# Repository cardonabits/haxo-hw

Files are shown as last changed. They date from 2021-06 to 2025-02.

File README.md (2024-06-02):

## Table of Contents

<!-- toc -->

- [What is a haxophone](#what-is-a-haxophone)
- [Project Goals](#project-goals)
  * [Goals](#goals)
  * [Non-Goals](#non-goals)
- [How does it work?](#how-does-it-work)
- [Mechanical Design](#mechanical-design)
- [Electrical Design](#electrical-design)
  * [Keyboard](#keyboard)
  * [Audio Amplifier](#audio-amplifier)
  * [Pinout](#pinout)
- [Tools/Stack](#toolsstack)
- [Software](#software)
- [Manufacturing](#manufacturing)
- [Bill of Materials](#bill-of-materials)
- [Assembly Instructions](#assembly-instructions)
- [TODO list](#todo-list)
- [License and Contributions](#license-and-contributions)
- [Acknowledgements](#acknowledgements)

<!-- tocstop -->

## What is a haxophone

A haxophone is an electronic musical instrument that resembles a saxophone.
It is designed to be an inexpensive and fully customizable travel saxophone.
You will never get the same expressiveness or depth of sound of a real
saxophone.  But with a haxophone you should be able to play alone or with
friends wherever you might be.  The mechanical keys and unique ergonomics give
it a different kind of satisfying feel.

https://user-images.githubusercontent.com/676181/133919454-f654cb48-cca9-4b6e-bcb5-27de6ea2deb8.mp4

The design is fully open, software and hardware.  This means that you can make
it your own, from changing the type of key switches to making your own note and
instrument mappings.

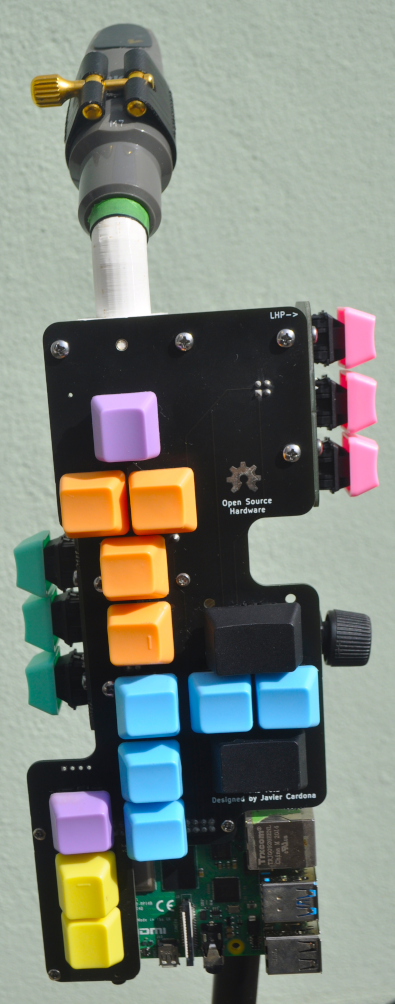
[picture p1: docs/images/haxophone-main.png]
Haxophone Prototype v0.5

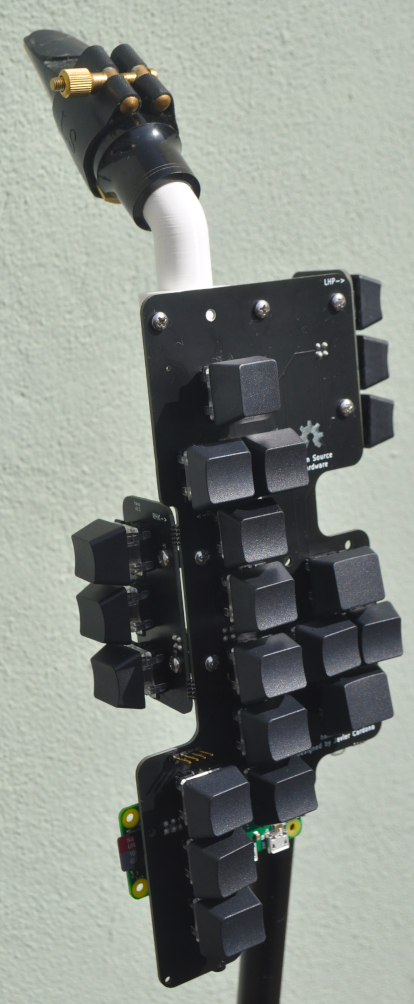
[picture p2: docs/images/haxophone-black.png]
Haxophone Prototype v0.5


## Project Goals

### Goals

1. Build a travel saxophone that is fun and satisfying to play.
2. Build an instrument with the same fingering as a saxophone so that muscle
   memory developed on the haxophone is directly transferrable to your main
horn.
3. Keep the cost low, below $100 USD.
4. Easy to manufacture.
5. Keep the design simple, sturdy and repairable to minimize maintenance cost.
   Using widely available and battle-tested mechanical keys from computer
keyboards is one example of this principle in use.
6. Fully hackable and customizable.

### Non-Goals

1. A haxophone is not designed to be a saxophone replacement.

## How does it work?

The haxophone is designed as a HAT (Hardware Attached on Top) for the Raspberry
Pi family of single-board computers.

The haxophone HAT is a special type of keyboard laid out in the same way as
saxophones are.  It also includes a mouthpiece and a pressure sensor to detect
breath intensity.  The HAT also includes an audio amplifier so it does not rely
on the amplifier that is built into the [Raspberry Pi
3](https://www.raspberrypi.org/products/raspberry-pi-3-model-b-plus/) and
[Raspberry Pi 4](https://www.raspberrypi.org/products/raspberry-pi-4-model-b/).
Because of that, the HAT will also work with the least expensive of the Pi's,
the [Raspberry Pi
Zero](https://www.raspberrypi.org/products/raspberry-pi-zero/).

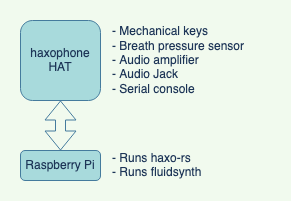
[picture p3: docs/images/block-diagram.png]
Block Diagram


The software that runs on the Raspberry Pi is:

1. [haxo-rs](https://github.com/jcard0na/haxo-rs):  This is the driver that
   detects key presses, breath and converts it into notes.  It's written in
   Rust, and compiled on the Raspberry Pi into a native application.
2. [fluidsynth](https://github.com/FluidSynth/fluidsynth):  This is the
   synthesizer software that will convert notes into sounds.

## Mechanical Design

In order to keep costs down, the HAT PCB (printed circuit board) is an integral
part of the physical structure of the Haxophone.  This means that key switches,
thumb rests, mouthpiece and the Raspberry Pi are all attached directly to the
PCB.  The side keys (left palm and right knuckle keys) are mounted on smaller
PCBs and attached to the main PCB via right angle metal brackets.  This smaller
PCBs are detachable pannels from the design.  This brings down the
manufacturing cost.

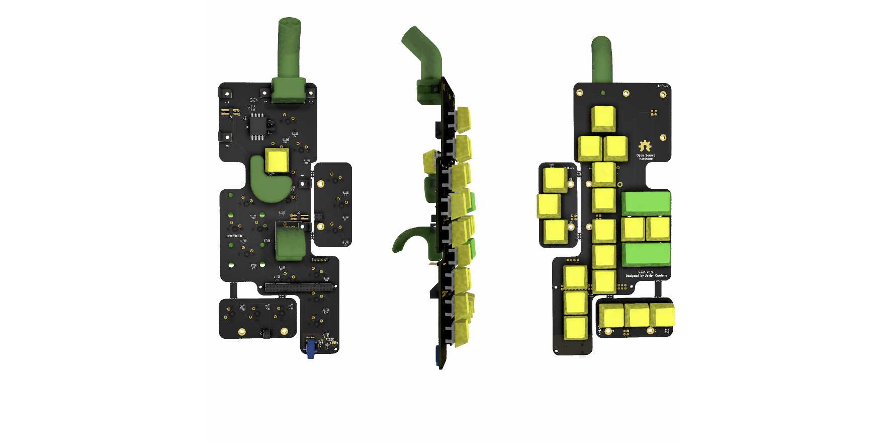
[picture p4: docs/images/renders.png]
renders


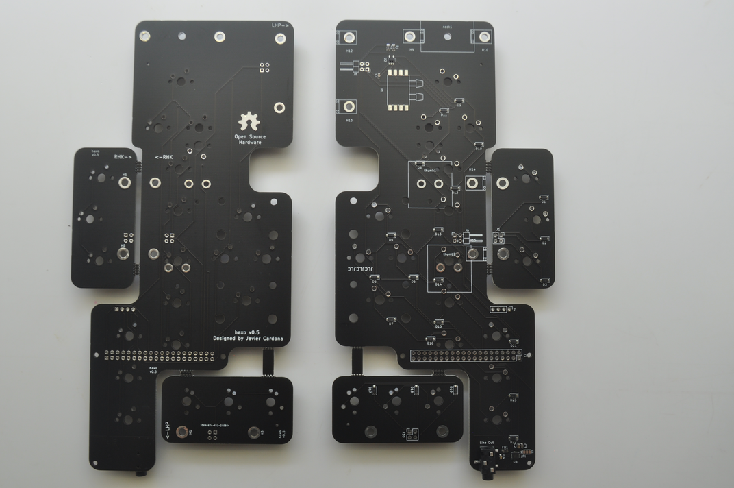
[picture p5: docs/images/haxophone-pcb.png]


For improved ergonomics, a few parts are designed to be 3D printed.  These are
the mouthpiece neck, the left thumb rest, and the right thumb rest, that also
incorporates a strap hook.  The source 3D models for those parts are included
in the repository.

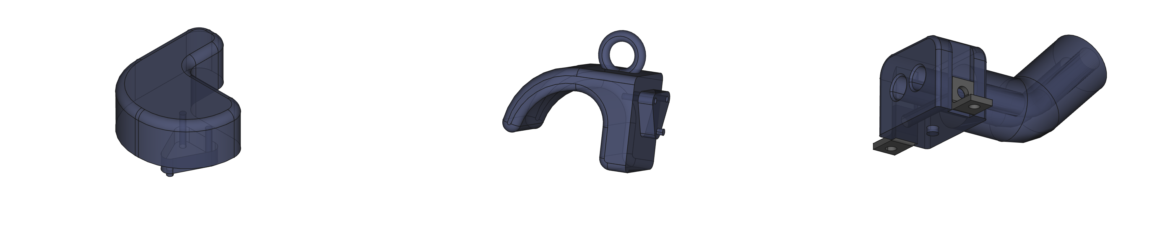
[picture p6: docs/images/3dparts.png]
3dparts


## Electrical Design

The haxophone hat is comprised of three subsystems:  a keyboard, a pressure
sensor and an audio amplifier.

### Keyboard

The keyboard is organized as a 3x8 matrix.  The diagram below shows the mapping
from saxophone keys to keyboard column/row values.

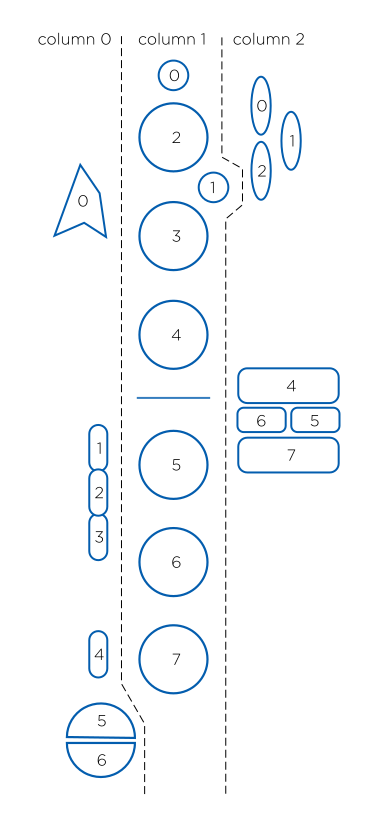
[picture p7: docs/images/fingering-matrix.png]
matrix


Note that due to PCB size constraints, a design decision was made to not
include a high F# key.  This key is not present in all saxophones, as that
note can be played using alternate fingerings with other keys.  The most common
mappings of the high F# are already configured on the haxophone.  If you are
used to a less common configuration, the software is easy to extend.

Also note that at the moment the matrix is not completely used:  keys (col 0,
row 7) and (col 2, row 3) are unused.

### Audio Amplifier

The haxophone HAT includes an audio amplifier and a 3.5mm mini-jack.  This
allows connecting the haxophone to headphones or to an external amplifier.

### Pinout

The diagram below shows how the HAT connects to the Raspberry Pi.  The keyboard
matrix uses discrete GPIOs, the pressure sensor uses I2C and the audio
amplifier, I2S.

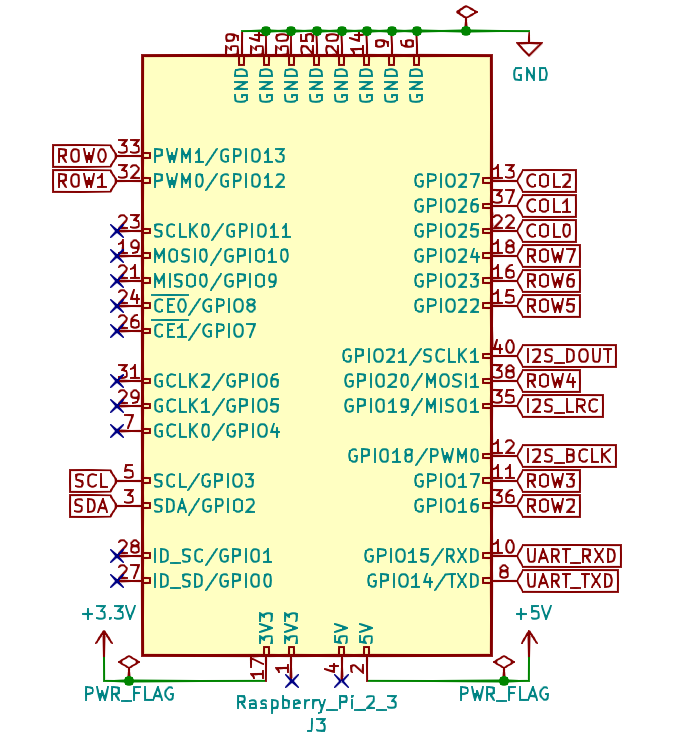
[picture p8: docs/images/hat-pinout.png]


You can refer to the diagram below from Raspberry Pi Spy if you need to locate
those pins on the Raspberry Pi header.


## Tools/Stack

The circuit board is designed with awesome [Kicad](https://www.kicad.org/).

All 3D models are designed with [Freecad](https://www.freecadweb.org/), the
open source 3D parametric modeler.

The code is written in [Rust](https://www.rust-lang.org) just for the pleasure
and reliability of it.

## Software

See [haxo-rs](https://github.com/jcard0na/haxo-rs) for details about the software that runs on all Raspberry Pis.

Alternatively, you can explore [haxo-ino](https://github.com/langeroo/haxo-ino), a port of `haxo-rs` for [RP2040 boards](https://www.waveshare.com/rp2040-pizero.htm).  When using this board the audio port of the Haxophone will be disabled and notes will only be sent out as MIDI.  However, if your intent is to use the Haxophone exclusively as a MIDI Controller, this approach has some advantages:
  * Lower USB latency: while we lack precise data, haxo-ino likely achieves better latency by not running Linux, thereby avoiding the associated USB overhead.
  * Very fast boot: `haxo-ino` boots in less than 2s, which is way faster, than `haxo-rs`, even on the fastest Pi.
  * Better connector:  the rp2040-pizero uses a type-C USB connector, which is just better than Micro USB used on the Pi's.

## Manufacturing

The circuit boards were manufactured by JLPCB, who also assembled the surface mount parts.

## Bill of Materials

The table below shows the main parts required to build a full Haxophone.  Prices are rough estimates based on purchases made for prototypes.  Shipping costs or taxes not included.

| Qty | Part Description | Manufacturer | MPN | Supplier | Estimated cost USD (at quantity 5) |
| :--- | :--- | :---: | :---: |  :---: | ---: |
| 1 | Partially-assembled Haxo HAT PCB (small SMD parts populated) | N/A | N/A | Several  | $15 |
| 1 | Differential pressure SMD sensor | NXP | MPXV7007DP | Arrow |  ~$10~ Post-Covid: $24 |
| 1 | Set of 3D printed parts | N/A | N/A | Several  | $4 |
| 1 | 30cm Food grade Silicon Tube ID:3mm/OD:6mm | JUNZHIDA | N/A | Amazon | $2 |
| 22 | Tactile-feedback 5-pin mechanical switches | Cherry MX | MX-Brown | Banggood | $11 |
| 22 | Keycaps For Mechanical Keyboards | [Many options!](https://esckeyboard.com/) |  | | $10  |
| 2 | 4-pin 0.1in Pin Header Con Right Angle | Samtec | TSW-102-25-T-D-RA | Arrow | $2 |
| 2 | 4-pin 0.1in Pin Socket Con Straight |  TE Connectivity | 215309-2 | Arrow | $2 |
| 1 | 40-pin 0.1in Pin Header Connector | TE Connectivity | 2-535542-0 |  Arrow | $2 |
| 6 | Mounting Bracket L-shape | Keystone | 612 | Mouser | $1.5 |
| 18 | 4-40 1/4 screws and nuts stainless | Keystone | 9900, 4694 | Mouser | $1 |
| 4 | M2/7mm machine screws flat head stainless | Master-Carr | 92010A003 | Master-Carr | $0.5 |
| 3 | 7/16in aluminum spacers | Fascomp | FC1636-440-A | Mouser | $1 |
| 1 | Sax Mouthpiece + Reed | N/A | N/A | N/A | Bring your own (but optional) |
| 1 | Neck Strap | N/A | N/A | N/A | Bring your own (but optional) |
| 1 | Raspberry Pi Zero | Broadcom | Raspberry Pi Zero | Many | $5 |
| 1 | 16 GB SD Card | Many | N/A | Many | $6 |
| ~**Total**~ | | | | | ~**$73**~ (Pre-Covid) |
| **Total** | | | | | **$97** (Post-Covid) |

## Assembly Instructions

See [Assembly Guide](docs/assembly.md)

## TODO list

If you would like to help claim one of [the open issues](https://github.com/jcard0na/haxo-hw/issues) or [create a new one](https://github.com/jcard0na/haxo-hw/issues/new/choose) for yourself.
If you prefer to stay in software land, head out to [the software issues](https://github.com/jcard0na/haxo-rs/issues).

## License and Contributions

See [License](LICENSE).
We'll gladly accept contributions via Pull Requests.  Contributions are
accepted under the same [License](LICENSE) of the project, as captured in
[github's terms of
service](https://docs.github.com/en/github/site-policy/github-terms-of-service#6-contributions-under-repository-license).

If you plan to contribute a major feature or improvement, consider posting your proposed design as an issue before implementing it.

## Acknowledgements

[Ben Gonzales](https://gonzos.net/projects) has been a great source of inspiration and encouragement.  His [midi-Sax](https://gonzos.net/projects/midi-wind-controller-building-my-own/) is a great project worth checking out.

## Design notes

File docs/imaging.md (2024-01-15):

# How to copy a Haxophone image onto an SD Card

If you want the latest and greatest bleeding edge features on your haxophone, you will probably want to build [the software](https://github.com/cardonabits/haxo-rs) yourself.  But some of you just want to get up and running fast.  And for that, we have released Raspberry Pi images with the haxophone application pre-installed.

## Obtain the image

You will find those images at the links below:

* [Raspberry Pi Zero](https://bit.ly/haxo-rpiz)
* [Raspberry Pi Zero 2](https://bit.ly/haxo-rpiz2)
* [Raspberry Pi 3](https://bit.ly/haxo-rpi3)
* [Raspberry Pi 4](https://bit.ly/haxo-rpi4)

## Check the Image (Optional)

Some images (at the moment the Zero and the Zero 2) are zipped and contain a sha256 signature.  This is how you can check the integrity of the image you downloaded.

```
$ unzip haxophone-rpiz2.img.zip 
Archive:  haxophone-rpiz2.img.zip
  inflating: haxophone-rpiz2.img     
  inflating: haxophone-rpiz2.img.sha256  
$ sha256sum -c haxophone-rpiz2.img.sha256 
haxophone-rpiz2.img: OK
```

That OK means the image in your disk matches what was originally released.

## Obtain an SD Card

The images are generated from 16 GB SD cards.  You should be able to flash onto
bigger cards without any modifications.  Smaller cards can also work, but that
will require resizing partitions and other voodoo that's outside the scope of
this guide.

## Flash the image

You can use any image flashing command to copy the image onto your SD card, from [`dd`](https://man7.org/linux/man-pages/man1/dd.1.html), to any disk utility on [Linux](https://gitlab.gnome.org/GNOME/gnome-disk-utility), [Mac](https://support.apple.com/guide/disk-utility/welcome/mac) or [Windows](https://learn.microsoft.com/en-us/windows-server/administration/windows-commands/diskpart)

The folks at Raspberry Pi have released their own SD card imaging tool that can be use for this as well.  The advantage of their tool is that it runs on all three major Operating Systems with the same UI.

To use it, first download and install Raspberry Pi Imager [from here](https://www.raspberrypi.com/software/).

Then, under `Operating System`, select `Custom Image`, then select the `.img` file you downloaded.
Click on `Choose Storage` and pick your SD Card

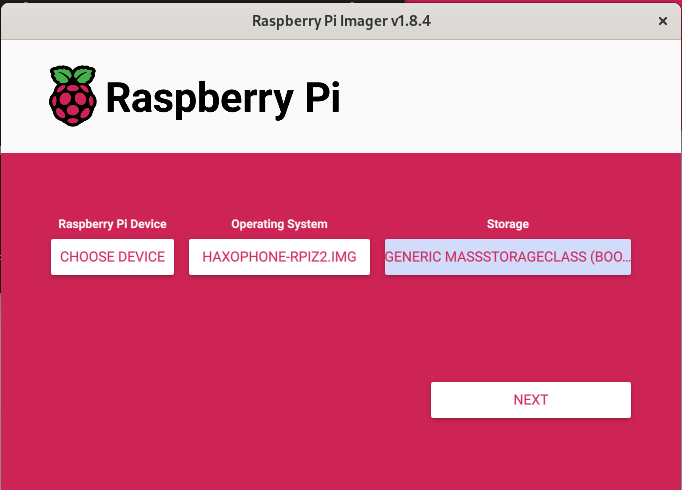
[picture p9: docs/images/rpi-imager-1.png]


Say `No` to any customisations.  **This is important:  your SD Card will not boot correctly if you apply customisations** ([#57](https://github.com/cardonabits/haxo-hw/discussions/59))

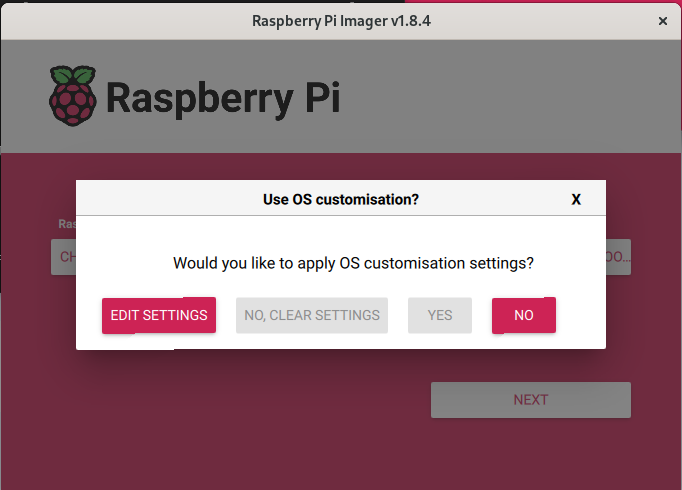
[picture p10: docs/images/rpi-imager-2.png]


Once complete, extract the SD Card.

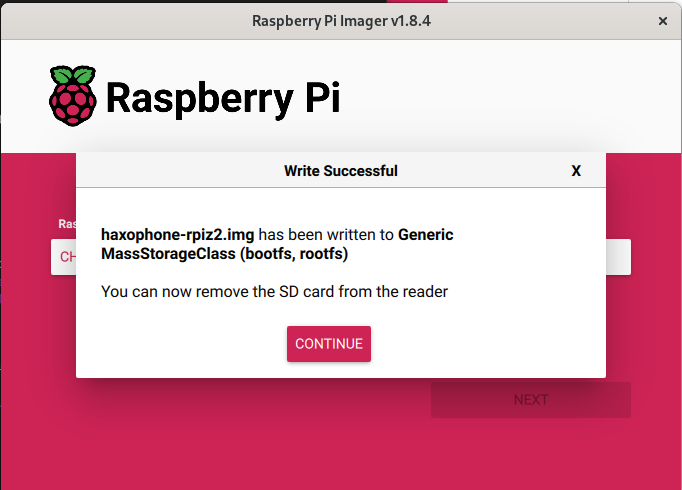
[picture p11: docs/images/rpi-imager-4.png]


If you want to troubleshoot and look at logs, take a look at [how to log into the haxophone](./login.md)

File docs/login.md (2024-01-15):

# Log into your Haxophone

Your haxophone runs on Linux, and sometimes it is necessary (or fun) to just poke inside.
For that you will need to log into your system.  There are three supported ways to do so.

## Monitor and Keyboard

This is probably the method people are most familiar with:  attach a monitor to
the HDMI port of the haxophone, a USB keyboard, and you are in.  On the Zeros,
this normally requires a micro-USB to USB adapter.  This is not the most
portable setup, as not everyone carries a monitor in their pocket.  For more
nimble solutions, keep reading.

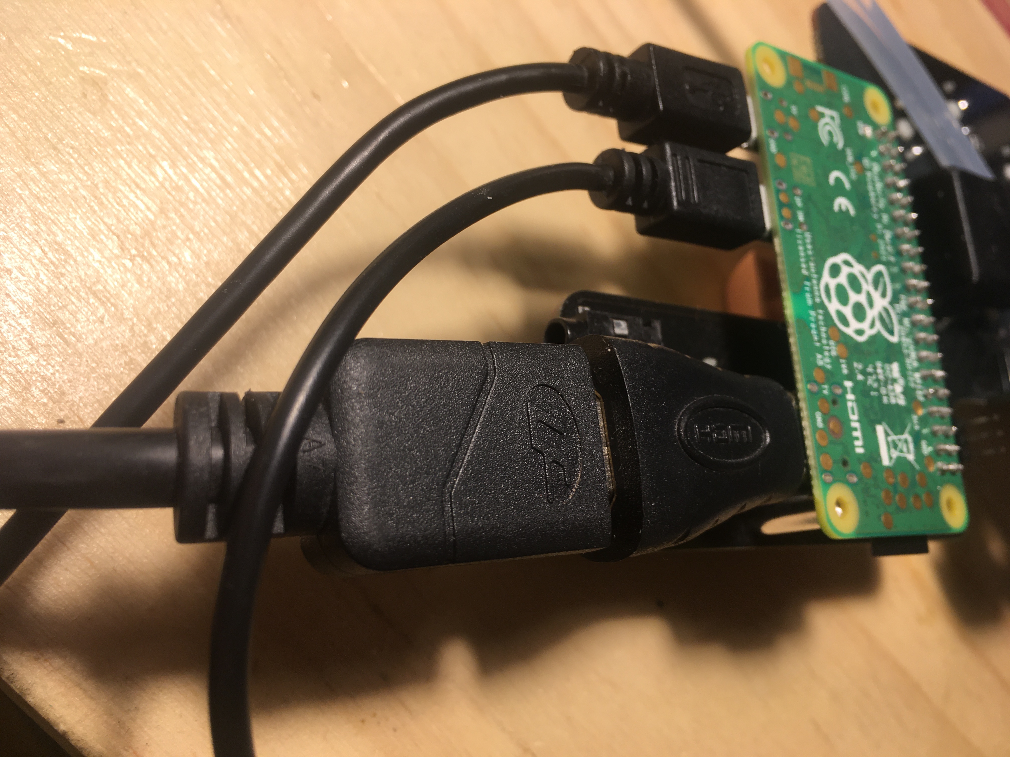
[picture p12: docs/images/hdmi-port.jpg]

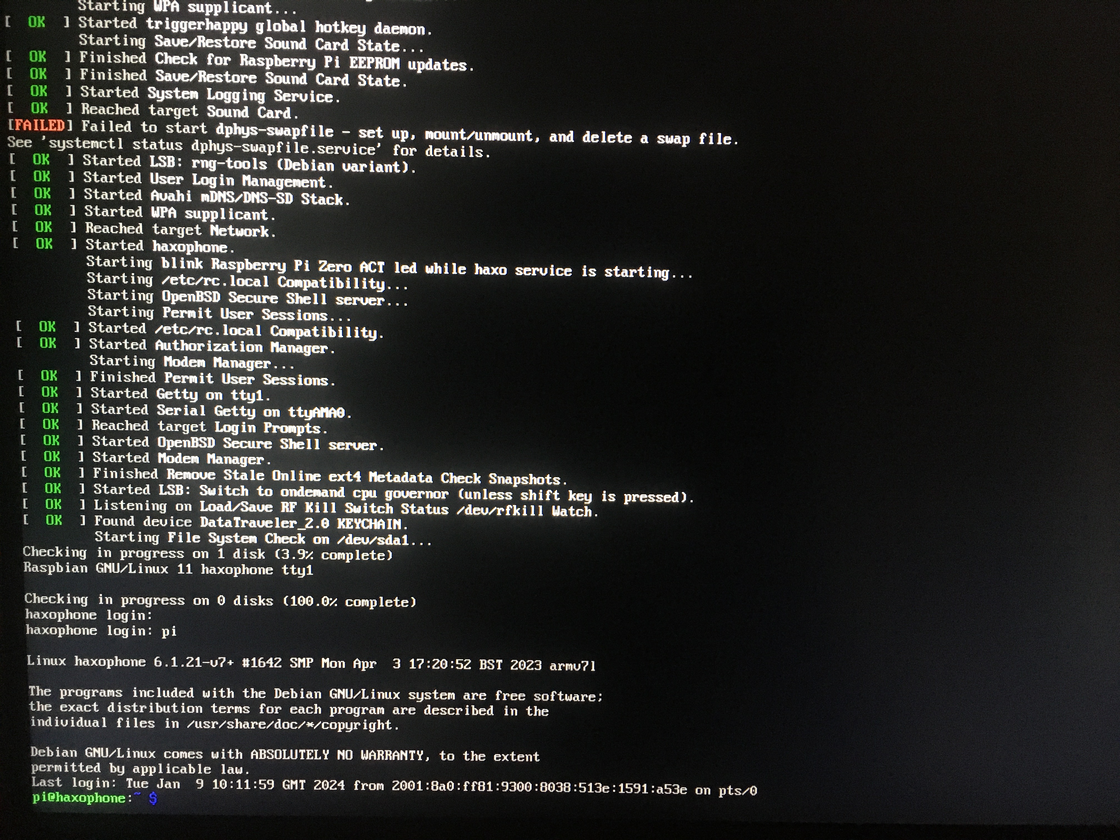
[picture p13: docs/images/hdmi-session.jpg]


## Serial Port

This requires a USB to 3.3V TTL adapter.  The most popular brand is
[FTDI](https://ftdichip.com/products/ttl-232r-3v3/), but there are many other
alternatives you can use.  

The Haxophone has a 3-pin header that exposes the Raspberry Pi serial port.
The pinout matches that of the Raspberry Pi header, so if you prepare a cable
for the Haxophone, you can also use it to connect directly to any Raspberry Pi.

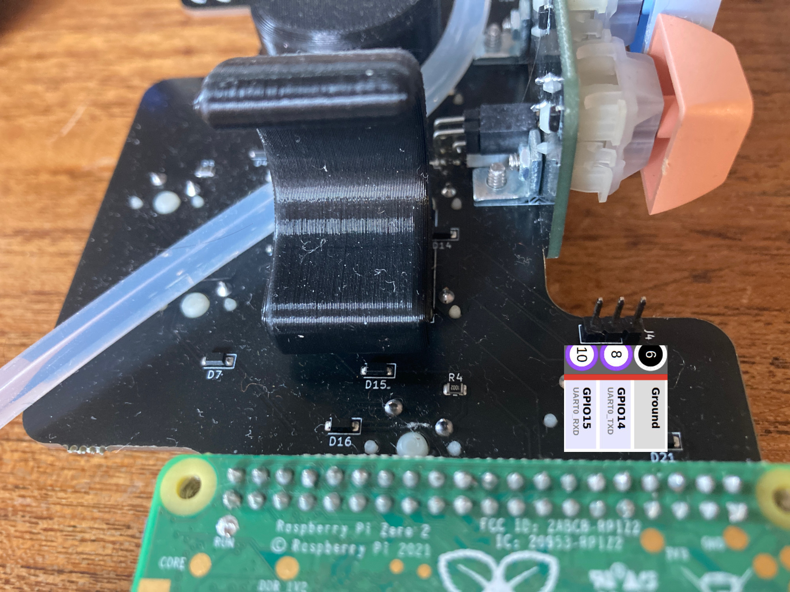
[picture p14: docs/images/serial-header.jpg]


You need to connect your cable's TxD to the Raspberry Pi RxD and your cable's
RxD to the Rasperry Pi TxD.  If you are using an FTDI cable, this is how the
colors line up.

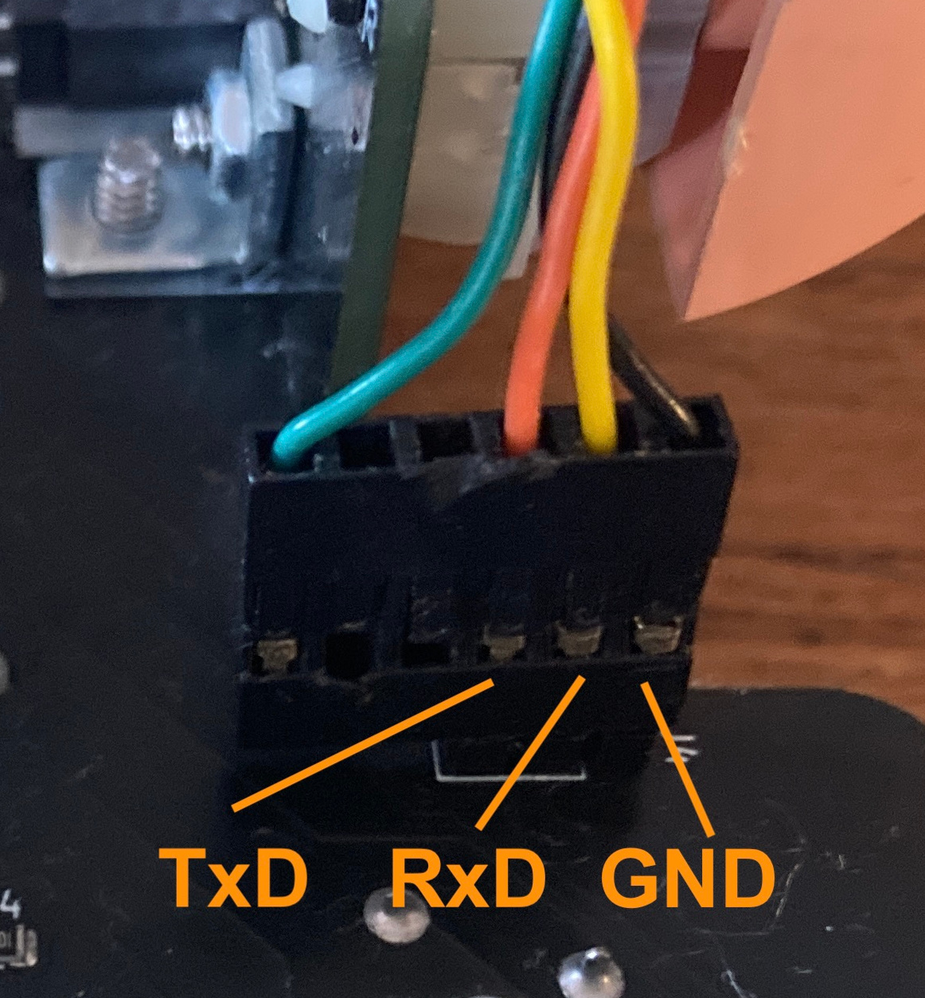
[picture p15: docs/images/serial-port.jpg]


Once you do that, you can use a serial terminal program to connect.  For instance, `minicom`.

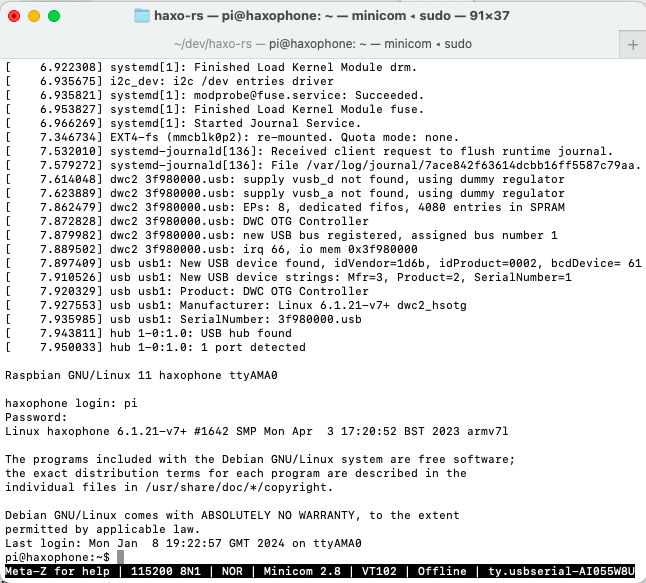
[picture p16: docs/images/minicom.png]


## SSH over Ethernet

The default Haxophone images have WiFi disabled for performance.  WiFi activity
can introduce delays that affect latency while playing.  For that reason, to
connect over SSH, you would need to use Ethernet.  On the Rapsberry Pi Zero,
this means that you will need a serial to Ethernet adapter.

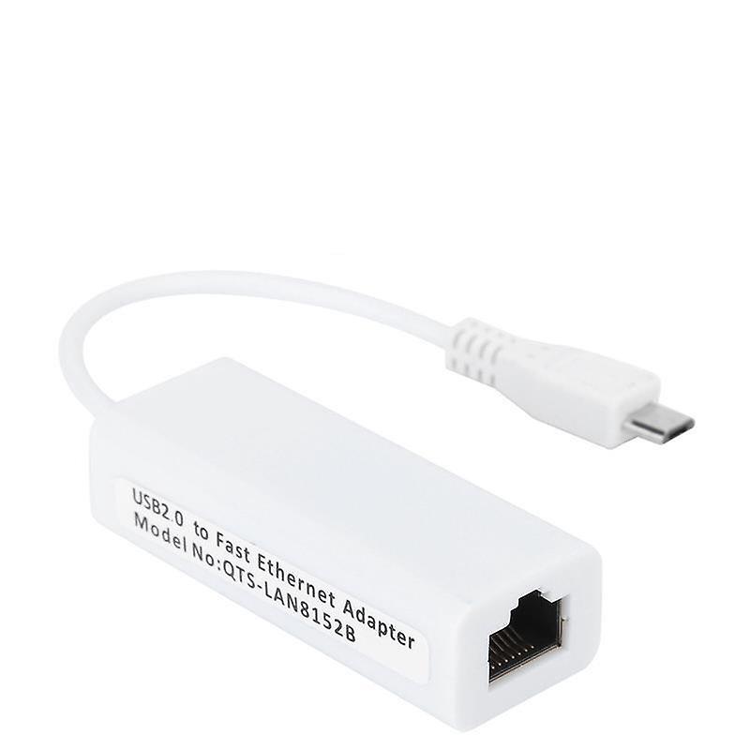
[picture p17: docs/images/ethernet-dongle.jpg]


The haxophone images are configured with username `pi`, password `haxophone` and they will appear on your local network as `haxophone.local`.

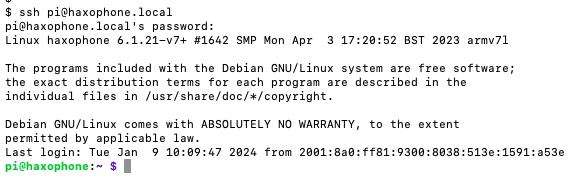
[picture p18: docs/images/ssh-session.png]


## Checking the logs

Probably the most important log that you want to check is the one for the haxophone service.
You can do that with the command `journalctl -u haxo`.  See below for the expected output:

```
pi@haxophone:~ $ journalctl -u haxo
-- Boot 9ecd1d956b6448adb9348f40065fbd4f --
Jan 05 22:38:47 haxophone systemd[1]: Started haxophone.
Jan 05 22:38:52 haxophone create_midi_gadget.sh[468]: created usb midi gadget
Jan 05 22:38:52 haxophone haxo001[570]: fluidsynth: warning: SDL2 not initialized, SDL2 audio driver won't be usable
Jan 05 22:38:52 haxophone haxo001[570]: [2024-01-05T22:38:52Z INFO  haxo001::alsa] Found alsa card MAX98357A
Jan 05 22:39:01 haxophone haxo001[570]: Synth created
Jan 05 22:39:02 haxophone haxo001[570]: [2024-01-05T22:39:02Z INFO  haxo001::midi]
Jan 05 22:39:02 haxophone haxo001[570]:     Available output ports:
Jan 05 22:39:02 haxophone haxo001[570]: [2024-01-05T22:39:02Z INFO  haxo001::midi] 0: Midi Through:Midi Through Port->
Jan 05 22:39:02 haxophone haxo001[570]: [2024-01-05T22:39:02Z INFO  haxo001::midi] 1: f_midi:f_midi 24:0
Jan 05 22:39:02 haxophone haxo001[570]: [2024-01-05T22:39:02Z INFO  haxo001::midi] Picked the last one
Jan 05 22:39:02 haxophone haxo001[570]: Starting haxophone (version 2493652)...
```

## Conclusion

How many other instruments give you so many ways to peek inside see their internals? You should dive in! 🤿

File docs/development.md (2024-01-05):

# Development Environment

## Contents

<!-- toc -->

- [Introduction](#introduction)
- [Setup](#setup)
- [Hardware](#hardware)
- [Initial Configuration](#initial-configuration)
- [Compilation Method 1: Native Compilation on the Raspi](#compilation-method-1-native-compilation-on-the-raspi)
- [Compilation Method 2: Cross-compilation on your computer](#compilation-method-2-cross-compilation-on-your-computer)
  * [Normal cross-compilation](#normal-cross-compilation)
  * [Cross-compilation with `cross` [BROKEN]](#cross-compilation-with-cross-broken)
- [Installation and launch](#installation-and-launch)
- [Logs](#logs)

<!-- tocstop -->

## Introduction

If you want to modify the software that runs on a Haxophone, you will need to
setup a development environment.  There are many different options on how to do
that, here I document a few different approaches I tried with different levels
of success.

## Setup

The first step is that you will need a way to connect your Raspberry Pi to your computer.

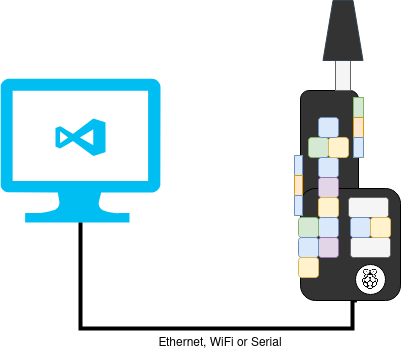
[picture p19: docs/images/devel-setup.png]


On the Raspberry Pi 3/4, this can be Wi-Fi or Ethernet.  On the Pi Zero W,
Wi-Fi.  On the Pi Zero, you will need an USB network adapter.  

If you don't have a network around, you can also use a serial console.  The
Haxophone HAT exposes the serial console signals on connector J4.  The pins
match the same pinout as pins 6,8,10 on the Raspberry Pi Header.  So, if you
had a tty serial cable that worked on the PI, it will also work on the J4
connector when the HAT is attached.  Note that the [serial console will not
work if Bluetooth is enabled on the
Raspi](https://di-marco.net/blog/it/2020-06-06-raspberry_pi_3_4_and_0_w_serial_port_usage/),
so you *probably do not want to use the serial console afterall*.

For the next sections, we will assume that you are able to get a Linux prompt
on the Raspberry Pi.  For additional help, you can refer to [Raspberry Pi
documentation](https://www.raspberrypi.com/documentation/computers/remote-access.html)

## Hardware

Highly recommended:  use a USB drive for your development and keep your SD Card
read-only most of the time.

## Initial Configuration

1. Flash [image onto Raspberry Pi](https://www.raspberrypi.com/news/raspberry-pi-imager-imaging-utility/).  For faster boot, use the Lite version of the OS (no graphical environment)
2. Pick SSH password.
3. Pick a network-unique hostname (`/etc/hostname`).
4. On raspi-config, enable: `ssh`, `I2C` and (optional) `serial console`
5. [RP Zero Only] Enable device-mode USB driver  (edit `/boot/config.txt` to add)
   ```
   [all]
   dtoverlay=dwc2
   ```
   and add `dwc2` to `/etc/modules`
6. Enable audio card (edit `/boot/config.txt` to add)
    ```
    # dtparam=audio=on
    dtoverlay=max98357a,sdmode-pin=4
    ```
7. Optionally, disable Wifi and Bluetooth.  This seems to improve performance on the RPI Zero.
   ```
   dtoverlay=disable-wifi
   dtoverlay=disable-bt
   ```
9. Speed up I2C (edit `/boot/config.txt` to add)
    ```
    dtparam=i2c_arm_baudrate=400000
    ```
10. Install project dependencies
    ```
    apt install libfluidsynth-dev git libasound2-dev i2c-tools fluid-soundfont-gm
    ```
11. Install latest stable Rust
    ```
    curl --proto '=https' --tlsv1.2 -sSf https://sh.rustup.rs | sh
    ```

    Note 1: On Raspberry Pi 4 rustup might detect an incorrect architecture.  The RPi 3/4 can run in 32-bit or 64-bit.
    Check `uname -m` to see whether you are running `aarch64` or `armv7l`.  If the later, when installing rust:
    ```
    Current installation options:

    default host triple: aarch64-unknown-linux-gnu
    This is incorrect --------^^^^^^^
    ```

    To fix, pick '2. Customize installation' and set host to:
    ```
    arm-unknown-linux-gnueabihf
    ```
    See [this issue](https://github.com/rust-lang/rustup/issues/3342).

    Note 2: On Pi Zeros you might need to increase the size of the swap file or else the installation will be killed by insufficient ram.  You do this by:
    ```
    sudo dphys-swapfile swapoff
    sudo vi /etc/dphys-swapfile
    # Change CONF_SWAPSIZE=100 to CONF_SWAPSIZE=512
    sudo dphys-swapfile setup
    sudo dphys-swapfile swapon
    reboot
    ```
13. Automount USB drive, if attached
    ```
    sudo mkdir /media/usb
    # for FAT32 formatted drive
    echo '/dev/sda1       /media/usb        vfat    defaults,nofail,uid=1000,gid=1000        0 2' >> /etc/fstab
    # for Linux formatted drive
    echo '/dev/sda1       /media/usb        ext4    defaults,nofail        0 2' >> /etc/fstab         
    ```

    Gotcha: If you created the USB partition with e2fsck 1.47, you might encounter [this problem](https://github.com/NixOS/nixpkgs/issues/229450#issuecomment-1616324269).  Avoid it by creating your partition from Raspberry Pi (e.g. `sudo mkfs -t ext4 /dev/sda1`)

14. [If using VSCode] Connect via VSCode over ssh to target.  This will create folder `/home/pi/.vscode-server`. Move that folder to `/media/usb/`

15. [If using VSCode] Symlink `.vscode-server` directory to USB drive.
    ```
    ln -sf /media/usb/.vscode-server /home/pi
    ```
    (This is a workaround for VSCode [issue that requires a writable directory under the user's home directory](https://github.com/microsoft/vscode-remote-release/issues/472)).

16. [Highly recommended] Make SD Card read-only

    The SD Card may get corrupted if the Raspberry PI is unplugged while a
    write operation is in progress.  In normal operation, one cannot know if a
    write is happening before powering off, so a radical solution is to forbid
    all writes.  You can do this easily from `raspi-config`:

    ```
    sudo raspi-config
    Performance Options -> Overlay Filesystem -> Enable Overlay? Yes -> Make Boot Filesystem Writeable? Yes
    ```
    The overlay filesystem will make your root filesystem writable but only in
    a non-persistent way.  In other words, you may write files to, say, `/home/pi`,
    but they will disappear after a reboot.

    Reverse this steps if you need to make the filesystem writable again, for
    instance if you need to copy new versions of `haxo001` to the root fs or
    install new packages.

## Compilation Method 1: Native Compilation on the Raspi 

This works very well on a Raspberry Pi 3 and 4, but it is very slow on the Pi Zero.
If you configured the Raspberry Pi image as described in the previous section,
compilation is easy:

1. Insert a USB drive and reboot.  It should auto-mount under `/media/usb`
2. Install keys (under `/media/usb`, not the SD card) and load them
   ```
   ssh-agent bash
   ssh-add id_ed25519
   ```
3. Clone `haxo-rs` on the USB drive
    ```
    cd /media/usb
    git clone git@github.com:cardonabits/haxo-rs.git
    ```
4. If you plan to make changes to the code and submit pull requests, configure `git`
    ```
    cd haxo-rs
    git config --local user.email my@email.com
    git config --local user.name "My Name"
    git config --local core.editor vim
    ```
5. Compile
    ```
    cargo build --release
    ```
6. Only one `haxo` daemon can be running at a time.  Before running your build,
   you might need to stop the pre-installed daemon if it was launched at boot.
    ```
   systemctl stop haxo
   ```
7. Run the tests
   ```
   cargo test -- --test-threads=1
   ```

8. [Optional] Run the interactive tests
   ```
   cargo test all_keys -- --nocapture --ignored
   ```

## Compilation Method 2: Cross-compilation on your computer

With this method, we will cross-compile binaries.  This means, you will compile
on your laptop binary executables for a different architecture.  This method is
recommended if you are building images for the Pi Zero, as native compilation
is too slow.

### Normal cross-compilation

The process outlined
[here](https://chacin.dev/blog/cross-compiling-rust-for-the-raspberry-pi/), but
I mostly develop on the Pi 4, so native compilation for me is preferred.

### Cross-compilation with `cross` [BROKEN]

By using a Docker container we can run this method without having to install
special packages on your system.  It will also work independently of your
Operating System.

Using [cross](https://github.com/rust-embedded/cross), build haxo-rs for target `arm-unknown-linux-gnueabihf`
You first need to create a container with `libfluidsynth` installed and add lib
path to `build.rs`.  But compilation fails due to uresolved symbols provided by
fluidsynth dependent shared libs

Also a problem: `cross` has [an issue with targetting the Pi zero](https://github.com/rust-embedded/cross/issues/426)

## Installation and launch

The `haxo` daemon is launched by systemd.  If you need to install a new version, you need to copy the binary to where systemd expects it.

1. Disable overlay (if previously enabled)
2. Copy `target/release/haxo001` to `/usr/local/bin/haxo001`
3. Install systemctl service files
    ```
    cd scripts/systemd
    sudo ./install.sh
    ```
4. Re-enable overlay

If you need to modify how systemd launches the `haxo` daemon, you will need to
edit `/etc/systemd/system/haxo.service`:

```
[Unit]
Description=haxophone
After=network.target
StartLimitIntervalSec=0

[Service]
Type=idle
Restart=always
RestartSec=1
User=root
Group=audio
WorkingDir=/usr/share/haxo
Environment=RUST_LOG=info
ExecStart=/usr/local/bin/haxo001 \
          --notemap-file /usr/share/haxo/notemap.json \
          --bank-number 66 \
          --sf2-file /usr/share/sounds/sf2/TimGM6mb.sf2

[Install]
WantedBy=multi-user.target
```

## Logs
You can inspect logs with
```
journalctl -u haxo
Oct 11 17:11:17 raspberrypi-one haxo001[641]: Synth created
Oct 11 17:11:17 raspberrypi-one haxo001[641]: Starting haxophone...
```

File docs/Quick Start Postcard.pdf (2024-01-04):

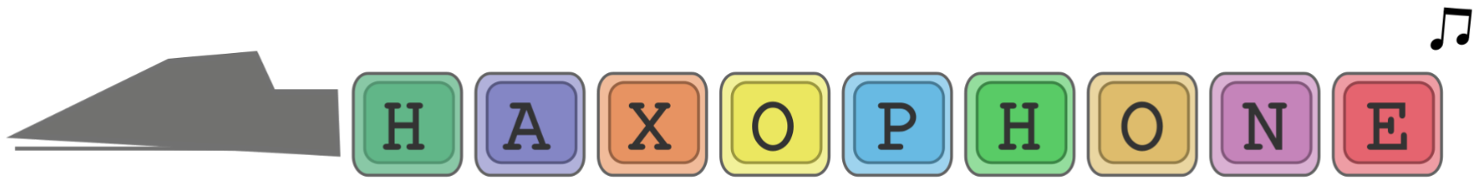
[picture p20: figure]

# Quick Start Guide

1. Download Software Image
Raspberry Pi Zero/Zero W: https://bit.ly/haxo-rpiz Raspberry Pi 4: https://bit.ly/haxo-rpi4
Raspberry Pi 3: https://bit.ly/haxo-rpi3
2. Download Raspberry Pi Imager from here: https://www.raspberrypi.com/software/
3. Use Raspberry Pi Imager software to copy the software image onto a 16 GB SD Card
4. Insert SD Card into Raspberry Pi
5. Attach Raspberry Pi to Haxophone
6. Optionally attach a mouthpiece. You may use the attached washi tape roll to adjust the neck diameter to your mouthpiece.
6. Power Up and wait for the LED to stop blinking (about 1 minute)
7. Play!

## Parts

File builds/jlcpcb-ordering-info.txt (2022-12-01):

PCB Product Detail
==================

Gerber file: haxophone001-1.0_Y64
Build Time: 3 days
Base Material: FR-4
Layers: 2
Dimension: 102.36 mm* 207.26 mm
PCB Qty: 5
Product Type: Industrial/Consumer electronics
Different Design: 3
Delivery Format: Panel by Customer
PCB Thickness: 1.6
Impedance Control: no
PCB Color: Black
Silkscreen: White
Via Covering: Tented
Surface Finish: LeadFree HASL
Deburring/Edge rounding: No
Outer Copper Weight: 1
Gold Fingers: No
Flying Probe Test:Fully Test
Castellated Holes:no
Remove Order Number:No
4-Wire Kelvin Test:No
Material Type:FR4-Standard TG 135-140
Paper between PCBs:No
Appearance Quality:IPC Class 2 Standard
Confirm Production file:Yes
Silkscreen Technology:Ink-jet/Screen Printing Silkscreen
X-out board:Accept
Package Box:With JLCPCB logo
Date: Dec 1 2022
PCB price (qty 5): 20.71 EUR (excl. shipping + tax)

Assembly Detail
===============

Bottom Side
PCBA QTY: 5
Tooling holes: Added by JLCPCB
Confirm Parts Placement：Yes
File provided as: Complete File, just proceed with my own files
Panel Format: 1*1
Assembyl + Parts price (qty 5): 189.79 EUR (excl. shipping + tax)

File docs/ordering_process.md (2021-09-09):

## Preparing fabrication files for JLCPCB

To prepare files for JLCPBC

1. Generate BOM from kicad
  1. (One time) Add BOM plugin from `scripts/bom2grouped\_jlcpcb.xsl` to kicad BOM tool.
  2. Use that plugin to generate BOM.  This will have JLCPCB part numbers.
2. Generate gerbers from kicad
3. Generate position files from kicad, *in CSV format*
  1. Post-process `haxophone001-bottom-pos.csv` with  `scripts/jlcpcb-pos-csp-process.sh` to make it JLCPCB compatible.  Only the bottom position file is needed as only the bottom side of the PCB is populated.
4. Zip the `gerbers` directory.

The files required to place the order are:

1. zipped gerbers
2. BOM file: `haxophone001.csv`
3. CPL file: `haxophone001-bottom-pos.csv`

Also, in the order form, set 'Different Designs' to 3.
Also, pick LeadFree or ENIG Surface Finishes.

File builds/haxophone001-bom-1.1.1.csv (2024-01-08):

Comment | Designator | Footprint | LCSC
470pF | C1 | Capacitor_SMD:C_0603_1608Metric | C1620
0.1uF | C2 | Capacitor_SMD:C_0603_1608Metric | C28323
10uF | C3 | Capacitor_SMD:C_0603_1608Metric | C96446
220pF | C4 | Capacitor_SMD:C_0603_1608Metric | C1603
D_Small | D1,D2,D3,D4,D5,D6,D7,D8,D9,D10,D11,D12,D13,D14,D15,D16,D17,D18,D19,D21,D22,D23 | Diode_SMD:D_SOD-123 | C8598
600 | FB1 | Inductor_SMD:L_0805_2012Metric | C1017
Raspberry_Pi_2_3 | J3 | Connector_PinSocket_2.54mm:PinSocket_2x20_P2.54mm_Vertical | C132132
Conn_01x03_Male | J4 | Connector_PinHeader_2.54mm:PinHeader_1x03_P2.54mm_Vertical
Line Out | J5 | haxo001:C18594 | C18594
4.7K | R1,R2 | Resistor_SMD:R_0805_2012Metric_Pad1.20x1.40mm_HandSolder | C17673
10K | R3,R4,R5 | Resistor_SMD:R_0805_2012Metric | C17414
MCP3221 | U2 | Package_TO_SOT_SMD:SOT-23-5_HandSoldering | C36310
MAX98357 | U4 | Package_DFN_QFN:TQFN-16-1EP_3x3mm_P0.5mm_EP1.23x1.23mm_ThermalVias | C910544

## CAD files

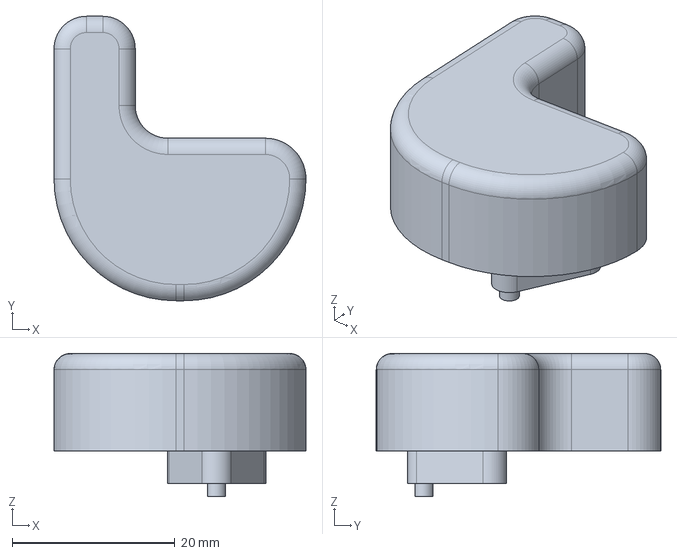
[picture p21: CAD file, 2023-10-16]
models/octave_rest.FCStd
31.0 x 35.0 x 17.6 mm

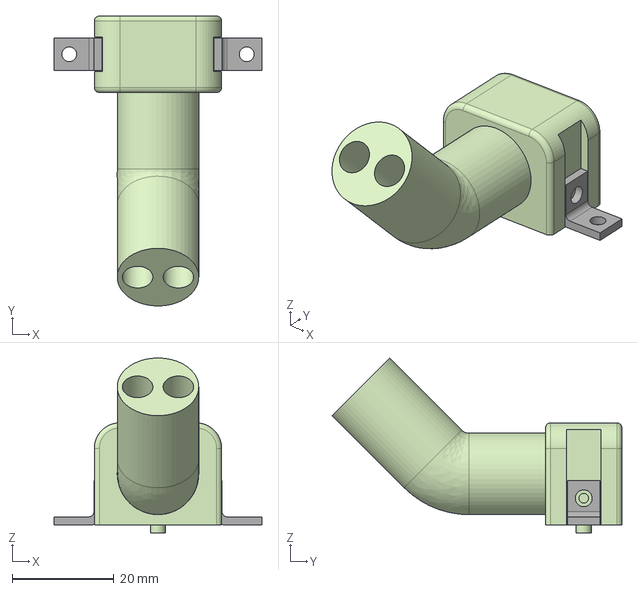
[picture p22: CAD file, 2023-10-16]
models/neck.FCStd
40.8 x 56.9 x 34.3 mm
lbracket x 2
neck001

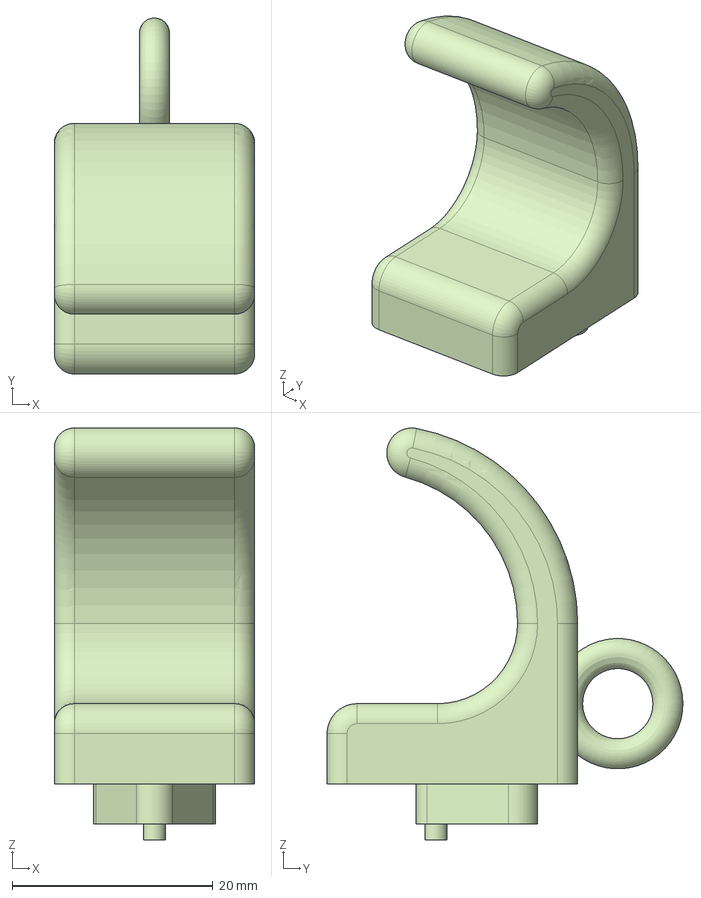
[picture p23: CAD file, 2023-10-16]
models/hook_rest.FCStd
20.0 x 35.5 x 41.1 mm

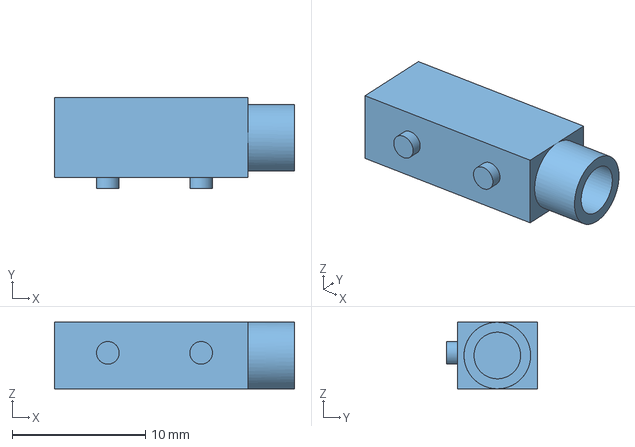
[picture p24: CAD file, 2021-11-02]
models/PJ-3280-B-SMT-Part.step
18.0 x 6.80 x 5.00 mm

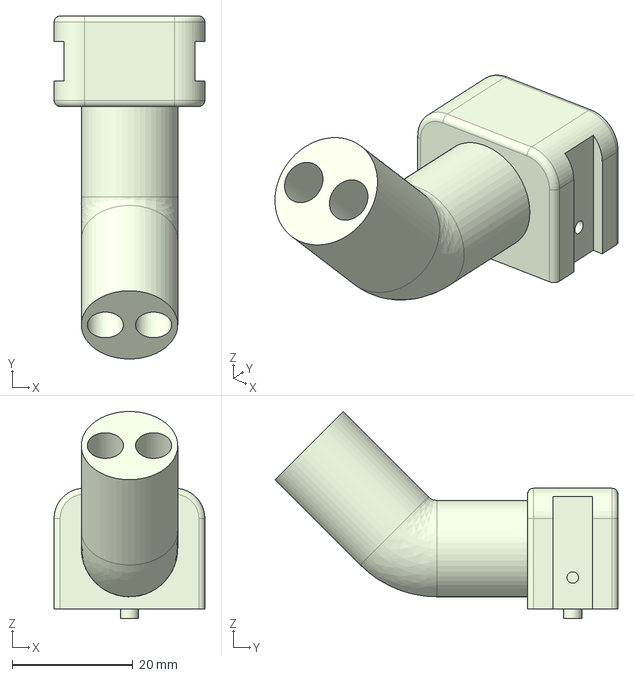
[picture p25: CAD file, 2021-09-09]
models/neck-neck.step
25.0 x 56.9 x 34.3 mm

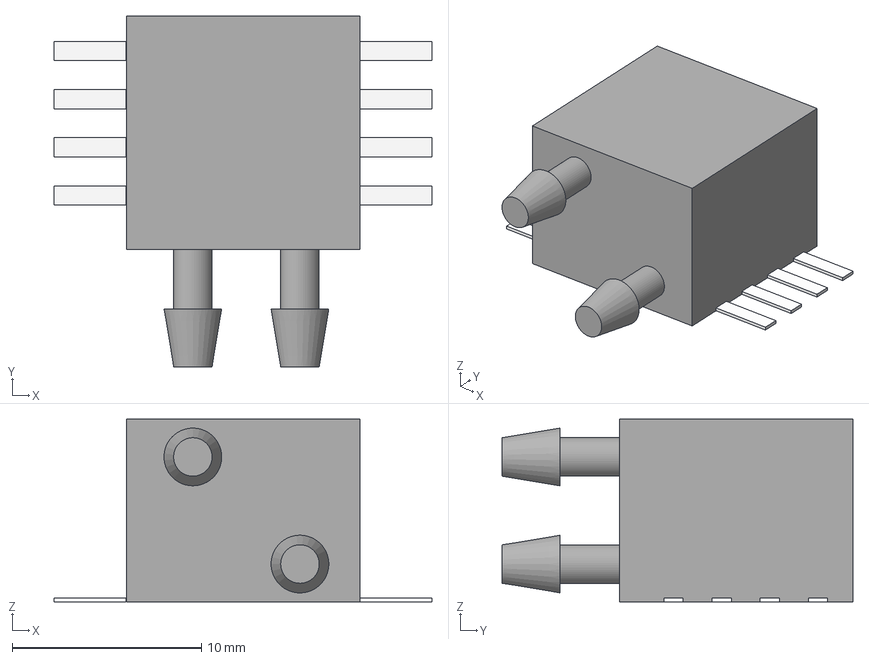
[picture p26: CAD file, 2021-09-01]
models/mpxv7007-Part.step
19.9 x 18.5 x 9.65 mm
Pads

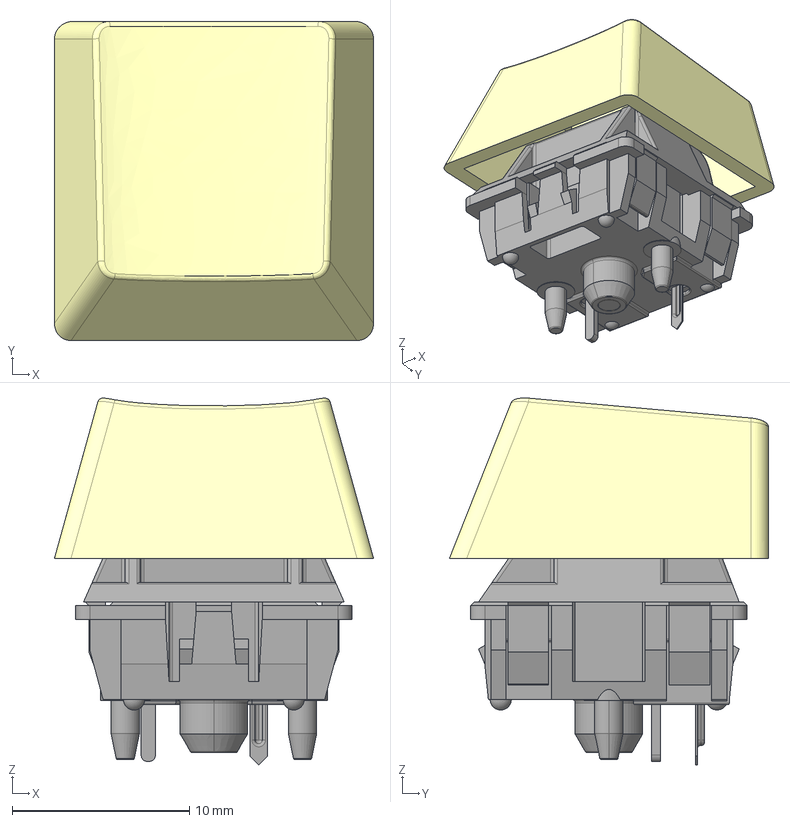
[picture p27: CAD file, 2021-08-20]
models/cherry-mx-with-keycap.FCStd
18.0 x 18.0 x 20.7 mm
SW_Cherry_MX_PCB_cp
1x1 R2 v8

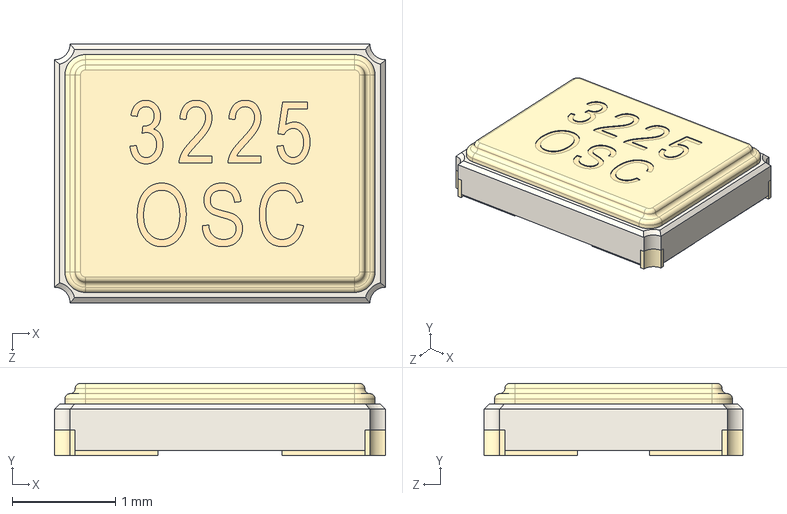
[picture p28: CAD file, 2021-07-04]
models/3225 SMD Crystal Oscillator.STEP
3.20 x 0.7 x 2.50 mm

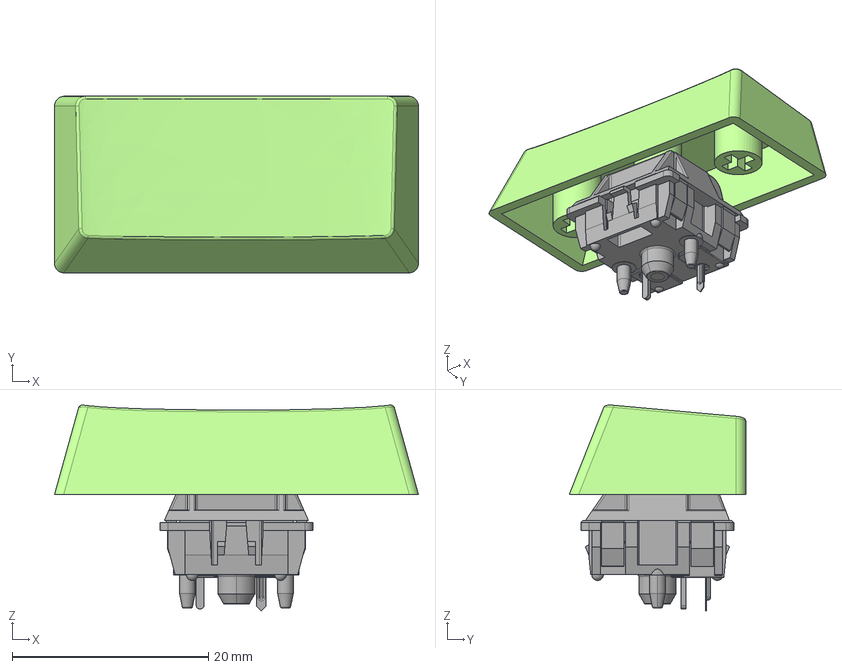
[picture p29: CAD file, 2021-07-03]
models/cherry-mx-with-2U-keycap.FCStd
37.1 x 18.0 x 21.0 mm
SW_Cherry_MX_PCB_cp
1x2 R2 v6

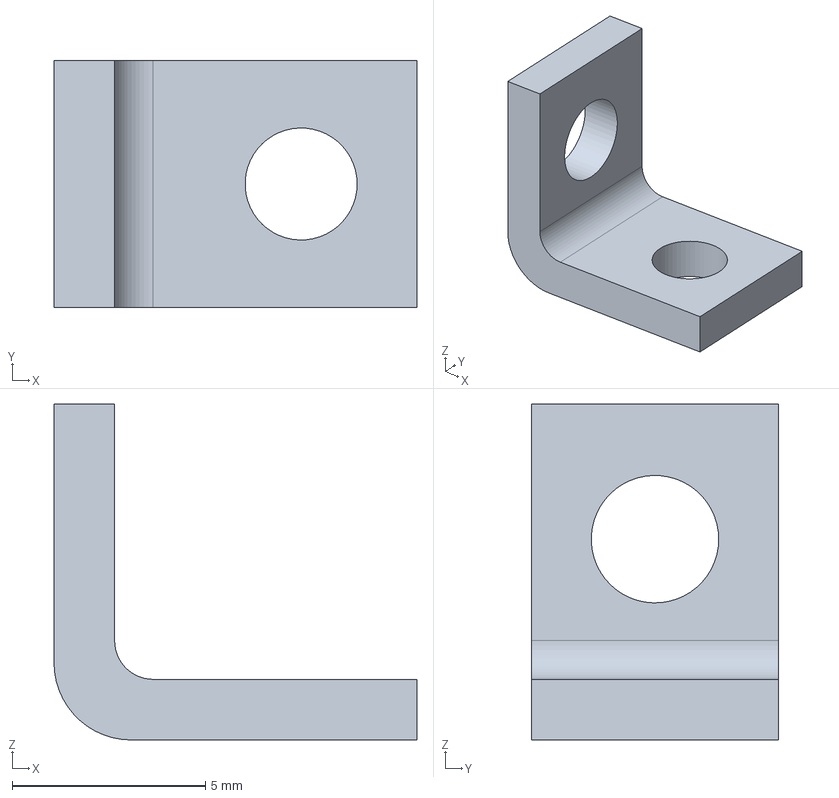
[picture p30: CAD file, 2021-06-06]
models/lbracket-PartBody.step
9.40 x 6.40 x 8.70 mm

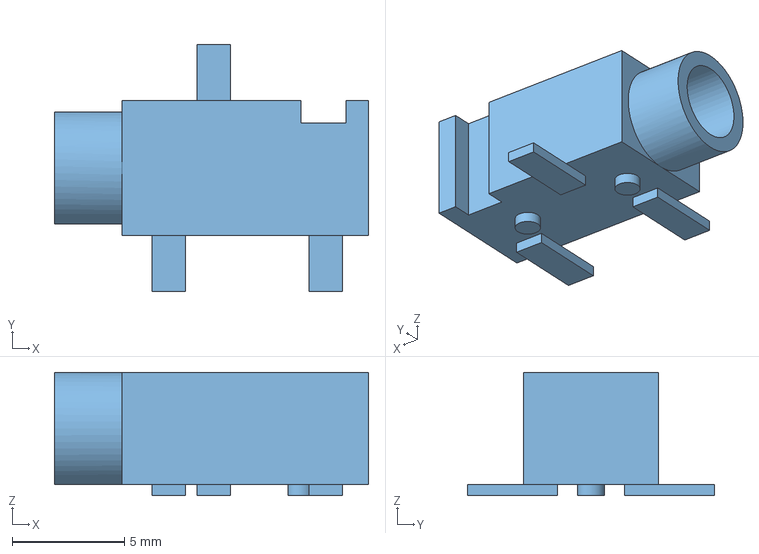
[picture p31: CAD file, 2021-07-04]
models/C18166.FCStd
14.0 x 11.0 x 5.50 mm

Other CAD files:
models/PJ-3280-B-SMT.FCStd
models/hook_rest-Part.step
models/octave_rest-Part.step
models/mpxv7007.FCStd
models/lbracket.FCStd
models/C18166-Part.step
models/hook_rest-Part.stl
models/neck-neck.stl
models/octave_rest-Part.stl

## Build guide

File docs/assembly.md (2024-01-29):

# Assembly Instructions

## Requirements

To assemble a haxophone you will need the following parts:

* 1x partially assembled PCB, with the surface mount parts populated
* 1x Surface mount pressure sensor
* 1x 40-positions female connector
* 2x Right-angle 4-positions male connector
* 2x Straight 4-positions female connector
* 18x 4-40 1/4 inch stainless steel screws
* 4x 4-40 nuts
* 4x M2 flat head phillips 7mm stainless steel machine screws
* 6x L-shape brackets
* 3x 7/16in aluminum spacers
* 30cm silicon tube ID:2mm, OD:6mm
* 1x 3D printed neck
* 2x 3D printed thumb rests
* [Acrylic Conformal Coating](https://www.mgchemicals.com/downloads/tds/tds-419d-l.pdf)

You will use the following tools:

* Soldering iron and solder
* Phillips screwdriver
* Side-cutting pliers

It is also convenient to have:
* Needle nose pliers
* Alcohol and Q-tips

## Conventions

The PCB side with the Open Source Hardware logo is the front.
The opposite side, with the SMD components is the back.
The 40-pos connector area is the bottom, and the area of the neck is the top.

The PCB is comprised of 3 panels.  The larger one is the main panel, the other
two are side panels.  The side panel labelled RHK, is the Right Hand Knuckle or
Right panel.  The side panel labelled LHP is the Left Hand Palm or Left panel.

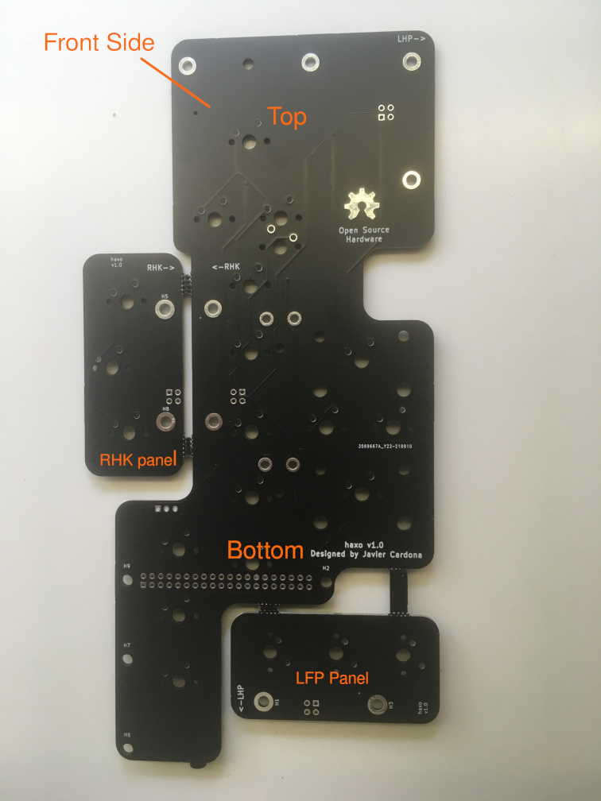
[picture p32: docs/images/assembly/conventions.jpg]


## General advice

* When soldering ensure all flux is thoroughly cleaned, as it may create leakage paths between circuit nodes.  The weak pull-up resistors of the Raspberry Pi make the keyboard matrix very sensitive to leakage paths.

## Assembly steps

### 1. Solder 40-pin connector

Solder 40-pin connector on back side

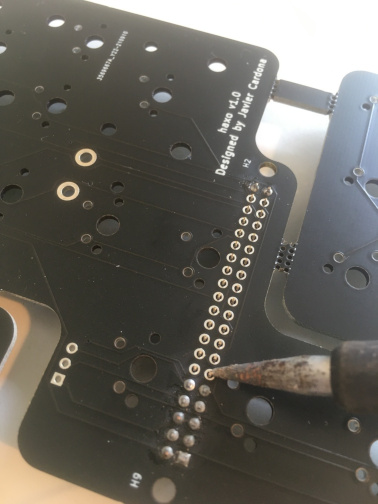
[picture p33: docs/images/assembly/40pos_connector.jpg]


### 2. Solder octave keyswitch

Solder octave keyswitch, the only one on the back side, first.

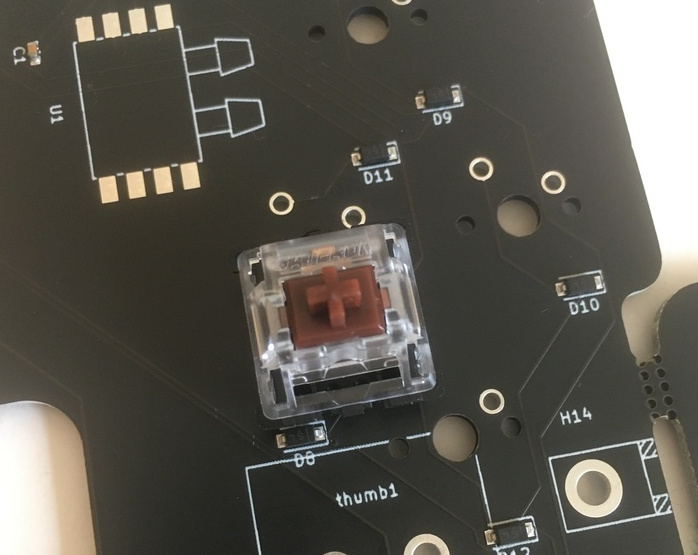
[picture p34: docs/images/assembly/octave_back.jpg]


After soldering, cut the two pins protruding on the front side.  This is only
required on this switch so it does not interfere with the switch on the
opposide side.

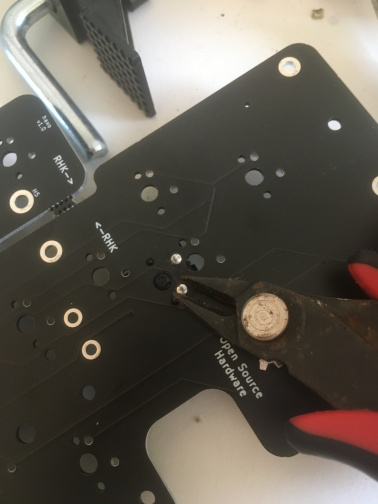
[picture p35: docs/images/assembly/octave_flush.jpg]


### 3. Solder right-angle 4-pos male connectors

Solder the two right-angle 4-pos male connectors on the front side of main panel. The connectors are placed on the opposite (back) side.

This must be done on the top side of the main panel for the connector corresponding to the LHP side panel, and on the middle of the main panel for the connector corresponding to the RHK side panel.

It helps to solder one pin of the connector from the back side to fix it in
position while it is stable in place.

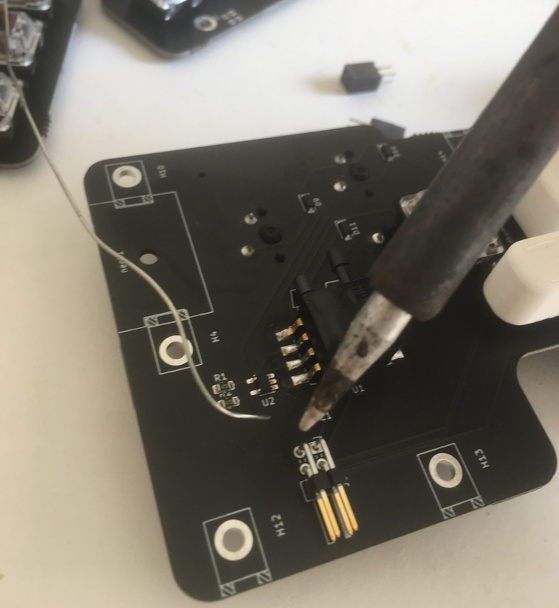
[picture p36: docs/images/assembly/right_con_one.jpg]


Then turn around the board and solder all four pins from the front side. Do this twice, the same way for both connectors.

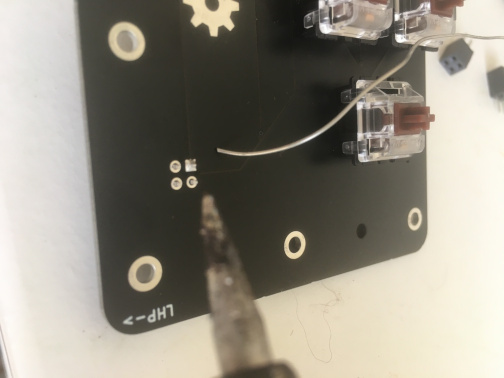
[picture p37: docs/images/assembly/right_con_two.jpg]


### 4. Solder straight 4-pos female connectors

Solder the two straight 4-pos female connectors on the bottom side of the two LHP and RHK side panels.

Test that side panels can be connected to main panel. To do this, you have to detach the side panels from the main one, as described in step 10, unless you have some extra female connectors.

This verification can be usefull since if you solder the right-angle male connectors to tightly on the main panel, the room left for the female straight connectors can be too small.  It could still be placed with some force, but better to check first.

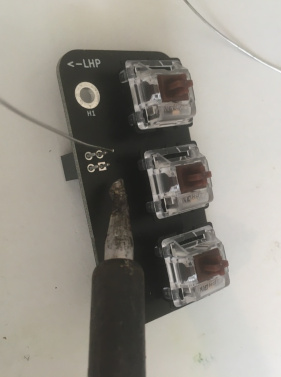
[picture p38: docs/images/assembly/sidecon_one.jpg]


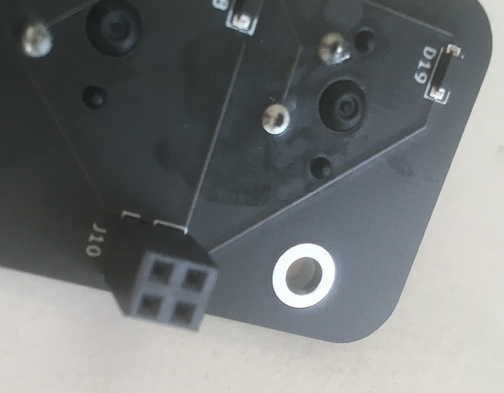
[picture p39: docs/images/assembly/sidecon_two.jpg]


### 5. Apply Conformant Coating to front side

Now that all the thru-hole components on the back side have been soldered, apply conformant coating to the front side. This can be done using a spray (eg.: ELECTROLUBE  AFA200) or a bottle (eg.: MG CHEMICALS  419D-55ML) and brush.

In case you use a spray, this front side does not require special protection contrary to the the back side as described in step 8.

This will protect the board against rust.  The coat needs to be applied before populating the front-side components, which we will do in the next steps.

### 6. Solder pressure sensor

Solder surface mount pressure sensor.

Add solder to one pad and then solder one pin first to secure the sensor in the right position.

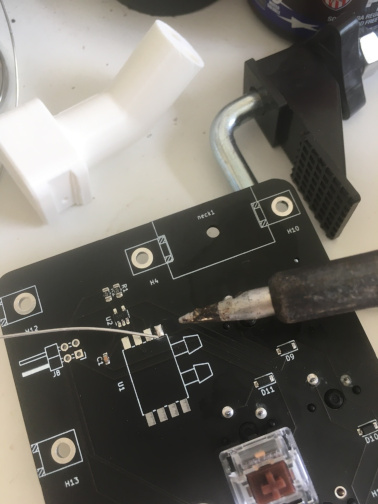
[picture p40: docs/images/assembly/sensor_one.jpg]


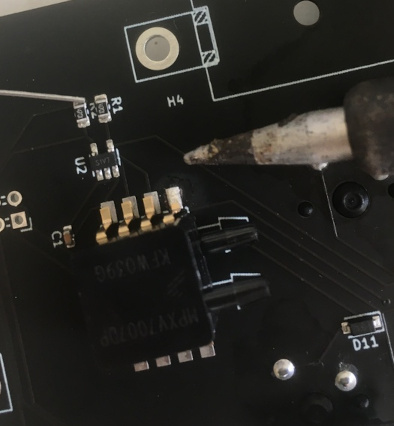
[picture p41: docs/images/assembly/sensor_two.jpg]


Then solder the remaining 7 pins.

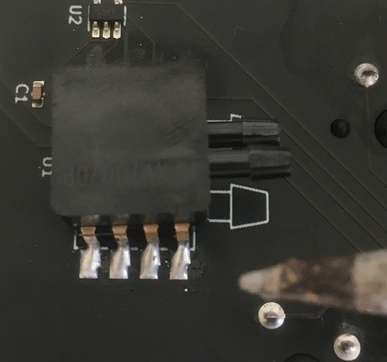
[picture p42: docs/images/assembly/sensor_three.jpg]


### 7. Solder remaining keyswitches

Solder the front-side switches.

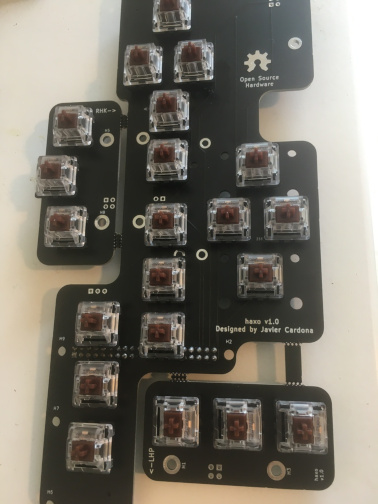
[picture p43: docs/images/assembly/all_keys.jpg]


### 8. Apply Conformant Coating to back side

Now that all the thru-hole components on the front side have been soldered, apply conformant coating to the back side.
This will protect the board against rust.  The coat needs to be applied before attaching the mechanical parts (neck, thumb rests), which we do in the next steps.

If you use the conformant coating in spray, this is probably safer to protect some components before spraying with some tape (the octave keyswitch, 40 pin female connector, the 2 right-angle male and the 2 straight female connectors, the 2 holes of the pressure sensor and the female jack connector).

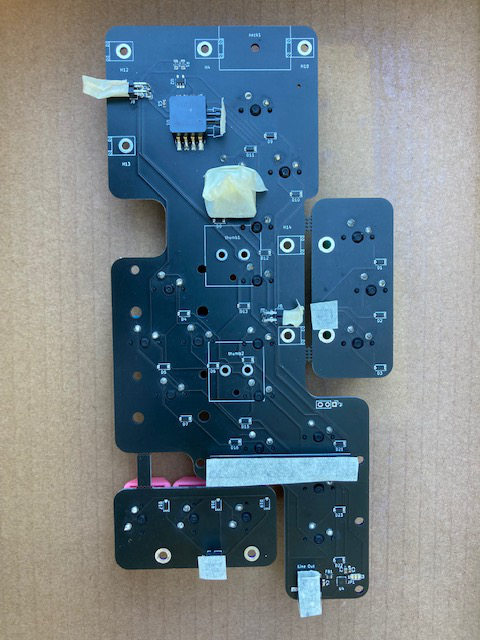
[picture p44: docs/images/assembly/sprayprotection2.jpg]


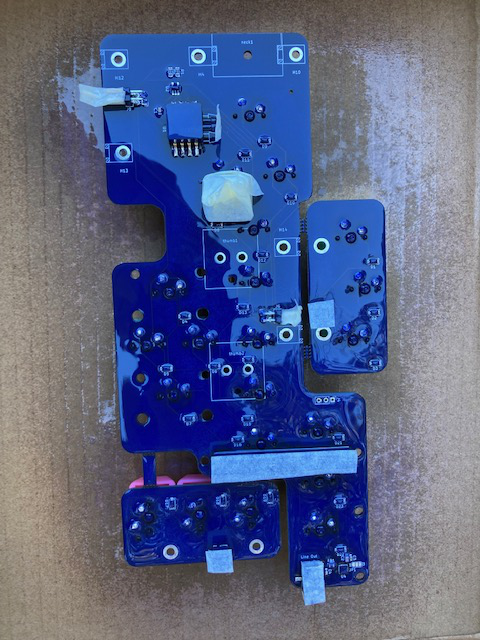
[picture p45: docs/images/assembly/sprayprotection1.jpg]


### 9. Attach thumb rests

Using M2 flat head screws, attach octave thumb rest on top, lower thumb rest
with hook on bottom.  Depending on the quality of the 3D printing of these parts you will probably have to clean the small triangle contact surface to make it flat, and the small male pin with the good diameter so that it can enter into the corresponding hole on the PCB.

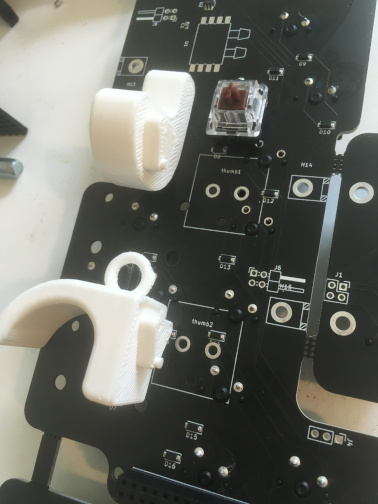
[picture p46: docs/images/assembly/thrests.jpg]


It might be easier to screw in the screws one first time without the PCB to
properly thread the plastic holes.

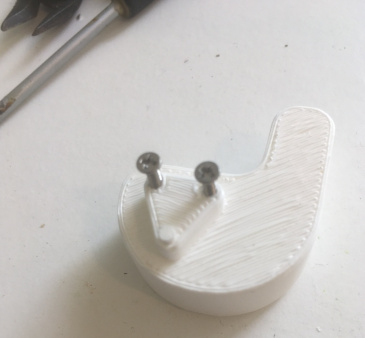
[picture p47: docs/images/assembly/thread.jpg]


Then remove the screws, and repeat once attached to the PCB.

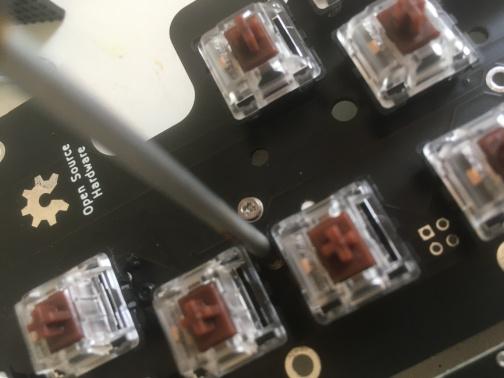
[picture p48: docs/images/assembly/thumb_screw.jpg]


### 10. Detach PCB panels

Detach the side PCB panels by cutting along the mouse bite patterns with a cutter.

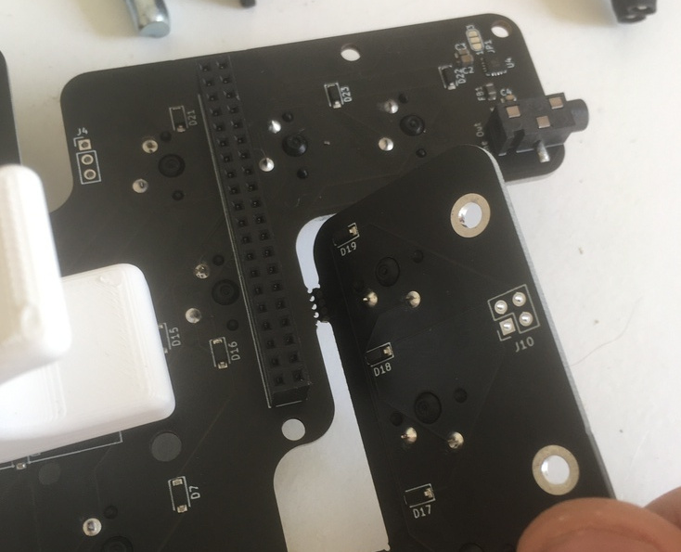
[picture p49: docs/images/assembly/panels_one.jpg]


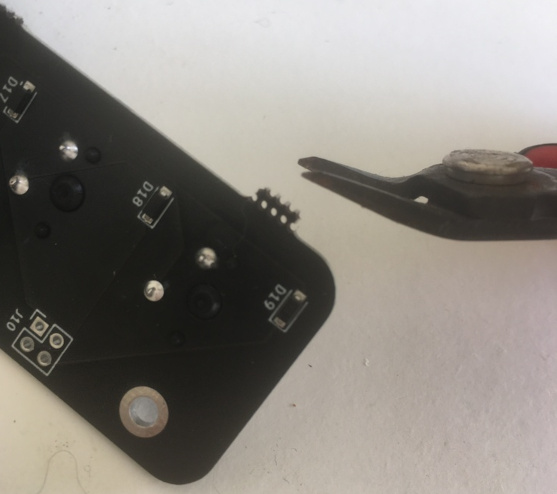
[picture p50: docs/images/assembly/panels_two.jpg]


### 11. Attach side panels to main board

Attach L-brackets to side panels using screws and nuts.

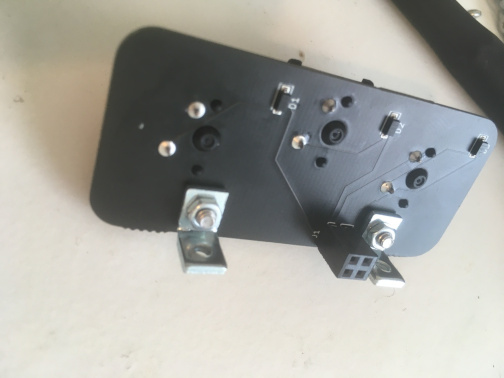
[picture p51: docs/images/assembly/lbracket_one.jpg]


Connect side panels to main panel, and screw main panel screws.  The threaded side of all L-brackets sits on the main panel.

In case it is difficult to connect the side panels to the main one, this is maybe due to the fact that the right-angle connectors were soldered tightly on the board, and the room for the female one is slightly too small.  By forcing a little, with care, you can probably manage to do it. 

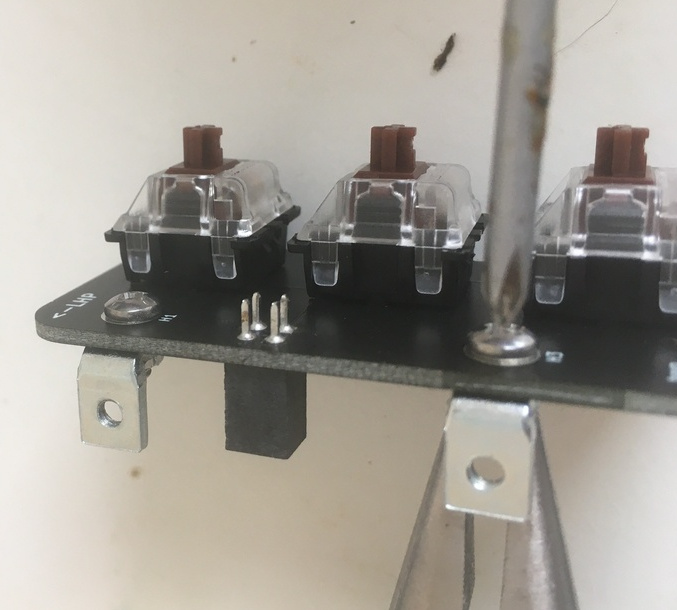
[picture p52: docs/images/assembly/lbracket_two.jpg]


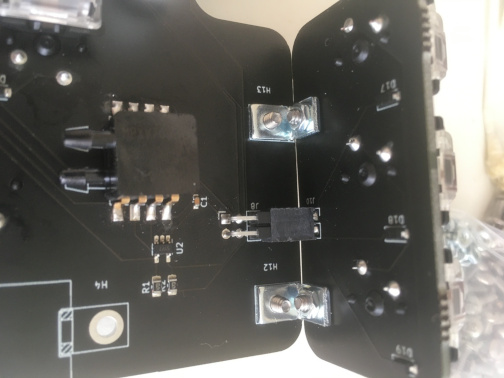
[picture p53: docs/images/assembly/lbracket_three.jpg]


### 12. Attach neck

Attach L-brackets to both sides of neck.  The neck does not need nuts.

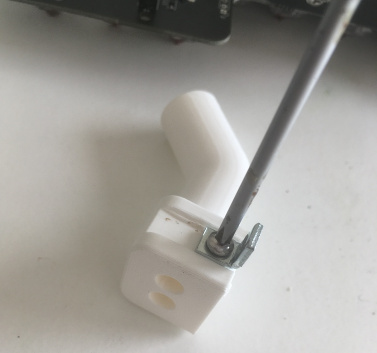
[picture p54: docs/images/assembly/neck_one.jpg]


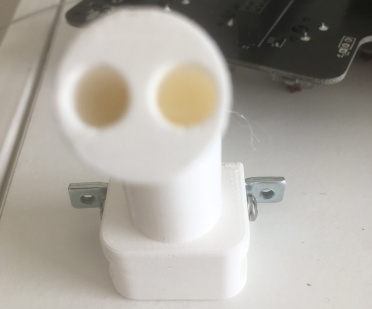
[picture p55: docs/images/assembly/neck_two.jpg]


Then attach neck to main panel.

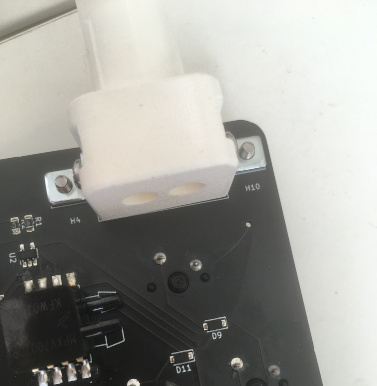
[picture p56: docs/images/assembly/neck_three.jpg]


### 13. Connect pipes to neck

Use one short section (~2cm) of the pipe to connect the neck to the pressure
sensor.  Depending on your tube, you might need a bit of wire or a small cable-tie to tighten it.

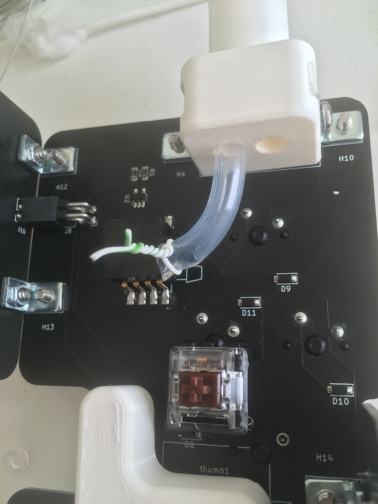
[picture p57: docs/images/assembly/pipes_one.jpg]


Use a longer section (~20cm) of the pipe to connect the second hole.  This
second pipe is used for venting, and has to point away from the PCB to prevent
corrosion.

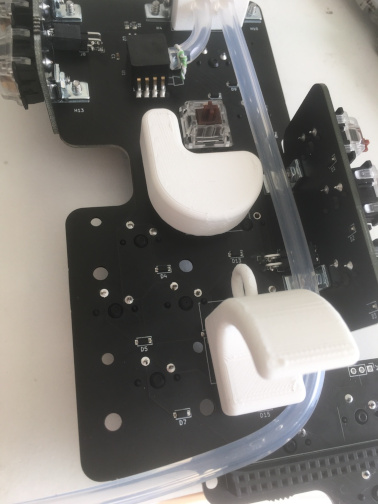
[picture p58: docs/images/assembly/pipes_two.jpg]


### 14. Attach Raspberry Pi

At this point the Haxophone HAT is fully assembled.  You can now attach it to a Raspberry Pi.  The Haxophone PCB has mounting holes for both Raspberry Pi sizes, the Zero and the 3/4.

Screw three spacers to the Pi:

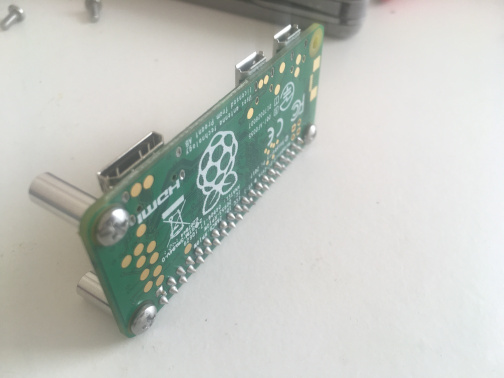
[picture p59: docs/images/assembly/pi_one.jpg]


Now connect the Pi to the 40-position connector and secure it with screws.

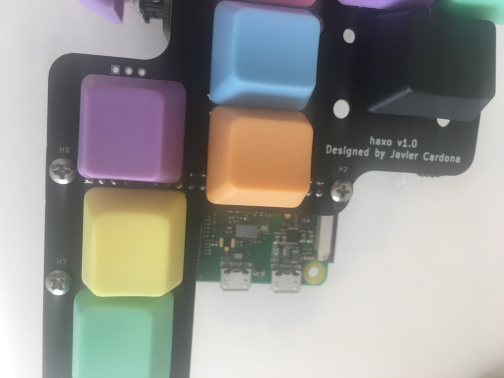
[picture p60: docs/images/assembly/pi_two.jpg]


### 15. Optionally attach a mouthpiece with reed

The mouthpiece is used for embochure comfort and familiarity, but it is not really necessary.  If you use a mouthpice, you will need to also have a reed.  The reed does not produce sound, but it seals the mothpiece for a proper transfer of pressure to the sensor.

To attach a mouthpiece, you might need to use some masking, washi or cork tape to adjust the neck diameter to your mouthpiece.

### 16. Testing

In [haxo-rs](https://github.com/jcard0na/haxo-rs#testing) you will find tests that will help you verify that all keys and the pressure sensor work.

Otherwise, you can skip this step, apply power, attach headphones and start playing.

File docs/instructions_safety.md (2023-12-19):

### Instructions

1. **Connecting the Haxophone to Raspberry Pi:**
   Attach the haxophone to the Raspberry Pi 40-pin connector, ensuring that the USB power supply port on the Raspberry Pi faces the bottom of the haxophone, aligning with the mini-jack connector direction. Refer to the picture below for visual guidance:
   
   Attaching Raspberry Pi

2. **Optional Saxophone Mouthpiece Attachment:**
   If desired, you can attach a saxophone mouthpiece to the haxophone's neck. Use masking or electrical tape to adjust the neck's thickness to match your mouthpiece. Refer to the image below:
   
   Attaching a mouthpiece

3. **Installing Software**
   Download pre-compiled software image from the link below:

   Raspberry Pi Zero and Zero W: [https://bit.ly/haxo-rpiz](https://bit.ly/haxo-rpiz)

   Raspberry Pi 4: [https://bit.ly/haxo-rpi4](https://bit.ly/haxo-rpi4)

   Raspberry Pi 3: [https://bit.ly/haxo-rpi3](https://bit.ly/haxo-rpi3)
   
   Then flash it onto a 16GB SD Card.  Insert card into SD card slot of Raspberry Pi.
   
5. **Powering Up the Haxophone:**
   Insert the USB connector into the USB power port on the Raspberry Pi to power it up.

6. **Waiting for Boot:**
   Allow the haxophone a minute to complete the boot process.

7. **Start Playing:**
   Blow air through the mouthpiece to begin playing.

### Changing Instrument Sounds

1. **Draw air from the mouthpiece while holding a low Bb fingering**
   After less than a second, a beep will sound indicating the haxophone is in command mode.

Draw air with Bb-fingering to enter command mode

2. **Press keys R1 (or R3) to move up (or down) different instrument sounds**
   After each key press, you will hear a note with the newly selected sound.

   Next instrument

    Previous instrument

   Jump ahead 10 instruments

   Jump back 10 instruments

3. **Confirm selection by pressing all left hand palm keys**
   A beep will sound indicating the haxophone is now ready to be played.

Press all three left palm keys to exit command mode

### Maintenance

1. **Vent Tubes Cleaning:**
   Regularly clear the vent tubes on the haxophone by blowing dry air through them or using appropriately sized pipe cleaners.

2. **Surface Moisture Removal:**
   Use a dry cloth to wipe off any moisture that accumulates on the surface of the haxophone.

### Safety Information

1. **Proper Power Supply Connection:**
   ALWAYS power up the haxophone by connecting a USB-compliant power supply to the Raspberry Pi USB power port. DO NOT apply voltage in any other way.

2. **Mouth Insertion Warning:**
   DO NOT insert any part of the haxophone into your mouth except the tip of the neck or the mouthpiece, if you are using one.

3. **Device Condition Alert:**
   If the haxophone shows any signs of damage, emits acrid smells, or exhibits mold growth, STOP USING the device immediately for safety reasons.

| Document Version | Changes |
| --- | --- |
| 1.0 | |

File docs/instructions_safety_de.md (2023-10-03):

### Anleitung

1. **Anschließen des Haxophons an den Raspberry Pi:**
   Befestige das Haxophon am 40-poligen Anschluss des Raspberry Pi und achte darauf, dass der USB-Stromanschluss des Raspberry Pi nach unten zeigt und in Richtung des Mini-Jack-Anschlusses am Haxophon ausgerichtet ist. Siehe Abbildung 1 zur visuellen Orientierung:

   Raspberry Pi anschließen

2. **Optionale Befestigung des Saxophonmundstücks:**
   Wenn gewünscht, kannst du ein Saxophonmundstück am Haxophonhals befestigen. Verwende Klebeband oder Isolierband, um die Dicke des Halses an dein Mundstück anzupassen. Dies wird in Abbildung 2 dargestellt.

   Mundstück befestigen

3. **Installation der Software:**
   Lade die vorkompilierte Software-Image von den folgenden Link herunter:

   Raspberry Pi Zero und Zero W: [https://bit.ly/haxo-rpiz](https://bit.ly/haxo-rpiz)

   Raspberry Pi 4: [https://bit.ly/haxo-rpi4](https://bit.ly/haxo-rpi4)

   Raspberry Pi 3: [https://bit.ly/haxo-rpi3](https://bit.ly/haxo-rpi3)

   Flashe sie dann auf eine 16-MB-SD-Karte und stecke die Karte in den SD-Kartensteckplatz des Raspberry Pi.

4. **Einschalten des Haxophons:**
   Schließe den USB-Stecker an den USB-Stromanschluss des Raspberry Pi an, um ihn einzuschalten.

5. **Warten auf den Start:**
   Lass dem Haxophon eine Minute Zeit, um den Startvorgang abzuschließen.

6. **Starte das Spielen:**
   Blase Luft durch das Mundstück, um mit dem Spielen zu beginnen.

### Ändern der Instrumentenklänge

1. **Luft aus dem Mundstück ziehen und dabei eine tief Bb-Fingertechnik halten**
   Nach weniger als einer Sekunde ertönt ein Piepton, der anzeigt, dass das Haxophon sich im Befehlsmodus befindet.

Luft ziehen mit Bb-Fingertechnik, um in den Befehlsmodus zu gelangen

2. **Die Tasten R1 (oder R3) drücken, um verschiedene Instrumentenklänge auszuwählen**
   Nach jedem Tastendruck hören Sie einen Ton mit dem neu ausgewählten Klang.

Nächstes Instrument

Vorheriges Instrument

10 Instrumente vorspringen

10 Instrumente zurückgehen

3. **Auswahl bestätigen, indem Sie alle linken Handflächen-Tasten drücken**
   Ein Piepton ertönt, der anzeigt, dass das Haxophon jetzt spielbereit ist.

Alle drei linken Handflächen-Tasten drücken, um den Befehlsmodus zu verlassen

### Wartung

1. **Reinigung der Belüftungsrohre:**
   Reinige regelmäßig die Belüftungsrohre des Haxophons, indem du trockene Luft durch sie bläst oder passende Pfeifenreiniger verwendest.

2. **Entfernen von Oberflächenfeuchtigkeit:**
   Verwende ein trockenes Tuch, um Feuchtigkeit von der Oberfläche des Haxophons abzuwischen.

### Sicherheitshinweise

1. **Korrekte Stromversorgungsverbindung:**
   Schalte das Haxophon IMMER ein, indem du eine USB-kompatible Stromversorgung an den USB-Stromanschluss des Raspberry Pi anschließt. Wende KEINE andere Methode zum Anlegen von Spannung an.

2. **Warnung vor dem Einsetzen in den Mund:**
   Setze KEINEN Teil des Haxophons in den Mund ein, außer der Spitze des Halses oder dem Mundstück, falls du eines verwendest.

3. **Gerätezustand beachten:**
   Wenn das Haxophon Anzeichen von Beschädigung zeigt, einen beißenden Geruch ausströmt oder Schimmelbildung aufweist, STOPPE die Verwendung des Geräts sofort aus Sicherheitsgründen.

| Dokumentversion | Änderungen |
| --- | --- |
| 1.0 | |

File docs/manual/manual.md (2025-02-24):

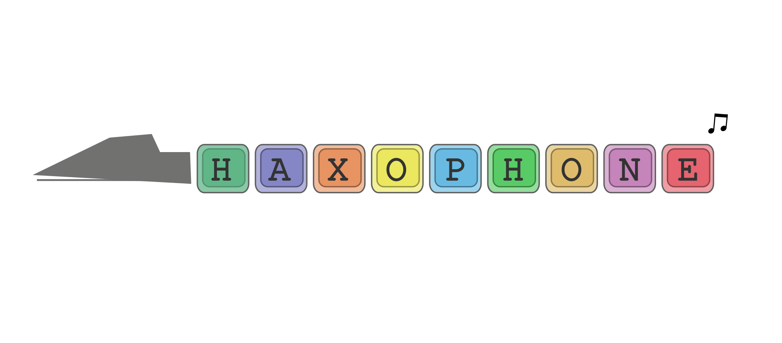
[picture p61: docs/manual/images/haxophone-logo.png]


# Haxophone Manual
## Table of Contents
<!-- toc -->
- [Introduction](#introduction)
	* [What is the Haxophone ](#what-is-the-haxophone)
	* [Where You Can Get It](#where-you-can-get-a-haxophone)
	* [How to Use This Manual](#howto-use-this-manual)
- [Using the Haxophone](#using-the-haxophone)
	* [Unpacking and Setting Up](#unpackung-and-setting-up)
		+ [Connect and Install the Software](#connect-and-install-software)
		+ [Start the Haxophone](#start-haxophone)
		+ [Shutdown the Haxophone](#stop-haxophone)
	* [Before You Play](#before-you-play)
		+ [Choose a Sound](#choose-sound)
		+ [ Choose the Transpose Key](#choose-transpose-key)
	* [Playing](#playing)
	* [Hacking](#hacking)
		+ [Howto Connect to the Haxophone](#howto-connect)
		+ [Howto Login ](#howto-login)
		+ [Howto Login: other Methods ](#howto-login-other)
		+ [Checking the Logs ](#checking-the-logs)
		+ [Howto Make Permanent Modifications](#howto-permanent-modifications)
		+ [The File haxo.service Explained](#haxo.service-explained)
	* [Advanced Hacking](#advanced-hacking)
		+ [Install the Newest Binary](#install-newest-binary)
		+ [Howto Change the Sound Set](#howto-change-sound-set)
		+ [Howto Change the notemap.json](#howto-notemap.json)
		+ [The non-existent Shutdown command](#howto-tigger-shutdown)
- [Appendix](#appendix)
	* [Haxophone Cheat Sheet](#haxophone-cheat-sheet)
	* [Haxophone Sounds](#haxophone-sounds)
	* [Troubleshooting / FAQ](#troubleshooting-faq)
	* [Links and Resources](#links-and-resources)
	* [Caring for the Haxophone](#caring-for-the-haxophone)
	* [Safety Information](#safety-information)

<!-- tocstop -->

## Introduction

### What is the Haxophone 
The Haxophone is for you if you are a musician, a hacker or both!
It is a hackable saxophone (that's where the name comes from). It is lightweight and perfect for travelling. Enjoy the many sounds included without disturbing your neighbors! 

You can modify transposition, record the midi sound and more.

When it comes to hacking you can modify the fingering, change the default settings and add more options. You can modify everything, as it is fully open source (hardware and software).

And what is most important: You can have a lot of fun!

### Where You Can Get It
There are two ways to get a haxophone:

1. The fastest way: switch over to crowdsupply and order it there. You need to buy some more stuff as well: a Raspberry Pi Zero (or a Pi 3 or a Pi 4) and an SD card with 16 GB or larger(see [https://www.crowdsupply.com/cardona-bits/haxophone](https://www.crowdsupply.com/cardona-bits/haxophone))

2. You can build your own! The bits and pieces needed to build the haxophone and how to assemble it can be found here: [Assembly Instructions](https://github.com/cardonabits/haxo-hw/blob/main/docs/assembly.md)

3. You can build your own with an assembly kit that contains most of the bits and pieces:
Those of you who want to wield your soldering irons, tweezers, voltmeters and screwdrivers, but don't necessarily want to order parts all over the universe, here's your chance to order all most of the parts as a kit. Why most? We left out the keyswitches, which is what people seem be most particular about. But everything else is there: PCBA, screws, tubing, keycaps, etc.
Before ordering, check out the [assembly instructions](https://github.com/cardonabits/haxo-hw/blob/main/docs/assembly.md) to make sure you are up to the challenge! 
You can [order the kits here](https://lightnote.cardonabits.com/products/haxophone-as-a-kit).

### How to Use This Manual

If you are using your haxophone for the first time go to [Unpacking and Setting Up](#unpackung-and-setting-up).

If you are a musician and you want to get started playing quickly: Got to section [Playing](#playing).

if you are a hacker-hobby-musician or a musician-hobby-hacker then go to [Hacking](#hacking).
 
If you are an advanced hacker go to [Hacking](#hacking)

## Using the Haxophone

### Unpacking and Setting Up
When you receive your haxophone from crowdsupply it comes with an instruction, some washi tape and screws.

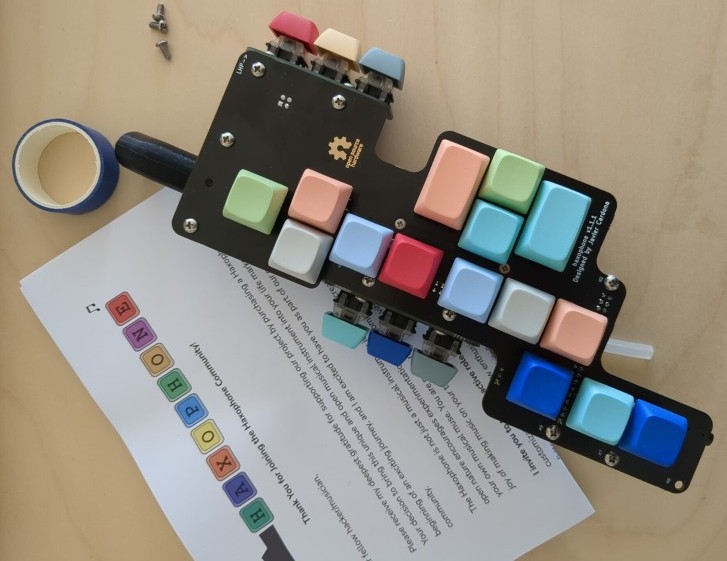
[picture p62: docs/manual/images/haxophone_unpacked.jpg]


To get started, you will need the following additional items:

1. Raspberry Pi Zero or Zero W or Pi 3 or Pi 4.
2. PC or notebook with SD card reader
3. SD card with 16 or 32 GB memory
4. USB power supply with a micro USB-B plug 
5. Headphones, earphones or active speaker
6. Optional: a saxophone mouthpiece
7. Optional: HDMI cable (for Pi Zero: with HDMI mini connector)
8. Optional: USB keyboard
9. Optional: USB cable, USB network adapter or USB hub with network adapter

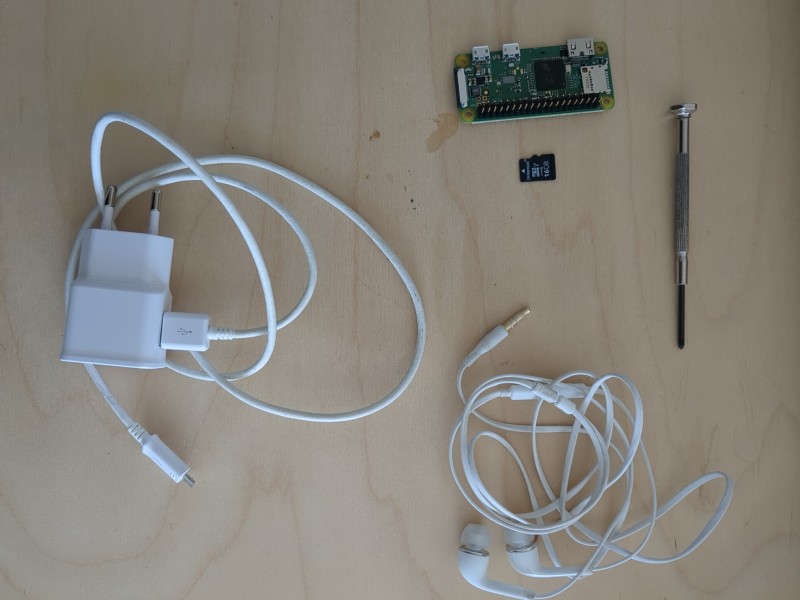
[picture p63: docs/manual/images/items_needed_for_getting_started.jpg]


#### Connect and Install the Software
1. **Connect the Raspberry Pi with the Haxophone:**
   Put the Raspberry Pi 40-pin connector plug on the haxophone 40-pin connector port. Take care that the USB power supply port on the Raspberry Pi faces the bottom of the haxophone, aligning with the mini-jack connector direction. 

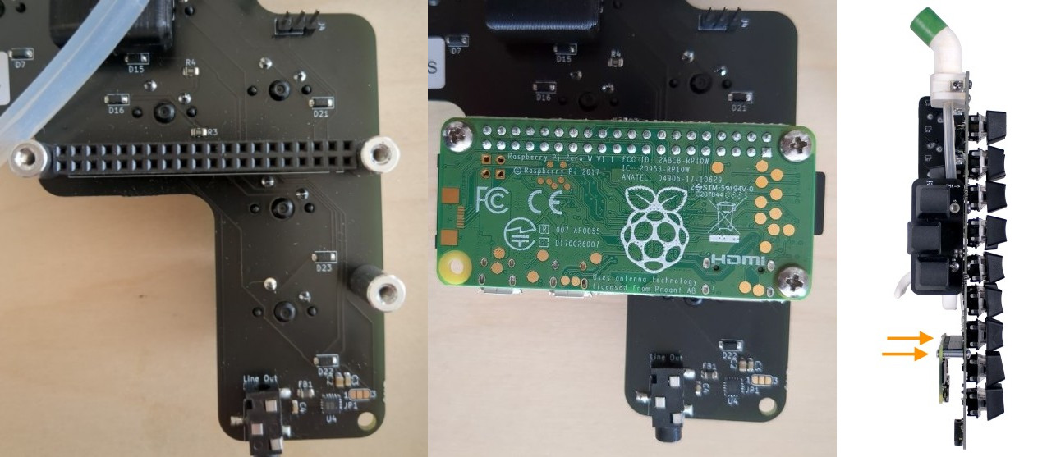
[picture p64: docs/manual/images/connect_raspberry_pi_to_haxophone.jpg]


2. **Connect a Headphone to the Haxophone**
Connect a headphone, earphone or active speaker to your haxophone using the mini-jack on the bottom edge

3. **Optional: Attach a Saxophone Mouthpiece:**
   If you want you can attach a saxophone mouthpiece to the haxophone's neck. Use masking, electrical or washi tape to adjust the neck's thickness to match your mouthpiece.

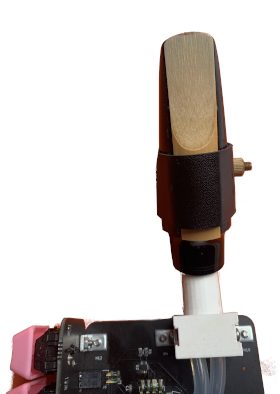
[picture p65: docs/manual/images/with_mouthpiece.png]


4. **Optional: Attach a Neck Strap:**
You can attach a neck strap using the eyelet just on top of the thumb rest.

5. **Install the Software on the SD Card**

5a) Download the pre-compiled software image from one the following links:

* Raspberry Pi Zero and Zero W: [https://bit.ly/haxo-rpiz](https://bit.ly/haxo-rpiz)
* Raspberry Pi Zero 2: [https://bit.ly/haxo-rpiz2](https://bit.ly/haxo-rpiz2)
* Raspberry Pi 4: [https://bit.ly/haxo-rpi4](https://bit.ly/haxo-rpi4)
* Raspberry Pi 3: [https://bit.ly/haxo-rpi3](https://bit.ly/haxo-rpi3)
   
Unzip the file:
```
$ unzip haxophone.img.zip 
Archive:  haxophone.img.zip
  inflating: haxophone-rpiz.img      
  inflating: haxophone-rpiz.img.sha256  
```

You can check the integrity of the file with
```
$ cat haxophone-rpiz.img.sha256 
86c5d0280d49609a18d64c2d12d66b8480fe293a02b37d1f14569640d265e469  haxophone-rpiz.img

$ sha256sum -c haxophone-rpiz.img.sha256
(long wait)
haxophone-rpiz.img: OK
```

5b) Download the Raspberry Pi Imager software from here:
[https://www.raspberrypi.com/software/](https://www.raspberrypi.com/software/) or on Ubuntu install it with
```
sudo apt install rpi-imager
```

5c) Use the Raspberry Pi Imager software to copy the
software image onto a 16 GB or 32 GB SD Card

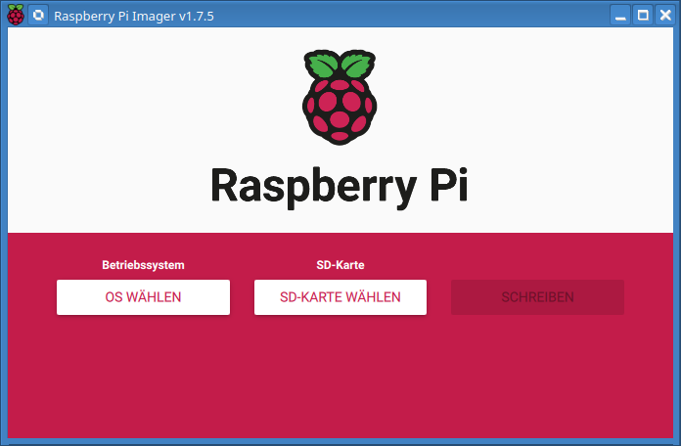
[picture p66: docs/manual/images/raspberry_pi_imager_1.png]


Select "Eigenes Image" or "own image" as an operating system. As file choose the haxophone-rpiz.img file

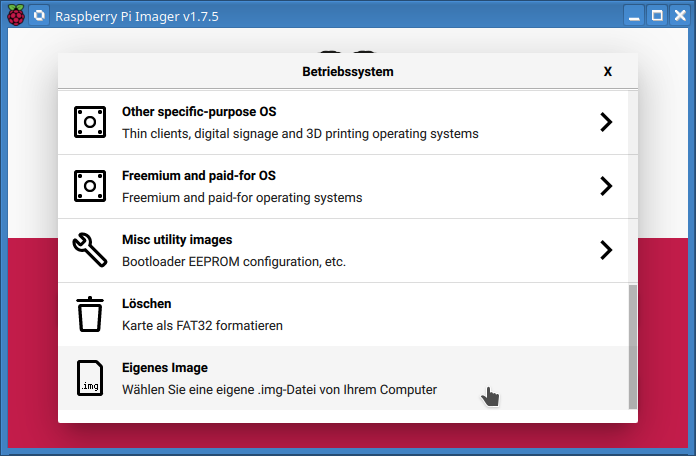
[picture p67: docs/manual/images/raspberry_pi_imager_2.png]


Next select the SD card

***Warning
	If you have more than one storage device connected to your computer, be sure to choose the correct device! You can often identify storage devices by size. If you’re unsure, disconnect other devices until you’ve identified the device you want to image. *** 

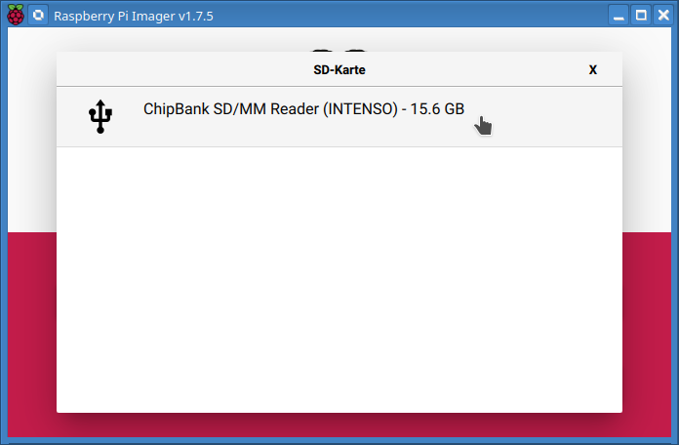
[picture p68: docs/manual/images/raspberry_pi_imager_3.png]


Next click on "schreiben" or "write". You don't need to add any additional information in the settings section (the cog wheel button)

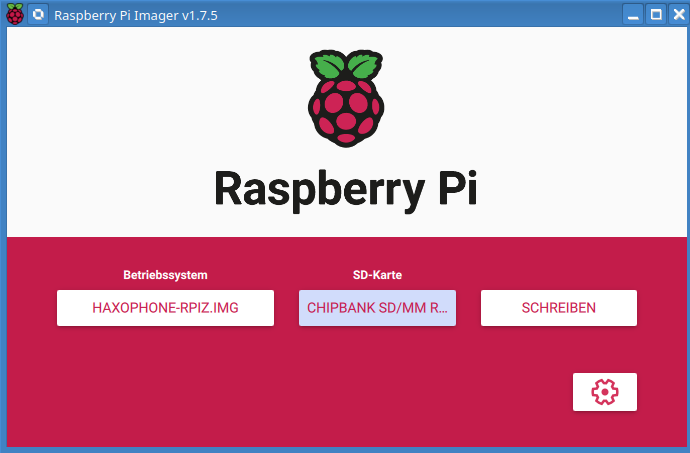
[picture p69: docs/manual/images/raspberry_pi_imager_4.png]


Next confirm that it is really this SD card you want to write on

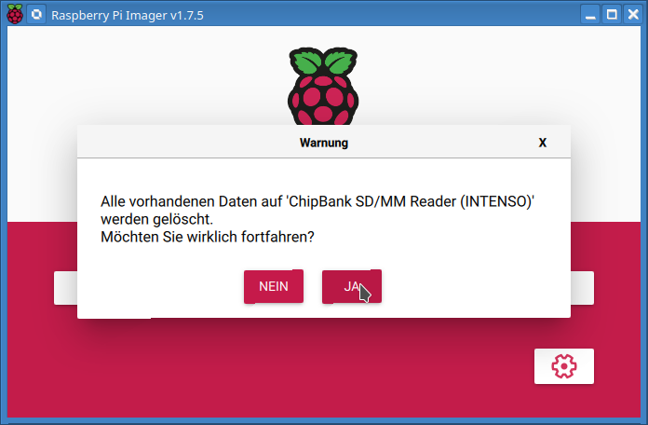
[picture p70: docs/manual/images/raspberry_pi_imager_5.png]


This is the confirmation message, when writing was successful:

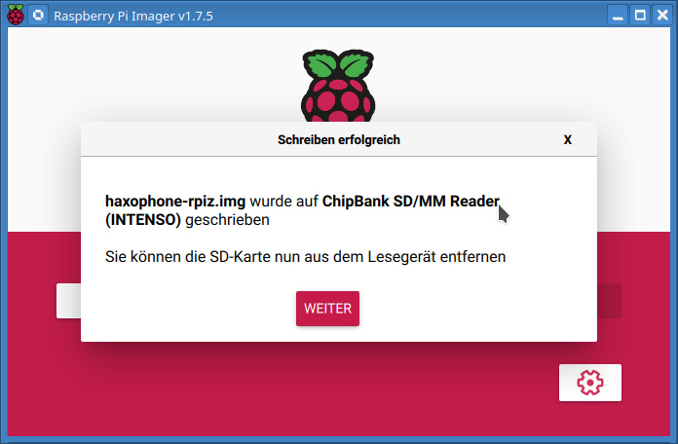
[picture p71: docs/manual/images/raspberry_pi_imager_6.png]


If you get an error message saying your SD card is too small:
Use Pishrink  [https://github.com/Drewsif/PiShrink](https://github.com/Drewsif/PiShrink)
```
wget https://raw.githubusercontent.com/Drewsif/PiShrink/master/pishrink.sh

$ sudo ./pishrink.sh -s haxophone-rpiz.img
pishrink.sh v0.1.4
pishrink.sh: Gathering data ...
Skipping autoexpanding process...
pishrink.sh: Checking filesystem ...
rootfs: recovering journal
rootfs: 102496/278880 files (0.2% non-contiguous), 1037884/1137364 blocks
resize2fs 1.47.0 (5-Feb-2023)
pishrink.sh: Shrinking filesystem ...
resize2fs 1.47.0 (5-Feb-2023)
Resizing the filesystem on /dev/loop30 to 1135693 (4k) blocks.
The filesystem on /dev/loop30 is now 1135693 (4k) blocks long.

pishrink.sh: Shrinking image ...
pishrink.sh: Shrunk haxophone-rpiz.img from 15G to 4.6G ...
```
With the shrunken image repeat the steps with the RaspBerry Pi Imager software as described above.

5d) Insert the SD card into the SD card slot of Raspberry Pi.
   


#### Start the Haxophone
1. **Connect Power:**
To power up your haxophone insert the USB connector into the USB power port on the Raspberry Pi. Please take care to use the correct one marked with **PWR IN** 



Now your haxophone is ready to play!



2. **Waiting for Boot:**
   Allow the haxophone a minute to complete the boot process. You will hear the haxophone startup tune if you have your headphones connected

3. **Start Playing:**
   Blow air through the mouthpiece or tip of the neck to begin playing.

#### Shutdown the Haxophone
To turn off the Haxophone you just need to unplug the power. You don't need to worry about corrupting files on the SD card, as the SD card is read only per default.

### Before You Play
With the haxophone you have the full choice of what kind of instrument you want to play, you do not need to stick to the tenor saxophone sound or the fact that the keys are transposed to Bb.

So before you start playing you can choose a different sound and choose another transpose key:

#### Choose a Sound
The haxophone uses a tenor sax sound as the default sound. If you want to change the sound you can switch into command mode and then scroll through the sounds until you find the sound you like. Then you exit the command mode.

Here is how it works:

* to enter the command mode play a low Bb and draw air until you hear a confirmation sound
  


* when you scroll through the sounds a short sound is played with each sound
* to scroll up or down through the sounds use the up and down keys
  


* to scroll faster, press the L2 key with the up or down keys:  this will advance 10 sounds at a time



* when satisfied with the selected sound, press all three palm keys until you hear a confirmation sound
  


Now you are ready to play with the new sound!

More information is found here:

* The list of existing sounds is described in appendix [Haxophone Sounds](#haxophone-sounds)
* The cheatsheet shows the keys for using the command mode:  [Haxophone Cheat Sheet](#haxophone-cheat-sheet)

#### Choose the Transpose Key
Note: The transpose mode feature is actually not included in the default software image. You have to install the newest version of the haxophone software. More about this in another chapter, but the work there is still in progress.

The haxophone transposes the keys to Bb by default. 
If you want to change this then you can switch into transpose mode and then play the key you want to transpose to. Then you exit the transpose mode.

Here is how it works:

* to enter the transpose mode play a low B and draw air until you hear a confirmation sound 
* next play the key you want to transpose to, so the key that will be the new C. And at the same time blow air. The new key will be played as confirmation. For example:
	+ play Eb for an alto sax
	+ play high C for a flute
	+ play Bb for a tenor sax
* when satisfied with the transpose key, press all three palm keys until you hear a confirmation sound

Now you are ready to play with the new transposed keys!

More information is found here:

* The cheatsheet shows the keys for using the transpose mode:  [Haxophone Cheat Sheet](#haxophone-cheat-sheet)

See section ##Howto Make Permanent Modifications below if you want this changes to be permanent, for instance, to configure your haxophone to boot into an alto sax transposition and sound.

### Playing
Here are some useful links to the haxophone fingering chart and some other fingering charts:

* [https://www.sebulli.com/haxo/notemap/](https://www.sebulli.com/haxo/notemap/)
* [https://www.windtabmusic.com/free-area-tenor-sax ](https://www.windtabmusic.com/free-area-tenor-sax)

### Hacking
Your haxophone runs on Linux, and sometimes it is necessary (or fun) to just poke inside. For that you will need to log into your system. There are three supported ways to do so.

#### Howto Connect to the Haxophone
There are three ways to connect to the haxophone. The easiest way is to use SSH over ethernet.

##### SSH over Ethernet
The easiest way to connect is to use SSH over ethernet (connecting via WiFi is possible, but the default Haxophone images have WiFi disabled for performance. WiFi activity can introduce delays that affect latency while playing). 
To connect the Rapsberry Pi Zero you need an USB to ethernet adapter as shown in the following picture: the white cable connects to the power supply, the black connects to a micro USB-B to USB A adapter and then to a USB ethernet adapter.



#### Howto login 
Whith the haxophone connected to ethernet you should be able to login to the haxophone.
First check if the haxophone appears on your local network:
Open a command line tool or shell:

```
ping haxophone.local
```

You should get a response.

The haxophone images are configured with username pi and password haxophone. So to login to your haxophone use

```
ssh pi@haxophone.local
```
When asked for the password enter `haxophone`



To login to the haxophone without need to always enter the password, you can transfer your SSH kay to the haxophone.
If you don't have any SSH key on your computer you can generate it like this:

```
ssh-keygen -t rsa -b 4096
```

For more details on how to work with ssh keys see [https://www.ssh.com/academy/ssh/keygen](https://www.ssh.com/academy/ssh/keygen)

Then you copy your public key to the haxophone like this:

```
ssh-copy-id pi@haxophone.local
/usr/bin/ssh-copy-id: INFO: attempting to log in with the new key(s), to filter out any that are already installed
/usr/bin/ssh-copy-id: INFO: 1 key(s) remain to be installed -- if you are prompted now it is to install the new keys
pi@haxophone.local's password: 
```

You will be asked to enter the password one more time.
The next time you login to the haxophone from your computer, no password is required.

(Attention: if you want this changes to be permanent, then see section ##Howto Make Permanent Modifications below).

#### Howto login: other Methods

##### Login via Monitor and Keyboard
This is probably the method people are most familiar with: attach a monitor to the HDMI port of the haxophone, a USB keyboard, and you are in. On the Zeros, this normally requires a micro-USB to USB adapter. This is not the most portable setup, as not everyone carries a monitor in their pocket.




##### Login via Serial Port

This requires a USB to 3.3V TTL adapter.  The most popular brand is
[FTDI](https://ftdichip.com/products/ttl-232r-3v3/), but there are many other
alternatives you can use.  

The Haxophone has a 3-pin header that exposes the Raspberry Pi serial port. The pinout matches that of the Raspberry Pi header, so if you prepare a cable for the Haxophone, you can also use it to connect directly to any Raspberry Pi.



You need to connect your cable's TxD to the Raspberry Pi RxD and your cable's RxD to the Rasperry Pi TxD.  If you are using an FTDI cable, this is how the colors line up.



Once you do that, you can use a serial terminal program to connect.  For instance, `minicom`.



#### Checking the Logs

Probably the most important log that you want to check is the one for the haxophone service.
You can do that with the command 

```
journalctl -u haxo
```

See below for the expected output:

```
pi@haxophone:~ $ journalctl -u haxo
-- Boot 9ecd1d956b6448adb9348f40065fbd4f --
Jan 05 22:38:47 haxophone systemd[1]: Started haxophone.
Jan 05 22:38:52 haxophone create_midi_gadget.sh[468]: created usb midi gadget
Jan 05 22:38:52 haxophone haxo001[570]: fluidsynth: warning: SDL2 not initialized, SDL2 audio driver won't be usable
Jan 05 22:38:52 haxophone haxo001[570]: [2024-01-05T22:38:52Z INFO  haxo001::alsa] Found alsa card MAX98357A
Jan 05 22:39:01 haxophone haxo001[570]: Synth created
Jan 05 22:39:02 haxophone haxo001[570]: [2024-01-05T22:39:02Z INFO  haxo001::midi]
Jan 05 22:39:02 haxophone haxo001[570]:     Available output ports:
Jan 05 22:39:02 haxophone haxo001[570]: [2024-01-05T22:39:02Z INFO  haxo001::midi] 0: Midi Through:Midi Through Port->
Jan 05 22:39:02 haxophone haxo001[570]: [2024-01-05T22:39:02Z INFO  haxo001::midi] 1: f_midi:f_midi 24:0
Jan 05 22:39:02 haxophone haxo001[570]: [2024-01-05T22:39:02Z INFO  haxo001::midi] Picked the last one
Jan 05 22:39:02 haxophone haxo001[570]: Starting haxophone (version 2493652)...
```

#### Howto Make Permanent Modifications
Now that you logged in successfully to your haxophone you are prepared to make your first changes.

1. Login to the haxophone as described above

2. Disable overlay file system
On the haxophone issue the following command:
```
sudo raspi-config
```
The Raspberry Pi Software Configuration Tool is started:



There you select the menu Performance Options (using the up and down keys and press enter to select):



Next you choose the menu Overlay File System:



In the next dialog you choose Enable Overlay? NO:



Then you press enter and the following confirmation message is shown:



Then again press enter and another confirmation message is shown:



Again press enter. The main menu is shown. Here you move to the finish button using the tab key:



After pressing enter the confirmation for reboot is shown:



You select the option Yes and the haxophone will reboot. The shell shows that the connection to the haxophone was closed:

```
update-initramfs: Deleting /boot/initrd.img-6.1.21+-overlay
Connection to haxophone.local closed by remote host.
Connection to haxophone.local closed.
```

2. After reboot: do the changes: (for other examples see [advanced hacking](#advanced-hacking))

As a first example we change the default instrument used by the haxophone

First step: make a copy of the original settings:
```
sudo cp /etc/systemd/system/haxo.service  /home/pi/haxo.service.backup
```

Next edit the haxo.service file:
```
sudo nano /etc/systemd/system/haxo.service
```

This shows the file using the editor nano:



Here change the part that says --prog-number 66 to  --prog-number 73 to get the flute sound after reboot instead of the default tenor sax sound:

```
ExecStart=/usr/local/bin/haxo001 \
          --notemap-file /usr/share/haxo/notemap.json \
          --prog-number 73 \
          --sf2-file /usr/share/sounds/sf2/TimGM6mb.sf2
```

Exit the nano dialog with CTRL-X and save the changes.
Now reboot the haxophone:
```
sudo reboot
```

Now the haxophone startup using the flute sound!

3. When finished: enable the overlay file system again
Start the Raspberry Pi Software Configuration Tool:

```
sudo raspi-config
```

Go again to Performance Options, then select Overlay filesystem and press enter. The following confirmation dialog is shown:



Select yes and press enter.
The generating takes some time, this is shown while generating the overlay file system:

```
update-initramfs: Generating /boot/initrd.img-6.1.21+
```

When done with generating the overlay file system, the following confirmation message is shown:



Press the enter key and proceed to the next confirmation dialog. Here we keep the default setting and root write protection with no:



Another confirmation message tells you that the boot partition is kept writable:



After that exit the configuration tool using finish. 
The haxophone will reboot.

#### The File haxo.service explained
As a first example what we can change on the haxophone we have a look at the haxo.service file. You can find it on your haxophone in the path  /etc/systemd/system/haxo.service

Have a look at the file:

```
pi@haxophone:~ $ cat /etc/systemd/system/haxo.service 
[Unit]
Description=haxophone
After=network.target
StartLimitIntervalSec=0

[Service]
Type=idle
Restart=always
RestartSec=1
User=root
Group=audio
WorkingDir=/usr/share/haxo
Environment=RUST_LOG=info
ExecStartPre=/usr/local/bin/create_midi_gadget.sh
ExecStart=/usr/local/bin/haxo001 \
          --notemap-file /usr/share/haxo/notemap.json \
          --prog-number 66 \
          --sf2-file /usr/share/sounds/sf2/TimGM6mb.sf2 
[Install]
WantedBy=multi-user.target
```

The part that is interesting for first hacks is the following:

```
ExecStart=/usr/local/bin/haxo001 \
          --notemap-file /usr/share/haxo/notemap.json \
          --prog-number 66 \
          --sf2-file /usr/share/sounds/sf2/TimGM6mb.sf2 
```

The haxophone softeware consists of the binary haxo001 program that can be started with different options:

* **--notemap-file** here you set the path to the notemap.json file that the haxophone uses (see [Change the notemap.json](#howto-notemap.json))

* **--prog-number** with this option you select the default instrument that is played when the haxophone is started. 66 is the default tenor sax. You can change it for example to 73 you get the flute sound. (see [list of haxophone sounds](#haxophone-sounds) and use the value of preset)

* add \ after TimGM6mb.sf2 and  **--transpose 0** in a new line to change the default transposition offset for a flute (Remark: for transpose to work you need to install the newest binary)

### Advanced Hacking

#### Install the Newest Binary
To get the newest haxo001-rpiz.zip file do the following steps:

1. Login to github (otherwise you can not download the artifact)
2. Open [https://github.com/cardonabits/haxo-rs/actions](https://github.com/cardonabits/haxo-rs/actions)

    

    And select the newest Raspberry Pi Zero Compilation run.

3. Download the artifact: Click on haxo001-rpiz and get the haxo001-rpiz.zip file

    

4. Connect via ssh and disable overlay, reboot ([see disable overlay filesystem](#disable-overlay-filesystem))

5. Stop the haxo service

    ```
    sudo systemctl stop haxo
    ```
6. Unzip the file on your local pc or laptop and use scp to copy it to the haxophone:

    ```
    cp haxo001 pi@haxophone.local:/home/pi/haxo001_new
    ```
6. Log in to the haxophone ([see howto login](#howto-login)) and save the original version of haxo001:

    ```
    sudo cp  /usr/local/bin/haxo001 haxo001.orig
    ```
7. Then replace it with the new version:

    ```
    sudo cp haxo001_new /usr/local/bin/haxo001
    ```
8. Reboot

    ```
    sudo reboot
    ```

9. Re-enable overlay ([see enable overlay filesystem](#enable-overlay-filesystem))

#### Howto Change the Sound Set
If you want to change the sound set entirely, you’ll need to:

* Install a new sound font file on the haxophone filesystem, under /usr/share/sounds/sf2/
* Modify /etc/systemd/system/haxo.service to load your new sound font instead of the one loaded by default.

#### Howto Change the notemap.json
If you want to change the notemap.json, e.g. add some more or alternative fingerings to the existing fingerings, use the following steps:

1. First, find your acutal notemap.json file. This is the original file:
[https://raw.githubusercontent.com/cardonabits/haxo-rs/main/notemap.json](https://raw.githubusercontent.com/cardonabits/haxo-rs/main/notemap.json)

2. Go to [https://haxo-notemap.nn.r.appspot.com/](https://haxo-notemap.nn.r.appspot.com/) and load your notemap.json file:

   

3. Use the up and down buttons to navigate to the note of which you want to change the fingering:

   

4. Select one existing fingering you want to modifiy:

   

5. Click on the blue keys to add or remove a fingering position:

   

6. When finished editing the fingering for this note click on "Save Fingering":

   

7. You will notice that the number of alternate fingerings has increased:

   

8. When finished editing, click on "Donwload notemap.json" and save the file on your computer

9. Connect via ssh to your haxophone and disable overlay, reboot ([see disable overlay filesystem](#disable-overlay-filesystem))

10. Login to your haxophone and stop the haxo service

    ```
    sudo systemctl stop haxo
    ```

11. On another shell on your computer: Copy the new notemap.json to your haxophone:

    ```
    scp notemap.json pi@haxophone.local:/home/pi
    ```
   and then on the haxophone copy it to the correct location via sudo cp:

    ```
pi@haxophone:~ $ sudo cp notemap.json /usr/share/haxo/
    ```
   
    or modify /etc/systemd/system/haxo.service to point to your new notemap

    ```
     --notemap-file /usr/share/haxo/notemap.json \
    ```

12. Re-enable overlay and reboot ([see enable overlay filesystem](#enable-overlay-filesystem))

#### The non-existent Shutdown command

Some time ago there existed a [shutdown command](https://github.com/cardonabits/haxo-rs/commit/9a9a84b224fc8a8fe0d9163508b1aee2d814d735) but it was removed as it was easy to trigger accidentally while playing.
Now that we have more robust method to enter Command Mode that is much harder to trigger accidentally, maybe we should bring back the shutdown command.  If you want it, feel free to open an issue, or even better, a Pull Request.

## Appendix

### Haxophone Cheat Sheet
Here is a cheat sheet for the haxophone ([or cheatsheet as pdf](./cheatsheet.pdf)):



This cheat sheet for the haxophone already explains the transpose mode, this feature is actually not included in the software image. You have to install the newest version of the haxophone software. More about this in another chapter, but the work there is still in progress.

### Haxophone Sounds

The default Haxophone image is configured to load the ubiquitous TimGM6mb.sf2 sound set developed by Tim Brechbill. The default sound set has 136 instrument sounds (presets) to choose from. As expected, the Haxophone boots into a tenor sax sound (66) by default. 

For an explanation how to switch between the sounds see [Choose a Sound](#choose-sound)

    Piano 1 (Preset: 0, Bank: 0, Preset bag: 187)
    Standard (Preset: 0, Bank: 128, Preset bag: 18)
    Piano 2 (Preset: 1, Bank: 0, Preset bag: 186)
    Piano 3 (Preset: 2, Bank: 0, Preset bag: 184)
    Honky Tonk (Preset: 3, Bank: 0, Preset bag: 182)
    E.Piano 1 (Preset: 4, Bank: 0, Preset bag: 180)
    E.Piano 2 (Preset: 5, Bank: 0, Preset bag: 179)
    Harpsichord (Preset: 6, Bank: 0, Preset bag: 178)
    Clavinet (Preset: 7, Bank: 0, Preset bag: 177)
    Celesta (Preset: 8, Bank: 0, Preset bag: 176)
    Room (Preset: 8, Bank: 128, Preset bag: 16)
    Glockenspiel (Preset: 9, Bank: 0, Preset bag: 175)
    MusicBox (Preset: 10, Bank: 0, Preset bag: 174)
    Vibraphone (Preset: 11, Bank: 0, Preset bag: 173)
    Marimba (Preset: 12, Bank: 0, Preset bag: 172)
    Xylophone (Preset: 13, Bank: 0, Preset bag: 168)
    Tubular Bells (Preset: 14, Bank: 0, Preset bag: 167)
    Dulcimer (Preset: 15, Bank: 0, Preset bag: 165)
    Organ 1 (Preset: 16, Bank: 0, Preset bag: 164)
    Power (Preset: 16, Bank: 128, Preset bag: 13)
    Organ 2 (Preset: 17, Bank: 0, Preset bag: 163)
    Organ 3 (Preset: 18, Bank: 0, Preset bag: 161)
    Church Organ (Preset: 19, Bank: 0, Preset bag: 159)
    Reed Organ (Preset: 20, Bank: 0, Preset bag: 157)
    Accordion (Preset: 21, Bank: 0, Preset bag: 155)
    Harmonica (Preset: 22, Bank: 0, Preset bag: 154)
    Bandoneon (Preset: 23, Bank: 0, Preset bag: 152)
    Electronic (Preset: 24, Bank: 128, Preset bag: 11)
    Nylon Guitar (Preset: 24, Bank: 0, Preset bag: 151)
    Steel Guitar (Preset: 25, Bank: 0, Preset bag: 150)
    TR 808 (Preset: 25, Bank: 128, Preset bag: 8)
    Jazz Guitar (Preset: 26, Bank: 0, Preset bag: 149)
    Clean Guitar (Preset: 27, Bank: 0, Preset bag: 148)
    Guitar Mutes (Preset: 28, Bank: 0, Preset bag: 147)
    Overdrive Guitar (Preset: 29, Bank: 0, Preset bag: 145)
    DistortionGuitar (Preset: 30, Bank: 0, Preset bag: 143)
    Guitar Harmonics (Preset: 31, Bank: 0, Preset bag: 142)
    Acoustic Bass (Preset: 32, Bank: 0, Preset bag: 141)
    Jazz (Preset: 32, Bank: 128, Preset bag: 6)
    Fingered Bass (Preset: 33, Bank: 0, Preset bag: 140)
    Picked Bass (Preset: 34, Bank: 0, Preset bag: 139)
    Fretless Bass (Preset: 35, Bank: 0, Preset bag: 138)
    Slap Bass 1 (Preset: 36, Bank: 0, Preset bag: 137)
    Slap Bass 2 (Preset: 37, Bank: 0, Preset bag: 136)
    Synth Bass 1 (Preset: 38, Bank: 0, Preset bag: 135)
    Synth Bass 2 (Preset: 39, Bank: 0, Preset bag: 133)
    Brush (Preset: 40, Bank: 128, Preset bag: 4)
    Violin (Preset: 40, Bank: 0, Preset bag: 132)
    Viola (Preset: 41, Bank: 0, Preset bag: 131)
    Cello (Preset: 42, Bank: 0, Preset bag: 130)
    Contrabass (Preset: 43, Bank: 0, Preset bag: 129)
    Strings (Tremelo) (Preset: 44, Bank: 0, Preset bag: 208)
    Pizzicato (Preset: 45, Bank: 0, Preset bag: 128)
    Harp LP (Preset: 46, Bank: 0, Preset bag: 127)
    Timpani (Preset: 47, Bank: 0, Preset bag: 126)
    Orchestra (Preset: 48, Bank: 128, Preset bag: 1)
    Strings CLP (Preset: 48, Bank: 0, Preset bag: 202)
    Slow Strings LP (Preset: 49, Bank: 0, Preset bag: 197)
    Synth Strings 1 (Preset: 50, Bank: 0, Preset bag: 195)
    Synth Strings 2 (Preset: 51, Bank: 0, Preset bag: 124)
    Choir Aahs (Preset: 52, Bank: 0, Preset bag: 192)
    Voice Oohs (Preset: 53, Bank: 0, Preset bag: 122)
    Synth Vox (Preset: 54, Bank: 0, Preset bag: 121)
    Orchestra Hit (Preset: 55, Bank: 0, Preset bag: 119)
    SoloTrumpet (Preset: 56, Bank: 0, Preset bag: 118)
    Trombone (Preset: 57, Bank: 0, Preset bag: 117)
    Tuba (Preset: 58, Bank: 0, Preset bag: 116)
    Mute Trumpet (Preset: 59, Bank: 0, Preset bag: 115)
    French Horns (Preset: 60, Bank: 0, Preset bag: 107)
    Brass (Preset: 61, Bank: 0, Preset bag: 114)
    Synth Brass 1 (Preset: 62, Bank: 0, Preset bag: 112)
    Synth Brass 2 (Preset: 63, Bank: 0, Preset bag: 111)
    SopSax (TB) v2.3 (Preset: 64, Bank: 0, Preset bag: 191)
    AltoSax (TB) v2.3 (Preset: 65, Bank: 0, Preset bag: 190)
    Tenor Sax (TB) v2.3 (Preset: 66, Bank: 0, Preset bag: 189)
    BariSax (TB) v2.3 (Preset: 67, Bank: 0, Preset bag: 188)
    Oboe (Orch) (Preset: 68, Bank: 0, Preset bag: 106)
    English Horn (Preset: 69, Bank: 0, Preset bag: 105)
    Bassoon (Preset: 70, Bank: 0, Preset bag: 104)
    Clarinet (Preset: 71, Bank: 0, Preset bag: 103)
    Piccolo (Preset: 72, Bank: 0, Preset bag: 102)
    Flute TB (Preset: 73, Bank: 0, Preset bag: 0)
    Recorder (Preset: 74, Bank: 0, Preset bag: 101)
    Pan Flute (Preset: 75, Bank: 0, Preset bag: 100)
    Bottle Chiff (Preset: 76, Bank: 0, Preset bag: 98)
    Shakuhachi (Preset: 77, Bank: 0, Preset bag: 97)
    Whistle (Preset: 78, Bank: 0, Preset bag: 96)
    Ocarina (Preset: 79, Bank: 0, Preset bag: 95)
    Square Wave (Preset: 80, Bank: 0, Preset bag: 93)
    Saw Wave (Preset: 81, Bank: 0, Preset bag: 91)
    Synth Calliope (Preset: 82, Bank: 0, Preset bag: 89)
    Chiffer Lead (Preset: 83, Bank: 0, Preset bag: 87)
    Charang (Preset: 84, Bank: 0, Preset bag: 85)
    Solo Vox (Preset: 85, Bank: 0, Preset bag: 83)
    5th Saw Wave (Preset: 86, Bank: 0, Preset bag: 81)
    Bass & Lead (Preset: 87, Bank: 0, Preset bag: 79)
    Fantasia (Preset: 88, Bank: 0, Preset bag: 76)
    Warm Pad (Preset: 89, Bank: 0, Preset bag: 75)
    Poly Synth (Preset: 90, Bank: 0, Preset bag: 73)
    Space Voice (Preset: 91, Bank: 0, Preset bag: 71)
    Bowed Glass (Preset: 92, Bank: 0, Preset bag: 69)
    Metal Pad (Preset: 93, Bank: 0, Preset bag: 67)
    Halo Pad (Preset: 94, Bank: 0, Preset bag: 65)
    Sweep Pad (Preset: 95, Bank: 0, Preset bag: 63)
    IceRain (Preset: 96, Bank: 0, Preset bag: 62)
    Soundtrack (Preset: 97, Bank: 0, Preset bag: 60)
    Crystal (Preset: 98, Bank: 0, Preset bag: 58)
    Atmosphere (Preset: 99, Bank: 0, Preset bag: 56)
    Brightness (Preset: 100, Bank: 0, Preset bag: 54)
    Goblin (Preset: 101, Bank: 0, Preset bag: 52)
    Echo Drops (Preset: 102, Bank: 0, Preset bag: 50)
    Star Theme (Preset: 103, Bank: 0, Preset bag: 48)
    Sitar (Preset: 104, Bank: 0, Preset bag: 47)
    Banjo (Preset: 105, Bank: 0, Preset bag: 46)
    Shamisen (Preset: 106, Bank: 0, Preset bag: 45)
    Koto (Preset: 107, Bank: 0, Preset bag: 44)
    Kalimba (Preset: 108, Bank: 0, Preset bag: 43)
    Bagpipe (Preset: 109, Bank: 0, Preset bag: 41)
    Fiddle (Preset: 110, Bank: 0, Preset bag: 40)
    Shenai (Preset: 111, Bank: 0, Preset bag: 39)
    Tinker Bell (Preset: 112, Bank: 0, Preset bag: 38)
    Agogo (Preset: 113, Bank: 0, Preset bag: 37)
    Steel Drum (Preset: 114, Bank: 0, Preset bag: 36)
    Wood Block (Preset: 115, Bank: 0, Preset bag: 35)
    Taiko Drum (Preset: 116, Bank: 0, Preset bag: 34)
    Melodic Tom (Preset: 117, Bank: 0, Preset bag: 33)
    Synth Drum (Preset: 118, Bank: 0, Preset bag: 32)
    Reverse Cymbal (Preset: 119, Bank: 0, Preset bag: 31)
    Fret Noise (Preset: 120, Bank: 0, Preset bag: 30)
    Breath Noise (Preset: 121, Bank: 0, Preset bag: 28)
    Seashore (Preset: 122, Bank: 0, Preset bag: 27)
    Bird (Preset: 123, Bank: 0, Preset bag: 26)
    Telephone (Preset: 124, Bank: 0, Preset bag: 25)
    Helicopter (Preset: 125, Bank: 0, Preset bag: 24)
    Applause (Preset: 126, Bank: 0, Preset bag: 22)
    Gun Shot (Preset: 127, Bank: 0, Preset bag: 20)

### Troubleshooting / FAQ
1. Which Raspberry Pi should I use? Pi Zero is quite fine, but the Zero W or Pi 3 or Pi 4 work, too.
2. Which mouthpiece should I use? The neck is 16mm in diameter, which works with some alto mouthpieces and all tenor mouthpieces, if you add a bit of washi tape for a snug fit. Do not buy an expensive mouthpiece! In contrast to a real saxophone, the mouthpiece you choose will have no effect on sound quality on the haxophone. If you have a specific mouthpiece you want to use that does not fit, you can always modify and print [another neck](https://github.com/cardonabits/haxo-hw/blob/main/models/neck-neck.stl)!

3. How to turn off the haxophone? Just remove power, as the SD card is read only. Some time ago there existed a [key combination to trigger the shutdown](https://github.com/cardonabits/haxo-rs/commit/9a9a84b224fc8a8fe0d9163508b1aee2d814d735). It was removed, because it was no longer needed (SD card read only) and you could accidentially trigger the shutdown during playing.

### Links and Resources
* [https://www.crowdsupply.com/cardona-bits/haxophone](https://www.crowdsupply.com/cardona-bits/haxophone)
* [https://lightnote.cardonabits.com/products/haxophone-as-a-kit](https://lightnote.cardonabits.com/products/haxophone-as-a-kit)
* [https://github.com/cardonabits/haxo-hw](https://github.com/cardonabits/haxo-hw)
* [https://github.com/cardonabits/haxo-rs](https://github.com/cardonabits/haxo-rs)
* [https://haxo-notemap.nn.r.appspot.com/](https://haxo-notemap.nn.r.appspot.com/)
* [https://www.sebulli.com/haxo/notemap/](https://www.sebulli.com/haxo/notemap/)
* [https://www.ssh.com/academy/ssh/keygen](https://www.ssh.com/academy/ssh/keygen)
* [https://www.windtabmusic.com/free-area-tenor-sax ](https://www.windtabmusic.com/free-area-tenor-sax)

### Caring for the Haxophone
1. **Vent Tubes Cleaning:**
   Regularly clear the vent tubes on the haxophone by blowing dry air through them or using appropriately sized pipe cleaners.

2. **Surface Moisture Removal:**
   Use a dry cloth to wipe off any moisture that accumulates on the surface of the haxophone.

### Safety Information

1. **Proper Power Supply Connection:**
   ALWAYS power up the haxophone by connecting a USB-compliant power supply to the Raspberry Pi USB power port. DO NOT apply voltage in any other way.

2. **Mouth Insertion Warning:**
   DO NOT insert any part of the haxophone into your mouth except the tip of the neck or the mouthpiece, if you are using one.

3. **Device Condition Alert:**
   If the haxophone shows any signs of damage, emits acrid smells, or exhibits mold growth, STOP USING the device immediately for safety reasons.

| Document Version | Changes |
| 0.1 | First version |
| 0.2 | Added more information |
| 0.3 | Added howto shutdown  |
| 0.4 | Some small additions and corrections  |

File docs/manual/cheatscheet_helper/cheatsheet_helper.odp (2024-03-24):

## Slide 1

Command Mode

enter command mode:
press low Bb and draw air

leave command mode:

Press all three palm keys

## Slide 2

When in command mode: scroll through the sounds

+1

-1

+10

-10

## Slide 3

Transpose Mode

enter transpose mode:
Press low B and draw air

leave transpose mode:

Press all three palm keys

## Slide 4

When in transpose mode: select transpose key

play E flat and blow air

play B flat and blow air

play high C and

blow air

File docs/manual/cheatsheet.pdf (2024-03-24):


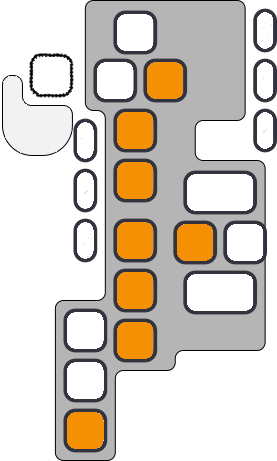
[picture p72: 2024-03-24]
docs/manual/cheatscheet_helper/keys/keys_transposemode_enter.png

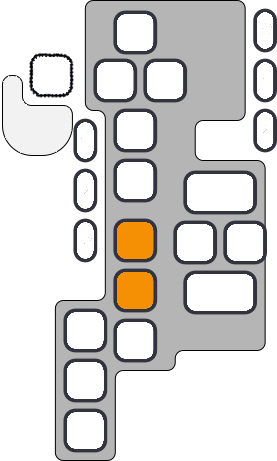
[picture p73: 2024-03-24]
docs/manual/cheatscheet_helper/keys/keys_scroll_sounds_up_10.png

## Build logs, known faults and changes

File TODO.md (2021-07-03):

Footprint for audio jack
Audio codec placement and routing

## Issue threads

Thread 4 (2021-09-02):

Test powering up the haxophone out of a USB   powerbank and document results

jcard0na, 2021-09-02:
Test powering up the haxophone out of a [USB powerbank](https://www.nytimes.com/wirecutter/reviews/best-usb-battery-packs/) and document results.

jcard0na, 2021-09-30:
Powered up successfully for several hours with 10000MAh generic USB power bank (5V / 2.4A).

jcard0na, 2023-04-17:
Another user has reported success powering their haxophone with a [UPS-Lite](https://www.aliexpress.com/item/32961105269.html?spm=a2g0o.order_list.order_list_main.101.19701802HB2g5t).

Closed 2021-09-30.

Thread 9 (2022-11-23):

Share BOM, CPL, gerber files for easier JLCPCB ordering

cedricium, 2022-11-23:
Hiya! Came across this project after seeing it on Hacker News and immediately wanted to order everything to make one myself. Unfortunately I don't have access to KiCad and therefore am unable to follow what seems like the most crucial step of getting started: ordering all the parts and PCB.

Would love if the output of the `ordering_process.md` guide (zipped gerbers, CPL, and BOM files) could be shared as part of this repository so ordering was easier. (Or better yet, maybe start a Tindie store to order the PCBs.)

For inspiration, The Open Book shares these files: https://github.com/joeycastillo/The-Open-Book/tree/main/eBook%20Feather%20Wing

jcard0na, 2022-11-30:
Good suggestion and thanks for the link.
I'll share the fabrication files this week.  As for Tinder, I need to read up on that.  I'm not looking to manage inventory, returns, etc. so I'd only take that route if they handle that.

cedricium, 2022-11-30:
The fab files would be more than enough, thank you kindly. Can't wait to get build one of my own!

jcard0na, 2022-12-01:
I have checked in the fabrication files [here](https://github.com/jcard0na/haxo-hw/tree/main/builds)
The good news is that when I dry-run an order with JLPCB, all the components seem to be in stock.  You can order 5 boards for ~200 USD, or $40 per board.  Of that price, a full $22 go to the pressure sensor, a part that was $8 when I started the project!.

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

This version of the board is different from the one I built, as I had to swap the parts that were difficult to source.  Also, I moved to the latest version of Kicad, which also required a few tweaks to the design.  In other words, **THESE ARE NOT THE EXACT SAME FABRICATION FILES I USED AND THERE IS A NON NEGLIGIBLE CHANCE THAT THE BOARD DOES NOT WORK FOR YOU**.  Please only order if you enjoy challenging projects that you can make your own.

I'll close this issue now.  If you end up ordering, feel free to open a new issue so I can support you with board bring up.  You could also open an issue to try and pool 5 or more people together to place an order with JLCPCB as 5 is the minimum quantity.

Cheers!

Closed 2022-12-01.

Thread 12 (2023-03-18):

Promotion

schef, 2023-03-18:
Hi, I'm from the band Scifidelity Orchestra. I would like to integrate the instrument into the show. Would you sacrifice one for the promotion? :)

jcard0na, 2023-03-18:
Hi schef,

I don't really have any spare haxophones...  Your current options to get one are:
1. Wait for the crowd supply campaign and order one there: https://www.crowdsupply.com/cardona-bits/haxophone
2. Join [this discussion](https://github.com/jcard0na/haxo-hw/discussions/10) with the people who want to pool together to order their own batch of PCBs and build their own.

Best,
Javier

schef, 2023-03-18:
Thanks for the fast anwser!

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

Closed 2023-03-18.

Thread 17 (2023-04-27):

Getting haxo001 to start

ddodge40, 2023-04-27:
### Discussed in https://github.com/jcard0na/haxo-hw/discussions/7

<div type='discussions-op-text'>

<sup>Originally posted by **jcard0na** November  9, 2021</sup>
<!--
    ✏️ Optional: Customize the content below to let your community know what you intend to use Discussions for.
-->
## 👋 Welcome!
  We’re using Discussions as a place to connect with other members of our community. We hope that you:
  * Ask questions you’re wondering about.
  * Share ideas.
  * Engage with other community members.
  * Welcome others and are open-minded. Remember that this is a community we
  build together 💪.

  To get started, comment below with an introduction of yourself and tell us about what you do with this community.

<!--
  For the maintainers, here are some tips 💡 for getting started with Discussions. We'll leave these in Markdown comments for now, but feel free to take out the comments for all maintainers to see.

  📢 **Announce to your community** that Discussions is available! Go ahead and send that tweet, post, or link it from the website to drive traffic here.

  🔗 If you use issue templates, **link any relevant issue templates** such as questions and community conversations to Discussions. Declutter your issues by driving community content to where they belong in Discussions. If you need help, here's a [link to the documentation](https://docs.github.com/en/github/building-a-strong-community/configuring-issue-templates-for-your-repository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).

  ➡️ You can **convert issues to discussions** either individually or bulk by labels. Looking at you, issues labeled “question” or “discussion”.
-->
</div>

ddodge40, 2023-04-27:
In getting my Saxophone to start, i had issues with no sound.
After reviewing the startup, i found that haxo-service was not loading and when i forced a start there were issues.

on the line --notemap-file, it pointed to a non existent directory haxo  by adding the -rs, it now points to the haxo-rs directory.

on the line --sf2.-file., the file TenorSax2.sf2 does not exist,  by changing to the TimGM6mb.sf2, I can now get sounds.
Some of the keys do not work.

Where can I get the TenorSax2.sf2 file?

jcard0na, 2023-04-28:
Hi @ddodge40,

1. Regarding keys.  You can run the `all_keys` test described in https://github.com/jcard0na/haxo-rs#testing to see if you have problems with the keys.  If so, make sure you clean the board well:  solder [flux can wreak havoc](https://github.com/jcard0na/haxo-hw/blob/main/docs/assembly.md#general-advice).

Also, it could be that the fingering is not what you expect.  You can check the haxophone default fingering [here](https://haxo-notemap.nn.r.appspot.com/).  You can also use that site to generate customized fingerings.

2. Regarding TenorSax2.sf2 file, see https://github.com/jcard0na/haxo-rs/issues/10  On the thread linked there, there's this link: https://www.dropbox.com/s/uytrgjt19i8y9qd/SAXOPHONES.7z?dl=0  I got the file from that link, although I did not check it in because I don't know the license situation regarding redistribution.

ddodge40, 2023-04-29:
I ran all of the tests and they all pass including the air pressure test.
Do I need to have a different notemap file for each sf2 file?

Don Dodge
Cell 714-271-7888
W6SNX

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

jcard0na, 2023-04-29:
Hi @ddodge40,

I pointed out the `all_keys` test because you mentioned problems with some keys not working.  That test is disabled by default because it cannot be run automatically;  you need to give it the `--ignored` flag.  Can you provide more detail of " Some of the keys do not work"?  Could it be that you expect each key to emit a sound?  Can you get a low Bb? and a mid C#? If so, that is not how a sax works.  (Sorry if that is obvious to you, I don't know how familiar you are with saxophone fingerings.)

Regarding the notemap file, no, no need to have a different one per sf2 file.  The notemap file just maps fingerings to notes, and the sf2, provides the sounds for each note.

Cheers,

ddodge40, 2023-04-30:
I separated the pi from the board and checked all the switches with my Fluke meter and they checked out with no problem.  Now suspecting the old pi.  I had used it for other projects and may have damaged it.  I have a new one and will try it.

Thanks for the help.

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

Donald Dodge
***@***.***
W6SNX
Cell 714-271-7888

jcard0na, 2023-05-01:
Hi @ddodge40

Some more thoughts...

> I ran all of the tests and they all pass

Just to confirm, does that include the `all_keys` test which needs to be enabled via the `--ignored` flag?
That test checks **all the keys** of the haxophone, so if it passes, I doubt you have a hardware problem.

>  Some of the keys do not work.

Can you describe the problem in more detail?  For instance, can you explain what key combinations do not work using the key names from [this keyboard diagram](https://github.com/jcard0na/haxo-hw#keyboard)?  e.g. "col0:row2 +  col0:row3  does not make any sound" (that combination should sound like A on a Bb tenor, or concert G)

> Now suspecting the old pi

I've had one rpi fail where a few GPIOs would be stuck high.  But again, the `all_keys` test was failing on that device.

Seems like you are very close... 😃

ddodge40, 2023-05-01:
Yes i did run the individual key test and noticed that some keys created more than  1 X on the patern.

When i checked the pi without the board.  One GPIO was stuck at ground, and would not release.

Trying another pi this week.

Thanks

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

Donald Dodge
***@***.***
W6SNX
Cell 714-271-7888

ddodge40, 2023-05-10:
Attempted to do a recompile using my new pi and rust version 1.69.0 and get the following error close to the end of the compiling.  Is it a typo somewhere?  it is looking for lfluidsynth?

Thanks

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

Donald Dodge
***@***.***
W6SNX
Cell 714-271-7888

  = note: /usr/bin/ld: cannot find -lfluidsynth
          collect2: error: ld returned 1 exit status

error: could not compile `haxo001` due to previous error

jcard0na, 2023-05-10:
Yes, make sure you install the binary and the development libraries:

https://github.com/jcard0na/haxo-rs#package-dependencies

jcard0na, 2023-05-31:
@ddodge40 Is this issue still unresolved?

jcard0na, 2023-06-20:
Hi @ddodge40

I was just debugging a similar problem on a friend's haxophone and noticed that the latest `fluidsynth` is having problems loading the soundfont file I've been using (`TenorSax2.sf2`).

This is the haxo output (`journalctl -u haxo`):
```
fluidsynth: warning: SDL2 not initialized, SDL2 audio driver won't be usable
fluidsynth: warning: Failed to set thread to high priority
fluidsynth: warning: No preset found on channel 0 [bank=0 prog=0]
fluidsynth: warning: No preset found on channel 1 [bank=0 prog=0]
fluidsynth: warning: No preset found on channel 2 [bank=0 prog=0]
fluidsynth: warning: No preset found on channel 3 [bank=0 prog=0]
fluidsynth: warning: No preset found on channel 4 [bank=0 prog=0]
fluidsynth: warning: No preset found on channel 5 [bank=0 prog=0]
fluidsynth: warning: No preset found on channel 6 [bank=0 prog=0]
fluidsynth: warning: No preset found on channel 7 [bank=0 prog=0]
fluidsynth: warning: No preset found on channel 8 [bank=0 prog=0]
fluidsynth: warning: No preset found on channel 9 [bank=128 prog=0]
fluidsynth: warning: No preset found on channel 10 [bank=0 prog=0]
fluidsynth: warning: No preset found on channel 11 [bank=0 prog=0]
fluidsynth: warning: No preset found on channel 12 [bank=0 prog=0]
fluidsynth: warning: No preset found on channel 13 [bank=0 prog=0]
fluidsynth: warning: No preset found on channel 14 [bank=0 prog=0]
fluidsynth: warning: No preset found on channel 15 [bank=0 prog=0]
fluidsynth: warning: No preset found on channel 0 [bank=0 prog=0]
Synth created
Starting haxophone...
```
And no sound.

When I use the same font file directly with `fluidsynth` and a [sample midi file](https://bitmidi.com/uploads/111850.mid), I also get no sound.

```
fluidsynth -a alsa /usr/share/sounds/sf2/TenorSax.sf2 111850.mid
FluidSynth runtime version 2.1.7
Copyright (C) 2000-2021 Peter Hanappe and others.
Distributed under the LGPL license.
SoundFont(R) is a registered trademark of E-mu Systems, Inc.

fluidsynth: warning: No preset found on channel 0 [bank=0 prog=0]
fluidsynth: warning: No preset found on channel 1 [bank=0 prog=0]
fluidsynth: warning: No preset found on channel 2 [bank=0 prog=0]
fluidsynth: warning: No preset found on channel 3 [bank=0 prog=0]
fluidsynth: warning: No preset found on channel 4 [bank=0 prog=0]
fluidsynth: warning: No preset found on channel 5 [bank=0 prog=0]
fluidsynth: warning: No preset found on channel 6 [bank=0 prog=0]
fluidsynth: warning: No preset found on channel 7 [bank=0 prog=0]
fluidsynth: warning: No preset found on channel 8 [bank=0 prog=0]
fluidsynth: warning: No preset found on channel 9 [bank=128 prog=0]
fluidsynth: warning: No preset found on channel 10 [bank=0 prog=0]
fluidsynth: warning: No preset found on channel 11 [bank=0 prog=0]
fluidsynth: warning: No preset found on channel 12 [bank=0 prog=0]
fluidsynth: warning: No preset found on channel 13 [bank=0 prog=0]
fluidsynth: warning: No preset found on channel 14 [bank=0 prog=0]
fluidsynth: warning: No preset found on channel 15 [bank=0 prog=0]
fluidsynth: warning: Failed to set thread to high priority
Type 'help' for help topics.

> fluidsynth: warning: Failed to set thread to high priority
```
and also no sound.

I'm reverting back to a better supported sound font that is already distributed as a debian package for the raspberry pi

```
dpkg -S /usr/share/sounds/sf2/TimGM6mb.sf2
timgm6mb-soundfont: /usr/share/sounds/sf2/TimGM6mb.sf2
```

With this font, fluidsynth can play the sample midi without errors:
```
fluidsynth -a alsa /usr/share/sounds/sf2/TimGM6mb.sf2 111850.mid
```
and the haxophone works as well

```
cargo run --release -- --sf2-file /usr/share/sounds/sf2/TimGM6mb.sf2  --bank-number 66
```

Note that you need to select `bank-number` 66, which corresponds to tenor sax preset on that file:

```
sf2text /usr/share/sounds/sf2/TimGM6mb.sf2 | grep Tenor | grep bank
 (128 "Tenor Sax (TB) v2.3" (preset 66) (bank 0) (
```

jcard0na, 2023-06-20:
Not sure if this is the same issue you are facing, but the symptoms seem to match.  Let me know if you finally can get this to work.

jcard0na, 2023-08-06:
Hi @ddodge40,

Were you able to resolve this?

ddodge40, 2023-08-06:
Not yet.  We are in the middle of of moving to Kirkland WA and am just loading software on a new pi zero.Don DodgeCell 714-271-7888W6SNXOn Aug 6, 2023, at 1:24 PM, Javier Cardona ***@***.***> wrote:
Hi @ddodge40,
Were you able to resolve this?

—Reply to this email directly, view it on GitHub, or unsubscribe.You are receiving this because you were mentioned.Message ID: ***@***.***>

jcard0na, 2023-09-25:
Hi @ddodge40,
Where you able to resolve this?

ddodge40, 2023-09-26:
Not yet. We sold our home in HUNTINGTON BEACH and moved to Kirkland WA. No time to try yetThanksDon DodgeCell 714-271-7888W6SNXOn Sep 25, 2023, at 11:11 AM, Javier Cardona ***@***.***> wrote:
Hi @ddodge40,
Where you able to resolve this?

—Reply to this email directly, view it on GitHub, or unsubscribe.You are receiving this because you were mentioned.Message ID: ***@***.***>

jcard0na, 2024-01-08:
Hi, closing this for housekeeping.  Feel free to re-open if you ever face this problem again.

Cheers,

Closed 2024-01-08.

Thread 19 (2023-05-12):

Raspberry Pi alternative solutions

Woovie, 2023-05-12:
Hello!

I really want to build one of these, but it's damn near impossible to find in stock Raspberry Pi's from my searching. Would the RP2040 suffice? If so, I'd love to have a design that supports this instead purely for the sake of actually obtaining one in a timeframe sub 1 year.

I've done some relatively minor PCB designs in my time and could probably hack the idea together, but I'm unfamiliar with the viability here.

Thanks

jcard0na, 2023-05-15:
Hi @Woovie ,

The RP2040 cannot replace a Raspberri Pi in the haxophone, at least in the current design where we synthesize sounds with fluidsynth.
That said, you are not limited to just the Pi Zero:  you can also use the Pi Zero W, the RPi3 or the RPi4.  The last two are a bit of extra weight and more expensive, but give you a good development environment, in case you want to extend/modify the software on the haxophone.
Cheers,

By the way, this is a good site to look for Raspberry Pi inventory: https://rpilocator.com/

Woovie, 2023-05-16:
I appreciate it. Good point on fluidsynth, I didn't look at that close enough. I'll hunt down a Pi then, thank you!

Closed 2023-05-16.

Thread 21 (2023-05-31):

Corrupt 3d files

mikenturner, 2023-05-31:
Hi
I've tried a number of 3d printing services and they are reporting that the .stl files are either corrupt or that processing fails.  I tried the .step files as well,
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
 and if they get processed they report that the volume is too low for printing,.  See a couple of screenshots as examples.
Mike

jcard0na, 2023-05-31:
Hi Mike,

For 3D printing you need to use the `.stl` file, not `.step`.
I just tested Sculpteo and impressao3dportugal.com and the files are loaded correctly.

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

```
md5 *.stl
MD5 (hook_rest-Part.stl) = 22d6e1990d6d020719939e806fbd390a
MD5 (neck-neck.stl) = 9ed0153b7fa52ee1ccf8f4bf9de990f8
MD5 (octave_rest-Part.stl) = 5782e400a41bb528da39ed18cb579046
```

jcard0na, 2023-05-31:
Excellent!   Thanks for confirming that it worked.

Closed 2023-05-31.

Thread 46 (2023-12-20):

Write a proper manual for the Haxophone

jcard0na, 2023-12-20:
There is a lot of information about the Haxophone dispersed across [Discussions](https://github.com/cardonabits/haxo-hw/discussions), [Issues](https://github.com/cardonabits/haxo-hw/issues), the [docs directory](https://github.com/cardonabits/haxo-hw/tree/main/docs), the [Crowd Supply campaign page](https://www.crowdsupply.com/cardona-bits/haxophone) and ultimately [the source code](https://github.com/cardonabits/haxo-rs).

But there is no proper Manual.  We probably need to write one.

Utopiah, 2024-01-04:
I'd happily act as a guinea pig on this. What as a newcomer who just received the device expects :

1. how to play the first note as easily as possible (pretty much https://github.com/cardonabits/haxo-hw/blob/main/docs/Quick%20Start%20Postcard.pdf )
2. how to connect to other stuff, e.g MIDI
3. how to customize in standalone mode, e.g change sounds, key mapping, etc

Utopiah, 2024-01-05:
I'd also add SBCs (broadly, cf https://github.com/cardonabits/haxo-hw/issues/19 ) support grid with RPi Zero highlighted as of right now (early January 2024) best supported one (which features specified, i.e MIDI USB, audio out?, no HW bug with HDMI port contact on line out, etc) with clarification on pins required (as unlike others sold with and without pins) but not RPi 2/3/4/5 or Zero 2W (cf https://github.com/cardonabits/haxo-hw/issues/53 and others, WiP AFAIK). Ideally this sorted grid would remain up to date so that newcomers and know right away if what they have can be used, what should work and if no what they should get.

Utopiah, 2024-01-11:
Why there is no reason to turn off the device (i.e real-only SD) https://github.com/cardonabits/haxo-rs/commit/9a9a84b224fc8a8fe0d9163508b1aee2d814d735 and also customization by fingering example.

stardusthamster, 2024-02-25:
Hi,

I would like to help with the manual.
Which option do you prefer:
1. create a big manual.md file in the doc folder and use the same image folder as the existing doc
2. or create a separate manual folder in the doc folder containing one or more .md files for the manual and an extra image folder

jcard0na, 2024-02-25:
Thanks for offering to help!  Given that you'll be doing this, pick whatever format makes you happier.  Full creative freedom ahead 🧑‍🎨

stardusthamster, 2024-03-24:
Here is my first version of the manual:
https://github.com/cardonabits/haxo-hw/pull/79

Utopiah, 2024-06-18:
Could be interesting to make the manual an explorable explanation, relying on MIDI mode, ideally with no install so via the Web, e.g https://webmidi-abc-chromatone.glitch.me/haxo.html

stardusthamster, 2025-02-23:
This is the last issue and pull request to finish the parts of the manual that I planned to write: https://github.com/stardusthamster/haxo-hw/issues/4

So, whats still missing?
imho the midi part is missing, there has been a discussion here
https://github.com/cardonabits/haxo-rs/discussions/21

I don't know much about midi and I am sorry that I can't help here...

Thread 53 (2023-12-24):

I want to use haxophone with Raspberry Pi Zero 2 W

hisayan, 2023-12-24:
I want to use haxophone with Raspberry Pi Zero 2 W (not Zero).

I tried using disk image for Zero.
https://bit.ly/haxo-rpiz
but It didn't work.

I tried using the disk image for Raspberry Pi 3.
https://bit.ly/haxo-rpi3
It worked well.

Is there any problem with this?

There may be others who have similar problems, so I'm here to let you know.

jcard0na, 2023-12-24:
Hi Tomoyuki,

Thanks for letting us know!  I've had preparing an image for the Pi Zero 2 on my TODO list but have not found the time to do it yet.  I suspected that the RPi3 image would work based on the fact that they are both based on the same Cortex-A53 CPU, but never tested it.

And now you have 😄 Thank you!

> Is there any problem with this?

The only problem that you will have is that the image I released for the Pi3 [https://bit.ly/haxo-rpi3](https://bit.ly/haxo-rpi3) does not run the latest version of haxo-rs.  In particular you are missing USB Midi support and the startup chime that plays after boot.

If you are inclined to hacking, I recommend that you try to [build the latest version](https://github.com/cardonabits/haxo-hw/blob/main/docs/development.md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) yourself.  Regardless of that,   I'll update the released image for the RPi3 (and now also Zero 2) after the holidays (I'm currently traveling with my Haxophone, but without a Pi Zero 2)

Thanks, and happy haxophoning!

cc: @pomalaterre

jcard0na, 2024-01-05:
See #66

Closed 2023-12-24.

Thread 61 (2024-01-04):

Line out missing

Utopiah, 2024-01-04:
Hi, just received my haxophone via CrowdSupply. Looks neat but I'm wondering if the line out is supposed to be like that :

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

Should I solder it back? Can I use it without thanks to e.g RPi jack out anyway?

Edit : seems others had a similar problem, cf https://www.crowdsupply.com/cardona-bits/haxophone/updates/orders-fulfilled-code-info-and-feature-requests

Utopiah, 2024-01-04:
Alternatively I have an Akai Pro MPK Mini mkII, could I use it as described in  "USB MIDI output (only on Raspberry Pi Zero). Connect the Haxophone to a MIDI synth over USB and use it as a regular MIDI instrument." and if so how, "just" plugging in RPi Zero USB?

Utopiah, 2024-01-04:
No worries it happens. I'm not great at soldering if it's those 3 points and not too heat sensitive I might manage. Worth a try and if it fails I fallback to CrowdSupply, what do you think?

PS: thanks for the MIDI pointer, I'll try with LMMS on Linux, worked with the Akay before.

jcard0na, 2024-01-04:
> No worries it happens. I'm not great at soldering if it's those 3 points and not too heat sensitive I might manage. Worth a try and if it fails I fallback to CrowdSupply, what do you think?

Great.  Yes, that part is easy to solder.   And from the picture you posted, there does not seem to be any damage to the pad.  If you have soldering flux, soldering would be even easier, but that is not a hard requirement.  Just remember to wipe it out when finished.  Let me know how it goes! 🤞

Utopiah, 2024-01-04:
> does this MIDI example work with the RPi 3 image too?

seems not, cf "I released for the Pi3 https://bit.ly/haxo-rpi3 does not run the latest version of haxo-rs. In particular you are missing USB Midi support " in https://github.com/cardonabits/haxo-hw/issues/53#issuecomment-1868456613

jcard0na, 2024-01-04:
I forgot to answer that second question, but looks like you found your answer 😎
You might find [this discussion](https://github.com/cardonabits/haxo-hw/discussions/47) interesting.  Some people are interested in getting Midi working on the RPi 3/4 with a USB MIDI adapter.  But that features is just at the early discussion stage.  If you want USB MIDI now you should stick with the Zero.

BTW, as you saw on [the latest update](https://www.crowdsupply.com/cardona-bits/haxophone/updates/orders-fulfilled-code-info-and-feature-requests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), you are not alone with the line-out problem.  And your attitude has been just as good.  Thank you! 🙏

Utopiah, 2024-01-05:
No sound on keypress but I hear static coming out of headphones so... a good step?

Will plug HDMI to get some logs.

Utopiah, 2024-01-05:
Well I'm getting a haxophone login prompt. I imagine I should try to investigate with `journalctl`? Maybe try to play sound with `fluidsynth`?

jcard0na, 2024-01-05:
Hi @Utopiah,

Soldering looks acceptable, probably the upper pad could use a bit more solder.  I suppose static is OK, but if you did not get a startup chime, that's not ok.

The default login is user:`pi` pwd:`haxophone`, yes.

Yes, `journalctl -u haxo` should be the starting point to understand.  If there are no software issues, then it's the hardware that is damaged.

Playing a sound is easy:
```
sudo systemctl stop haxo
aplay /usr/share/sounds/alsa/Front_Right.wav
```
`ssh` or serial console is what I normally use to debug.

Utopiah, 2024-01-05:
I'm connected via `ssh` and getting

```
pi@haxophone:~ $ aplay /usr/share/sounds/alsa/Front_Right.wav
aplay: main:830: audio open error: Device or resource busy
```

and from `journalctl -u haxo`

getting

```
pi@haxophone:~ $ journalctl -u haxo
-- Journal begins at Tue 2023-10-03 13:33:03 BST, ends at Fri 2024-01-05 17:37:29 GMT. --
Oct 03 13:33:08 haxophone systemd[1]: Started haxophone.
Oct 03 13:33:14 haxophone haxo001[456]: fluidsynth: warning: SDL2 not initialized, SDL2 audio driver won't be usable
Oct 03 13:33:14 haxophone haxo001[456]: [2023-10-03T12:33:14Z WARN  haxo001::synth] Setting audio.driver in fluidsynth failed
Oct 03 13:33:14 haxophone haxo001[456]: [2023-10-03T12:33:14Z WARN  haxo001::synth] Setting audio.periods in fluidsynth failed
Oct 03 13:33:14 haxophone haxo001[456]: [2023-10-03T12:33:14Z WARN  haxo001::synth] Setting audio.period-size in fluidsynth failed
Oct 03 13:33:14 haxophone haxo001[456]: [2023-10-03T12:33:14Z WARN  haxo001::synth] Setting audio.realtime-prio in fluidsynth failed
Oct 03 13:33:14 haxophone haxo001[456]: Synth created
Oct 03 13:33:14 haxophone haxo001[456]: Starting haxophone...
Oct 03 13:35:17 haxophone systemd[1]: Stopping haxophone...
Oct 03 13:35:17 haxophone systemd[1]: haxo.service: Succeeded.
Oct 03 13:35:17 haxophone systemd[1]: Stopped haxophone.
Oct 03 13:35:17 haxophone systemd[1]: haxo.service: Consumed 43.222s CPU time.
-- Boot 05d669daf1be4739b93ec351fc294a2c --
Oct 03 13:35:23 haxophone systemd[1]: Started haxophone.
Oct 03 13:35:29 haxophone haxo001[455]: fluidsynth: warning: SDL2 not initialized, SDL2 audio driver won't be usable
Oct 03 13:35:29 haxophone haxo001[455]: [2023-10-03T12:35:29Z WARN  haxo001::synth] Setting audio.driver in fluidsynth failed
Oct 03 13:35:29 haxophone haxo001[455]: [2023-10-03T12:35:29Z WARN  haxo001::synth] Setting audio.periods in fluidsynth failed
Oct 03 13:35:29 haxophone haxo001[455]: [2023-10-03T12:35:29Z WARN  haxo001::synth] Setting audio.period-size in fluidsynth failed
Oct 03 13:35:29 haxophone haxo001[455]: [2023-10-03T12:35:29Z WARN  haxo001::synth] Setting audio.realtime-prio in fluidsynth failed
Oct 03 13:35:29 haxophone haxo001[455]: Synth created
Oct 03 13:35:29 haxophone haxo001[455]: Starting haxophone...
Oct 03 13:35:43 haxophone systemd[1]: Stopping haxophone...
Oct 03 13:35:43 haxophone systemd[1]: haxo.service: Succeeded.
Oct 03 13:35:43 haxophone systemd[1]: Stopped haxophone.
Oct 03 13:35:43 haxophone systemd[1]: haxo.service: Consumed 5.391s CPU time.
Oct 03 13:55:13 haxophone systemd[1]: Started haxophone.
Oct 03 13:55:13 haxophone haxo001[779]: fluidsynth: warning: SDL2 not initialized, SDL2 audio driver won't be usable
Oct 03 13:55:13 haxophone haxo001[779]: [2023-10-03T12:55:13Z INFO  haxo001::alsa] Found alsa card MAX98357A
Oct 03 13:55:13 haxophone haxo001[779]: Synth created
Oct 03 13:55:13 haxophone haxo001[779]: [2023-10-03T12:55:13Z INFO  haxo001::midi] Choosing the only available midi output port: Midi Through:Midi Through Port-0 14:0
Oct 03 13:55:13 haxophone haxo001[779]: Starting haxophone...
Oct 03 13:57:16 haxophone systemd[1]: Stopping haxophone...
Oct 03 13:57:17 haxophone systemd[1]: haxo.service: Succeeded.
Oct 03 13:57:17 haxophone systemd[1]: Stopped haxophone.
Oct 03 13:57:17 haxophone systemd[1]: haxo.service: Consumed 45.273s CPU time.
-- Boot 6d6e45b5fd1b4ecd981a839eb84d3553 --
Oct 03 13:57:22 haxophone systemd[1]: Started haxophone.
Oct 03 13:57:28 haxophone haxo001[461]: fluidsynth: warning: SDL2 not initialized, SDL2 audio driver won't be usable
Oct 03 13:57:28 haxophone haxo001[461]: [2023-10-03T12:57:28Z INFO  haxo001::alsa] Found alsa card MAX98357A
Oct 03 13:57:28 haxophone haxo001[461]: Synth created
Oct 03 13:57:29 haxophone haxo001[461]: [2023-10-03T12:57:29Z INFO  haxo001::midi] Choosing the only available midi output port: Midi Through:Midi Through Port-0 14:0
Oct 03 13:57:29 haxophone haxo001[461]: Starting haxophone...
Oct 03 14:05:25 haxophone systemd[1]: Stopping haxophone...
Oct 03 14:05:25 haxophone systemd[1]: haxo.service: Succeeded.
Oct 03 14:05:25 haxophone systemd[1]: Stopped haxophone.
Oct 03 14:05:25 haxophone systemd[1]: haxo.service: Consumed 3min 5.823s CPU time.
Oct 03 14:05:35 haxophone systemd[1]: Started haxophone.
Oct 03 14:05:35 haxophone haxo001[837]: fluidsynth: warning: SDL2 not initialized, SDL2 audio driver won't be usable
Oct 03 14:05:35 haxophone haxo001[837]: [2023-10-03T13:05:35Z INFO  haxo001::alsa] Found alsa card MAX98357A
Oct 03 14:05:35 haxophone haxo001[837]: Synth created
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
Utopiah, 2024-01-06:
Unfortunately I don't have any stripped minijack but the piece itself, the jack-to-connector, looks pretty clean from what I can see.

Anyway I appreciate a lot your help but this seems to be beyond my hardware ability so I contacted CrowdSupply for RMA. Hopefully you can investigate and learn from the source of the problem.

In the meantime though, because I assume it will take a while and I'm quite excited by the project, I would really like to tinker more. I don't mind if there is some input lag, or even mono, so what do you believe would be the most practical path to get some sound of it it as-is?

Could it be

- via BT, cf https://github.com/cardonabits/haxo-hw/issues/64 ?
- via the RPi3 or 4 jack output?

Sadly all the RPi Zero I have (2x v1 and 1x v2) are without pins so I can't use them. I'll look for connector because I might have a set somewhere, if so then I could at least tinker with the hardware I have now before the RMA as a MIDI device for LMMS, or even XR as I did some prototypes about that in the past for pedagogical exploration.

jcard0na, 2024-01-06:
Hi @Utopiah

Yes, it seems like an RMA is the sensible approach now.

Just so I understand where we stand...

The logs you sent seem to indicate the haxo application starts successfully.
And you confirmed that you have audio out of one channel with `aplay`.

Were you ever able to play the haxophone and hear audio?  At a minimum, blowing through the neck should play a concert `B` note.

Oh, wait...

> Sadly all the RPi Zero I have (2x v1 and 1x v2) are without pins so I can't use them.

...but earlier on you asked about the RPi Zero and then the RPi3.  Which RPi are you using?

(If the RPi3, you should be aware of #37 and the proposed workaround)

Utopiah, 2024-01-06:
RPi3 and sadly I did cover with some tape before even trying. I might use more tape or even a thin piece of plastic, maybe it was still conductive somehow.

Now... don't laugh (or cry) but... I pressed button because I was thinking piano, I didn't blow in at the same time! :D

I just put back the setup and... it works! Namely when I blow in AND press keys, I can hear sound, even in both headphone sides (no idea how come). When I do press keys though it doesn't change the note except sometimes while pressing column 2 key 1 (the light pink one on my setup).

It looks like RMA might not be needed after all, what do you think? How could I run a proper diagnosis from here?

jcard0na, 2024-01-06:
:exploding_head: :

> Now... don't laugh (or cry) but... I pressed button because I was thinking piano, I didn't blow in at the same time! :D

:rofl:  Actually this is a documentation error... Instead of just `7. Play`, the last step in the [Quick Start guide](https://github.com/cardonabits/haxo-hw/blob/main/docs/Quick%20Start%20Postcard.pdf) should explain that blowing air is required :wind_face:  I'll make that change!

The next step would be to go over [all the fingerings](https://www.sebulli.com/haxo/notemap/), and noting which ones do not work (if any).  One player had [an issue with a key](https://github.com/cardonabits/haxo-hw/discussions/56) that was stuck open, and it was fixed just by trying all the fingerings.  Maybe you are experiencing something similar?

jcard0na, 2024-01-06:
Oh, and yes, hold on the RMA for now until we've tried all the fingerings.

Utopiah, 2024-01-06:
Luckily for us both it's the weekend so RMA is paused for now. I was even able to make a tiny chambre concert to amazed guests. A single note was tricky but the crowd was enthusiastic so ... concert approved!

Jokes aside I'll go through the fingerings and comment back, eager to see where this all goes but admittedly now the limiting factor is my skill! (and yes to be blunt also documentation but we can solve that easily through discussions and issues)

jcard0na, 2024-01-06:
Thanks for your patience and perseverance in working through all the kinks!

jcard0na, 2024-01-08:
Closing this, as it seems like you have resolved the issue.  Thanks!

Closed 2024-01-08.

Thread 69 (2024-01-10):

How to turn off the device?

Utopiah, 2024-01-10:
For now I unplug the power but... I don't feel "clean" about doing it, even though I don't write anything (AFAIK) back on the microSD. So I'm wondering if there is already a "proper" way to turn the device off, e.g a hidden physical button or an impossible fingering?

jcard0na, 2024-01-10:
I implemented this a while back in commit 9a9a84b224fc8a8fe0d9163508b1aee2d814d735 but then removed it after we made the SD card read-only (and also after an embarrassing shut down incident while playing in public... 😊 ).  If that can make you feel "cleaner" 🧼 we could bring it back.  Feel free to [open a poll](https://github.com/cardonabits/haxo-hw/discussions/new?category=polls) and see what people say.

Utopiah, 2024-01-11:
Ah! Well easier question, is it written somewhere in the documentation? If no then adding it would be enough and this issue would be closed.

I would also add a paragraph in the documentation using this as the typical customization example, namely defining a function doing something, e.g shutdown here, binded to a specific fingering.

jcard0na, 2024-01-11:
> is it written somewhere in the documentation?
Nope 😅

jcard0na, 2024-01-11:
BTW, thanks for adding this to [the-issue-that-is-slowly-becoming-the-missing-manual](https://github.com/cardonabits/haxo-hw/issues/46) 😄

stardusthamster, 2024-07-01:
I am adding it to the manual.

Closed 2024-06-18.

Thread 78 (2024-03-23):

No tunes below D

Domi1l, 2024-03-23:
Hello there,

First, I'd like to say that this project is very nice!

I'm new to the saxophone game and have never played an instrument before. I've been learning the saxophone for almost 4 months now, and my neighbors hate me :-P. So, I was searching for a solution to practice the saxophone after midnight, and I found it in the Haxophone. Thank you very much for this!

I'm very satisfied with the Haxophone, but I'm not able to play the notes from Bb3 to D. Am I doing something wrong? Actually, I'm not able to connect a keyboard to my Raspberry Pi to see if all the keys work. Maybe there is another solution until I get my USB adapter?

I also tried to change the instrument sounds; that also doesn't work for me.

Maybe you have an idea how to fix this at the moment.

Thank you very much for this great Projekt

Cheers

jcard0na, 2024-03-23:
Hi @Domi1l,

Thanks for the kind words, and I'm really sorry you can't get those notes to play.  Let's see if can solve this...
To narrow it down, are these the notes that do not sound?  Are you trying these same fingerings?

https://haxo-notemap.nn.r.appspot.com/?midinote=62  (D)
https://haxo-notemap.nn.r.appspot.com/?midinote=61  (C#)
https://haxo-notemap.nn.r.appspot.com/?midinote=60  (C)
https://haxo-notemap.nn.r.appspot.com/?midinote=59  (B)
https://haxo-notemap.nn.r.appspot.com/?midinote=58  (Bb)

How about low Eb?  Does it work?
https://haxo-notemap.nn.r.appspot.com/?midinote=63

If it does not, it could be that the keyswitch for L3 (col 1, row 7, https://github.com/cardonabits/haxo-hw/blob/main/docs/images/fingering-matrix.png) is not closing.
However, if D works but Eb does not, I don't think this could be a faulty keyswitch.

BTW, what Raspberry variant are you using?

Cheers,

Domi1l, 2024-03-23:
Hey Javier, thanks for your fast respose :-)

so the Notes:

[https://haxo-notemap.nn.r.appspot.com/?midinote=62](url) (D) is playing
[https://haxo-notemap.nn.r.appspot.com/?midinote=63](url) (Eb) is playing

https://haxo-notemap.nn.r.appspot.com/?midinote=61 (C#) not playing
https://haxo-notemap.nn.r.appspot.com/?midinote=60 (C) not playing (only the tune D is playing)
https://haxo-notemap.nn.r.appspot.com/?midinote=59 (B) not playing
https://haxo-notemap.nn.r.appspot.com/?midinote=58 (Bb) not playing

Im using an Raspberry Pi Zero W V1.1.
I also measured the single keys with an Multimeter to be sure that the circute is closing when im pressing the Button. That works well. Actually i dont know much songs with that kind of Low Notes, so im not in a Hurry :-D. Every other Note works just fine.

Thank you

jcard0na, 2024-03-23:
Hi @Domi1l

This really helps:

> https://haxo-notemap.nn.r.appspot.com/?midinote=62 (D) is playing
> (...)
> https://haxo-notemap.nn.r.appspot.com/?midinote=60 (C) not playing (only the tune D is playing)

The symptoms seems to point to key C (col 0, row 6 https://github.com/cardonabits/haxo-hw/blob/main/docs/images/fingering-matrix.png) not working.  Can you inspect this area of the haxophone?  Maybe look for damage, broken traces, missing D23 diode, poor/missing solder on the switch or any other reason for it not making contact.  Any of those failures would explain this behavior.

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

Let me know if you discover something 🤞 .

Best,

Domi1l, 2024-03-24:
WOW!

Thank you very much Javier! The D23 Dioide is missing. Unfortunatly the circute Board i bought wasn't that good soldered. I have to resolder 2 diodes before i get even startet :-D. Im not an expert with electrical devices, can you give me a hint which kind of diod i have to buy to solve this Problem? I tried by myself but im not able to figure out.

Thank you very much for your fast and good help.

jcard0na, 2024-03-24:
Hi @Domi1l

Nice to have it narrowed it down to a single diode.  Any surface mount diode with SOD-123 footprint will work.
There are many, many alternatives:  https://octopart.com/search?q=diode+sod-123

BTW, where did you order the board from?  I'll make sure not to order from them... :yum:

Domi1l, 2024-03-24:
I can't tell you where the PCB is from.  I ordered from Ebay. I think the seller ordered a bunch of PCB's to get a cheaper price and sell it to others who also want to build a Haxophone. Thank you again for your Help. Have a nice Day!

Domi1l, 2024-03-26:
I soldered a new diode to D23. Now it works like a charm. Thank you again. That was so much Fun to build :-)

Closed 2024-03-26.

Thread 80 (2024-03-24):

Make the tube longer

StaffanMelin, 2024-03-24:
I am afraid that spit from the tube will get on my Raspberry Pi 4. One simple solution is to angle the tube to one side.

Or make it longer?
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

jcard0na, 2024-03-24:
I normally angle it to one side, actually the opposite side than you show on the picture so that it can be held in place by the right thumb rest.

StaffanMelin, 2024-04-18:
Yeah, I saw that you mentioned this in the build instructions! :)

Closed 2024-04-18.

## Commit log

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2021-05-06 First iteration of PCB
    [haxophone001-B_Cu.gbr, haxophone001-B_Mask.gbr, haxophone001-Edge_Cuts.gbr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]
2021-05-18 Clean up silkscreen
    [haxophone001.kicad_pcb]
2021-05-19 use breakout tabs instead of testpoint hack
    [haxophone001.sch]
2021-05-21 Move diodes to back and v0.4
    [haxophone001.dsn, haxophone001.kicad_pcb]
2021-05-22 Move mounting holes to align with Raspberry Pi
    [haxophone001.kicad_pcb]
2021-05-22 Clear USB ports
    [haxophone001.kicad_pcb]
2021-05-23 Remove zero lenght edge cut
    [haxophone001.kicad_pcb]
2021-06-05 Fix swapped pins in LHP connector
    Also, rename RHP to RHK.
    Fix swapped connector sides in schematic (noop in schematic)
    [haxophone001.kicad_pcb, haxophone001.sch]
2021-06-06 Added neck
    Replaced 40pos connector with 4
    [haxophone001.dsn, haxophone001.kicad_pcb, haxophone001.sch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]
2021-06-06 Neck Through Hole
    [neck-neck.step, neck.FCStd]
2021-06-06 Mounting hole adjustments and dimensions
    [haxophone001.kicad_pcb]
2021-06-13 Eliminate octave key island and move button to backside
    [haxophone001.dsn, haxophone001.kicad_pcb, haxophone001.sch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]
2021-06-13 Regenerate gerbers
    [haxophone001.kicad_pcb]
2021-06-17 Add keycaps to switch model
    [cherry-mx-with-keycap.FCStd, haxophone001.kicad_pcb]
2021-06-24 Zones under L-brackets
    Also, fix order of LHP buttons
    [haxophone001.kicad_pcb, haxophone001.sch]
2021-06-24 Use padded mounting holes on RHK and LHP
    [haxophone001.kicad_pcb, haxophone001.sch]
2021-06-24 Rerouted
    Moved L-Bracket zones to the back side
    Added no-fills to RHK and LHP sides as well.
    [haxophone001.dsn, haxophone001.kicad_pcb]
2021-06-24 Manual track tweaks around edges
    [haxophone001.kicad_pcb]
2021-06-25 Add mounting holes for thumb hook
    [haxophone001.kicad_pcb, haxophone001.sch]
2021-06-25 Add third HAT mounting hole
    [haxophone001.kicad_pcb]
2021-06-25 Update label to haxo v0.5
    [haxophone001.kicad_pcb]
2021-06-28 Curve RHP keys
    [haxophone001.kicad_pcb]
2021-07-03 Added thumb rests
    Model right and left thumb rests.
    Add thumb rest kicad footprint.
    [cherry-mx-with-2U-keycap.FCStd, haxophone001.kicad_pcb, haxophone001.sch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]
2021-07-03 Improve thumb rests
    [haxophone001.kicad_pcb, hook_rest-Part.step, hook_rest.FCStd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]
2021-07-03 Added audio codec
    [haxophone001.sch]
2021-07-04 Route audio codec
    Also, step models for audio jack and oscillator
    [3225 SMD Crystal Oscillator.STEP, C18166-Part.step, C18166.FCStd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]
2021-07-06 Ready to order v0.5
    [haxophone001.kicad_pcb, haxophone001.sch]
2021-07-06 Modified origin and orientation of audio jack footprint
    [haxophone001.kicad_pcb]
2021-07-08 Fix DRC error after moving audio jack
    [haxophone001.kicad_pcb]
2021-07-08 Added loop for neck strap
    Use WRL model for hook 3D model to workaround a freecad/opencascade bug
    exporting fused parts to STEP models.
    https://dev.opencascade.org/content/boolean-fuse-operation-step-export-issue-brepalgoapifuse-stepcafcontrolwriter
    [haxophone001.kicad_pcb, hook_rest-Part.step, hook_rest.FCStd]
2021-07-08 Swapped codec
    Replace WM8988 codec with MAX98357 amp: less components and more power.
    [haxophone001.dsn, haxophone001.kicad_pcb, haxophone001.sch]
2021-07-09 Added MAX98357 LCSC part number
    [haxophone001.sch]
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2021-08-20 Better renders and images
    Created model for pressure sensor.
    New renders.
    Added missing fingering-matrix.png image.
    [cherry-mx-with-keycap.FCStd, haxophone001.kicad_pcb, hook_rest-Part.step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]
2021-08-27 Change UART connector to match of Raspberry header
    This allows using the same cable to connect to the HAT and to the raw
    header.
    [haxophone001.sch]
2021-09-01 Add new 3d model for pressure sensor
    [hook_rest-Part.stl, mpxv7007-Part.step, mpxv7007.FCStd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]
2021-09-01 Moved thumb rests for easier assembly
    Positioned thumb rests so that screws are accessible from the front side
    without having to unsolder key switches.
    Also, update 3d models.
    [haxophone001.kicad_pcb]
2021-09-01 Increase diameter of thumb rest positioning hole
    1.6 mm would break easily on 3d printed parts. Increased to 2.4mm
    [hook_rest-Part.step, hook_rest.FCStd, octave_rest-Part.step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]
2021-09-01 Mounting hole for Raspberry Pi Zero
    Add a mounting hole for Raspberry Pi Zero.
    Also, increase the diameter of Raspberry Pi Zero mounting holes so we
    can use the same 4/40 screws used in L-brackets.
    Re-route serial port connector.
    [haxophone001.kicad_pcb, haxophone001.sch]
2021-09-06 Use wrl model for thumb hook
    The .step version of that model does not render correctly. Switch to the
    .wrl model.
    [haxophone001.kicad_pcb]
2021-09-06 Fixed swapped columns in BOM
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2021-09-06 Updated neck 3D model
    Fixed collision between screw hole and air pipes.
    Adjusted screw holes for 4-40 1/4 in screws.
    [neck.FCStd]
2021-09-09 Fix octave button orientation
    [haxophone001.kicad_pcb]
2021-09-09 Update version number to v1.0
    When opening with newer kicad, some libraries were updated.
    [haxophone001.kicad_pcb, haxophone001.sch]
2021-09-09 Generate STL models for printing
    [hook_rest-Part.stl, neck-neck.step, neck-neck.stl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]
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2021-11-01 Some additional info and small corrections for the assembly doc (#5)
    Update assembly.md
2021-11-01 Fix typo in assembly.md (#6)
2021-11-02 Use JLCPCB instead of LCSC part labels
    JLCPCB parts are different than LCSC. Use JLCPCB label to identify
    JLCPCB part numbers.
    [haxophone001.sch]
2021-11-02 Migrate schematic to use new Kicad libraries
    This will avoid the rescue dialog when opening the schematic with newer
    Kicad versions.
    [haxophone001.kicad_pcb, haxophone001.sch]
2021-11-02 Swap audio jack connector
    Swap audio jack connector to PJ-3280-B-SMT. JLCPCB recommended this
    part as it will be kept in stock long term.
    [haxophone001.kicad_pcb, haxophone001.sch]
2021-11-02 Swap through-hole connectors for parts carried by JLCPCB
    JLCPCB does hand soldering of through hole parts. Pick connectors that
    they carry in stock and add them to the BOM and positioning file.
    This required swaping the gender of the 4-pos connectors used to
    attach the side key subassemblies.
    [haxophone001.dsn, haxophone001.kicad_pcb, haxophone001.sch]
2021-11-02 fixup: Add model files for previous commit
    [PJ-3280-B-SMT-Part.step, PJ-3280-B-SMT.FCStd]
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2022-12-01 Update to kicad 6.0 and release fabrication files
    * Remove references to rescue symbol library
    * Update project to kicad 6.0
    * Fix board clearances reported by (more strict?) design rules checker
    in kicad 6.0
    * Remove non smd parts from positioning file
    * Update 2x2 connector gender and audio jack.
    These parts had changed due to inventory constraints. After
    updating to kicad 6.0 the changes were lost, but the footprints were
    already routed. Update the schematic to match these new parts.
    * Generate fabrication files for #009
    [haxophone001-bom-1.0.csv, haxophone001.kicad_pcb, haxophone001.kicad_sch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]
2023-08-03 Update instructions_safety_en.md
    Added shortened download link for Raspberry Pi Zero
    Removed TODO for Raspberry Pi 3,4
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2023-08-06 Update development.md
    Document problem with rust installation on Raspberry Pi 4
2023-09-07 README: fixup: case sensitivity in second license-related link (#30)
2023-09-15 Added CE mark to back silkscreen
    [haxophone001.kicad_pcb]
2023-09-15 Revert back to previous audio connector
    Revert back to audio connector C18594 from Boomele after receiving a
    defect report for the part used in version 1.0.1. This connector
    was out of stock during Covid but now is well stocked.
    [haxophone001.kicad_pcb, haxophone001.kicad_sch]
2023-09-15 Add Alternate pressure sensor part
    [haxophone001-bom-1.1.csv, haxophone001.kicad_pcb, haxophone001.kicad_sch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]
2023-09-15 Fix interference between L3 and 40-pin con
    Shift 40-pin conn by 4mm to resolve interference with L3 keyswitch.
    This adds 4mm to board length.
    [haxophone001.kicad_pcb]
2023-09-15 Recall botch build files
    [haxophone001-bom-1.1.csv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]
2023-09-15 Remove useless silkcreen tag
    [haxophone001.kicad_pcb]
2023-09-22 Migrate to Kicad 7
    [haxophone001.kicad_sch]
2023-09-22 Fix all DRC errors raised by new kicad version (7.0)
    Remove OSHW footprint until we can resolve the DRC problems it
    introduces.
    [haxophone001.kicad_pcb, haxophone001.kicad_sch]
2023-09-22 Added back OSHW logo
    [haxophone001.kicad_pcb]
2023-09-23 Lock everything
    [haxophone001.kicad_pcb]
2023-09-23 Resolve interference of diode with thumb rest
    [haxophone001.kicad_pcb]
2023-09-23 Exclude Mx8 (octave key) from position file
    [haxophone001.kicad_pcb]
2023-09-23 Swap cap that was out of stock
    [haxophone001.kicad_sch]
2023-09-23 Fix BOM generation script for LCSC parts
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2023-10-03 Tweaks to OSHW logo
    [haxophone001.kicad_pcb]
2023-10-12 Connect MAX98357a SD_MODE pin to GPIO4
    SD_MODE pin can be used to eliminate start-up pop
    GPIO4 seems to be the default pin according to
    https://github.com/raspberrypi/linux/blob/rpi-6.1.y/arch/arm/boot/dts/overlays/max98357a-overlay.dts
    See cardonabits/haxo-rs#17
    [haxophone001.kicad_pcb, haxophone001.kicad_sch]
2023-10-12 Version bump to 1.1.1
    [haxophone001.kicad_pcb, haxophone001.kicad_sch]
2023-10-16 Add external pull-up resistors to COL lines
    The Raspberry Pi has 50k-60k internal pull-up resistors on GPIOs. While this
    is working correctly on a clean board, those values are a bit weak in the
    presence of leakage paths which may appear in the presence of dirt and
    humidity. Increase the immunity to PCB leakage paths by adding lower
    resistance (10k) external pull-up resistors.
    [haxophone001.kicad_pcb, haxophone001.kicad_sch]
2023-10-16 Small tweaks to 3D printed parts for better fit
    - Reduce diameter of rests centering hole
    - Widen L-bracket notch
    [hook_rest-Part.stl, hook_rest.FCStd, neck-neck.stl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]
2023-11-11 Fix incorrect cap part 1uF -> 0.1uF
    [haxophone001.kicad_sch]
2023-11-12 Fixup: Use the right foogprint for C2
    The previous commit fixed the cap value, but introduced the wrong
    capacitor size, 0402. Correct this by selecting a 0603 cap for C2.
    [haxophone001.kicad_sch]
2023-12-20 Fix gain selection documentation label
    [haxophone001.kicad_sch]
2024-01-08 Build files for 1.1.1
    [haxophone001-bom-1.1.1.csv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]
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
